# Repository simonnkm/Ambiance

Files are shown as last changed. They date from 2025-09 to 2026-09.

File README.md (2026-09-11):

# Ambiance

Ambiance is a solar-powered scheduled audio playback system built around an STM32 Nucleo development board. The system is designed for remote outdoor use and supports scheduled playback of audio tracks through a speaker system.

The project includes embedded firmware, a desktop GUI, hardware documentation, PCB manufacturing files, and assembly materials.

## Repository Structure

```text
Ambiance/
├── Ambiance-main/        Embedded STM32 firmware and device-side code
├── Ambiance_GUI/         Desktop GUI for UART/Bluetooth control
├── Assembly Materials/   PCB manufacturing and assembly files
└── dist/                 Packaged application output
```

## Main Components

### Embedded Firmware

The embedded firmware runs on the STM32 Nucleo board. It controls scheduled audio playback, button input, OLED menu navigation, Bluetooth/UART communication, real-time clock behavior, device logging, device status reporting, schedule storage, and DFPlayer Mini track playback.

### Desktop GUI

The desktop GUI is located in:

```text
Ambiance_GUI/
```

The GUI connects to the device through UART or Bluetooth and provides controls for:

- Device connection
- Volume
- Duty cycle
- Manual track selection
- Schedule creation
- Schedule import/export
- Sending schedules to the device
- Clearing the local schedule queue
- Clearing the schedule stored on the device
- Downloading device logs
- Clearing device logs
- Checking device status
- Checking device time
- RTC time synchronization and diagnostic testing

The device status request reports whether the device is currently:

- Playing audio
- Off
- In a programmed silence period

The GUI also includes RTC-related controls for testing and diagnostics:

- Automatic time synchronization when connecting
- Force Time Sync
- Skip automatic time sync on the next connection
- Check Device Time

See:

```text
Ambiance_GUI/README.md
```

for GUI installation, usage, and packaging instructions.

### Hardware and Assembly

The hardware and assembly instructions are provided separately as a Word document. That document includes the physical build steps, wiring, DFPlayer Mini file setup, FAT drive sorting behavior, bill of materials, Gerber files, and assembly notes.

Additional manufacturing and assembly files are located in:

```text
Assembly Materials/
```

## OLED Screen Options

The Ambiance device can also be controlled directly from the onboard buttons and OLED screen.

The OLED menu includes:

### Play Track

Used to immediately play a specific audio track from a selected folder.

The user selects:

- Folder number
- File number

The device then sends the selected track command to the DFPlayer Mini.

### Schedule

Used to create scheduled playback entries directly on the device.

A schedule includes:

- Month
- Start day
- End day
- Start time
- Stop time
- Folder number
- File number

A month value of `0` means the schedule repeats every month.

### Set Date and Time

Used to set the device's real-time clock.

The real-time clock keeps the current time so the device can trigger scheduled playback correctly.

### More Options

Used for device-level controls and maintenance options.

This menu includes:

- Duty cycle adjustment
- Next track
- Previous track
- Clear schedule

### Volume Control

The left and right buttons adjust the speaker volume.

## Device Requests and Diagnostics

The GUI can send diagnostic and maintenance requests directly to the connected device.

### Device Status

The GUI can request the device's current operating state.

The returned status indicates whether the device is:

- Playing audio
- Off
- In a programmed silence period

### Device Logs

The GUI supports:

- Downloading logs stored on the device
- Saving downloaded logs
- Clearing logs stored on the device

### Device Schedule

The GUI can clear the schedule currently stored on the device without requiring direct interaction with the OLED menu.

### RTC and Time Synchronization

The GUI provides controls for synchronizing and evaluating the device's real-time clock:

- Automatic time synchronization when connecting
- Force Time Sync
- Skip automatic time sync on the next connection for diagnostic testing
- Check Device Time

These controls can be used to test RTC synchronization and verify the time currently maintained by the device.

## DFPlayer Mini File Numbering

The DFPlayer Mini uses numbered folders and numbered audio files.

Recommended folder format:

```text
01
02
03
```

Recommended file format:

```text
0001.mp3
0002.mp3
0003.mp3
```

Example SD card layout:

```text
/01/0001.mp3
/01/0002.mp3
/02/0001.mp3
```

Folder numbers are used by the firmware and GUI when selecting tracks. File numbers are used to choose the specific audio file inside that folder.

Avoid folder 4, track 7, as this combination does not play correctly. A placeholder file can be used instead.

## DFPlayer Mini FAT Drive Sorting

The DFPlayer Mini reads files based on how they are stored on the FAT-formatted SD card. File order can depend on the order files are copied onto the card, not just the visible alphabetical order shown on a computer.

To keep playback reliable:

1. Format the SD card as FAT32.
2. Use numbered folders.
3. Use numbered MP3 files.
4. Copy files onto the SD card in the intended order.
5. Avoid renaming, deleting, and re-adding files after copying.

Incorrect file ordering can cause the DFPlayer Mini to play the wrong track number.

## Hardware Files

The hardware package includes:

- Gerber files
- Bill of materials
- PCB assembly notes
- Hardware and assembly instructions
- DFPlayer Mini SD card setup instructions
- 3D-printable bracket files

## Firmware Setup

See the README inside:

```text
Ambiance-main/
```

for STM32 firmware setup and flashing instructions.

## GUI Setup

See the README inside:

```text
Ambiance_GUI/
```

for GUI installation, running, and packaging instructions.

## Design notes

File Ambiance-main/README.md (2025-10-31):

# Ambiance Playback Speaker Source

## description
A robust second generation solar speaker meant to play sound tracks on a schedule. This is being produced to help in the study of the interactions wild animals have with human voices. most project specific code is found in the core folder. however sme specific code is used the the STM32_BLE middleware.

## Installation

The project is compatable and tested with a Nucleo WB05KZ v1.1 devboard. There are two methods to download the project onto a board, through the STM32cubeIDE and the STM32cubeProgrammer. To use the IDE 
- first download the repository
- [download STM32cubeIDE](https://www.st.com/en/development-tools/stm32cubeide.html#get-software) from ST. 
- Next select import project. 
- Navigate to the folder with the repository and select the WPSsource folder within
- Next is to set up the micro controller. The devboard should come with 3 jumpers. Set them up so that one jumper is on connector CN 3 from pin 7 to pin 5, the sencond jumper is on JP2 near the devboard buttons, and finally the last jumper on JP1, 5VSTLK. Refer to image below
- plug a USB C cable into the board and into the computer eith the repository
- from there the code can be modified within the IDE and the device can be flashed by hitting the run button in the IDE

NOTE: do not program the device while it is plugged into the accompanying Abiance PCB.

The other method uses the programmer
- first download the repository
- [download STM32cubeIDE](https://www.st.com/en/development-tools/stm32cubeprog.html#get-software) from ST. 
- Next is to set up the micro controller. The devboard should come with 3 jumpers. Set them up so that one jumper is on connector CN 3 from pin 7 to pin 5, the sencond jumper is on JP2 near the devboard buttons, and finally the last jumper on JP1, 5VSTLK. Refer to image below.
- plug a USB C cable into the board and into the computer eith the repository
- open the programmer
- select Port: SWD, fequency 400kHz, normal mode, software reset, and reliable speed
- navigate the the erasing and programming tab on the right
- select Amiance/WPSSourse/WildlifeSource/Release/Wildlifesouce.elf
- select full chip erase and hit start programming

NOTE: do not program the device while it is plugged into the accompanying Ambiance PCB.
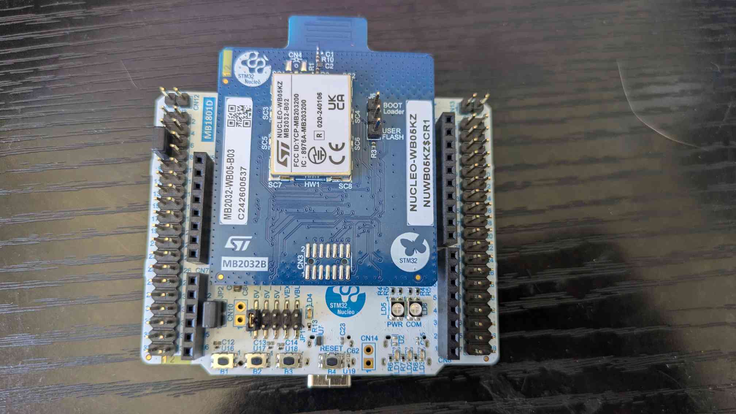
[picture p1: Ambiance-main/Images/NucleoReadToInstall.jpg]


## Using the program

to use the device with the accompanying Ambiance PCB, prgram the device before plugging in. after installation, remove the JP1, 5V_STLK jumper to prevent the computer from failing to power the PCB and swap the jumper from CN3 pin 5-pin 7 to pin 7-pin 8 (refer to image below). power the board with a 4.5-12V. From there the device can be operated with the buttons and OLED or using the accompanying Ambiance GUI through a Bluetooth connection. To use the buttons, each button's purpose is labeled on the PCB where from left to right button 1 is back, button 2 is select, B3 is down, B4 is up, B5 is left, and B6 is right. On the main menu these buttons are used to jump to different menus. Play track is used to immediately play a track from a folder, schedule allow the user to set a time to start playing a track in a folder (note month = 0 means the track repeats every month). Set date and time allows the user to set the time on the power loss resistant real time clock. More options allows the user to adjust duty cycle, move to next and previous songs, and clear the schedule. frinall the left and right arrow keys adjust the volume of the speaker.

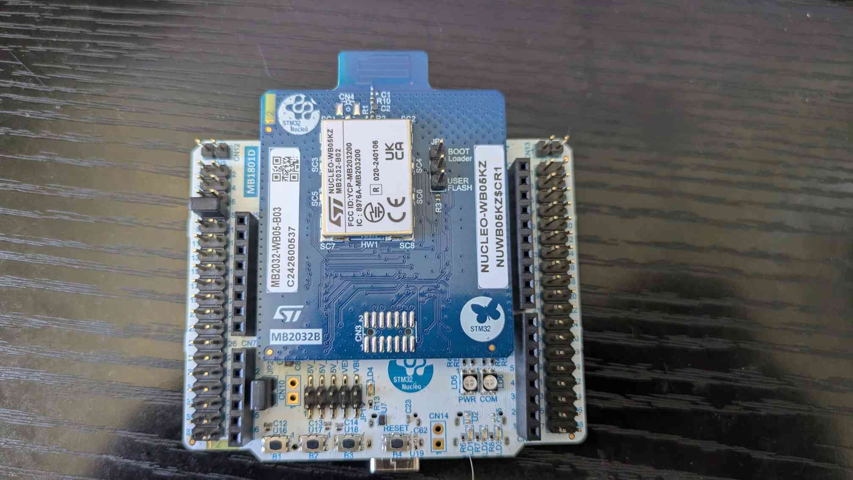
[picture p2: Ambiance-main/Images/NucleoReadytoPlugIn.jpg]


## Support
For support, contact stipix@bonesio.net

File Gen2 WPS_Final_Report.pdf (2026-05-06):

# Wildlife Playback Speaker

University of California – Santa Cruz
ECE 129 Capstone Series
Senior Capstone Report
Bachelor of Science in Robotics Engineering

Prepared by: Caitlin Bonesio, Ramsey Mogannam, Jaspreet Singh

Sponsored by: Mike Kowalski
May 2025

### Abstract

This report summarizes the design, development, and testing of a wildlife playback speaker system aimed at enabling long-duration outdoor deployment for animal behavior research. The system integrates audio playback, scheduling, and energy-efficient operation.

### Table of Contents

1. Introduction
2. Project Purpose and Goals
3. System Overview
4. Key Improvements Over Previous Design
5. Testing and Validation
6. Lessons Learned
7. Conclusion
8. References
Appendices

### 1. Introduction

### 1.1 Project Background

The Wildlife Playback Speaker project is part of the UCSC ECE 129 Capstone Series. The goal is to support ecological field studies by creating a robust, autonomous playback device.

### 1.2 Objectives

Our primary objectives were to achieve reliable audio playback, low power consumption, and a user-friendly interface for scheduling and control.

### 2. Project Purpose and Goals

### 2.1 User Needs/Technical Requirements

Researchers require a device capable of playing pre-recorded sounds at scheduled intervals in remote environments with minimal maintenance. The system must support Bluetooth and UART connectivity, have weatherproof housing, run on battery power for over 24 hours, and support WAV file playback.

### 3. System Overview

### 3.1 Hardware Architecture

The hardware includes a microcontroller, SD card module, audio amplifier, speaker, buck converter, and rechargeable battery system.

### 4. Key Improvements Over Previous Design

### 4.1 Embedded Subsystem

Lead: Caitlin Bonesio

In the previous design, the system utilized an ESP32 microcontroller due to its small size and ability to communicate with the MP3 player. However, this configuration posed limitations in power efficiency, no access to internal flash memory, and stability for Bluetooth Low energy (BLE) communication in the field. To address this, we replaced the ESP32 with the STM32WB05KZ, a microcontroller optimized for BLE applications.

The previous team's software design was never made available, necessitating the current software be built from the ground up. The STM32WB05KZ manages several communication methods, including UART, USART, I2C, Bluetooth, and GPIO communication. The microcontroller (MCU) also handles system logic such as duty cycle control, scheduling, logging, and managing peripherals. All of these features were designed from a software block diagram.

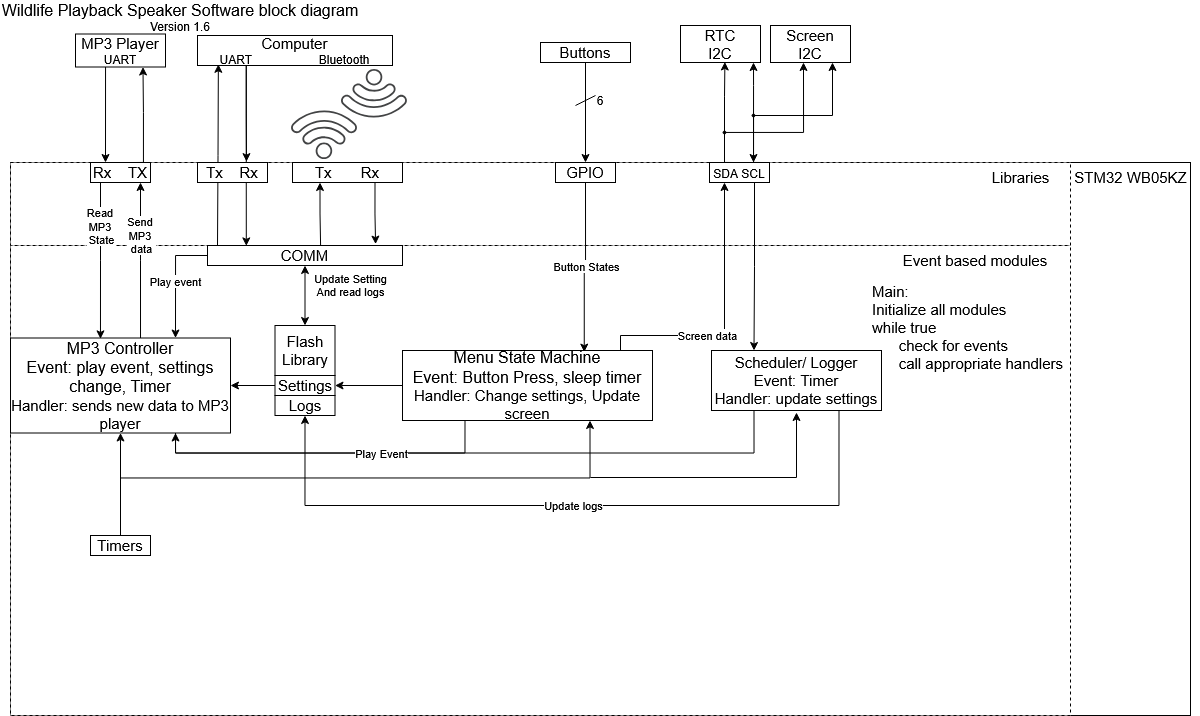
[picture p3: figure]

Figure 4.1.1: Software block diagram

This modular nature is supported by an events and services routine. This allows each module to allow others to run while waiting for an input. This allows for an abstraction that each module operates independently and asynchronously. Each module communicates with each other and themselves through events. Each module has a FIFO queue of events that the updater or other modules can post to. These events are then processed by the module handler.

### 4.1.1 UART

The UART library is used for controlling the internal low power UART and USART module on the STM32. The library has 5 public functions. The first is an initialization to configure the internal peripherals. The read and write functions each interact with their own RX and TX circular buffers, one of each type for the UART and the USART. Private interrupt functions write to the appropriate RX buffer when new data is detected and reads from the appropriate TX buffer when the associated transmit line is available.

The LPUART module is used to send and receive packets to and from the MP3 player to control what it plays. The MP3 player is initialized by sending the restart command (0x0C) then the STM queries the number of tracks in each folder of the MP3 player with the 0x4E command. The MP3 player will either respond with the same query command to indicate the packet data has the number of folders or it returns an error (0x40). Once the STM receives an error it knows that all folders have been scanned. The internal folder map is then constructed and stored on the heap for later. When the STM wishes to play a folder and track, it sends the play track packet (0x03) with the track number being represented by the number of all tracks in all folders previous to the desired track and folder in the folder map. This is done to side step the unreliable play track/folder command (0x0F). Similarly, the repeat folder command is unreliable; to sidestep this the MCU receives track complete from the MP3 to count until it reaches the end of the folder in its internal folder map and sends a play track command for the first track in the folder. This implements the track/folder play and folder repeating requested by the client.

### 4.1.2 USART/Bluetooth

The USART and Bluetooth both handle communication with an external laptop or desktop graphical user interface (GUI) application. The COMM module polls the USART RX buffer for incoming data. The Bluetooth is managed by an STM32 middleware. The Bluetooth is configured to transfer sequences of single bytes to and from the GUI in order to use the same parsing state machine as the USART. It does this with three characteristics: VIRTUAL_USART_TX, VIRTUAL_USART_RX, and VIRTUAL USART_TX_REQ. The TX, and RX are named from the microcontroller's perspective, the data that flows from the MCU to the PC is in the TX characteristic, and vice versa for the RX. TX_REQ is used to make the act of the MCU transfering to the PC atomic. This means the PC must confirm the received data in TX_REQ for the MCU to post more. For the RX characteristic the middleware is directed to post to the COMM module state machine the moment the RX is changed.

The COMM module parses the incoming data packets from the USART and Bluetooth. The packet format the team agreed on was sending a command byte followed by a predetermined number of bytes required to fulfill that command. Some commands require a variable number of bytes to complete, these use a done command to indicate the end of transmission. The predetermined commands are: volume control, folder control, logs request, logs done, duty cycle control, schedule control, schedule end, debug print, debug end, and set time. These implement the ability for the PC to set the volume, duty cycle, schedule and time and implements the MCU’s ability to send the logs and debug text.

### 4.1.3 I2C

The I2C library is used to control the internal I2C peripheral. The library is built to interact with the event based architecture of the system. This means every receive request has an associated post function to post the received data to. This allows the receive functionality to be non-blocking and non-polling. The core of the I2C module is a buffer storing both receive and transmit requests. The buffer can be loaded with receive and transmit requests that will be pulled from by the I2C interrupt. The module uses the HAL i2c memory interrupt functions and callbacks to implement this. The buffer enqueue function has to be able to differentiate between the receive and transmit requests to call the appropriate equations.

The I2C peripheral is used to control the real time clock (RTC) and OLED screen. The RTC is initialized by reaffirming the start bit is enabled and the use back battery bit is enabled. then receive requests are used to read from the registers. The data in the registers are in binary coded decimal (BCD) format. The MCU must convert these BCD numbers into pure binary format. The OLED screen requires far more initialization steps. The display is turned off, then the multiplex ratio, display offset, start line, segment remap, com output scan direction, and com hardware config is set. Then the display is turned on. To control the screen, a UCSC OLED controller library was used. The OLED library required new initialization code, a wrapper function in the I2C library, and the output had to be remapped to flip the display upside down for better ease of use.

### 4.1.4 GPIO

The GPIO library provides initialization to read from the PCBs buttons. The library provides functions to initialize the pins and to poll from the pins. Both functions are wrapper functions for the HAL GPIO functions

The GPIO pins are used for the buttons menu state machine (BMSM). The BMSM uses a state machine to implement a menu for the user to navigate using the buttons. It provides the ability to play certain tracks and folders, schedule upcoming folder changes, set the devices time, seek forward and back, change the volume, duty cycle and clear the schedule. With exception to the main menu, button one is always mapped to back, button two is always mapped to select, button three to move the cursor down, button four to up, button 5 to left, and button 6 to right. By keeping the buttons consistent, it is easier for a user to learn the system.

### 4.1.5 Duty Cycle control

The MP3 module is in control of maintaining the speakers playing duty cycle. This is done by using the free running timer (FRT) from the TIMERS library. The module has the full cycle length predefined. In the initial play state the full cycle length is multiplied by the duty cycle as a percentage and compared against the FRT. When the timer has reached the end of the duty cycle it swaps into the paused state where the FRT is compared to the full cycle length multiplied by one minus the duty cycle. At the end of the pause state it returns to the play state. The module is built to be able to continue from where it left off from pausing.

### 4.1.6 Scheduling

The scheduling functionality is implemented by having the module produce an event every minute to check the RTC. This time is compared to the schedule that is stored on the flash memory. If the current time is within the scheduled time and the MP3 isn’t already playing the same track and folder, the Scheduler module posts a play event to the MP3 controller to change the track and folder. The scheduler is set up like this to be able to recover from a shut down as the start time is missed but the MP3 player should be playing.

### 4.1.7 Logging

The logger module is designed so that the MP3 player forwards all received play events to the logger. When the logger receives a play event, it requests the time from the RTC and appends the log with the track, folder, and time.

### 4.1.8 I2C-USART manager

The system had a design flaw where both the I2C peripheral’s serial data line (SDA) and USART peripheral’s TX line are both mapped to the pin PA1. This conflict required a separate manager library to provide arbitration between the two peripherals. The default state is letting the I2C SDA line control PA1. When the USART library is to transmit, the manager swaps the pin from I2C SDA to USART TX and when the TX buffer empties, the control is returned to SDA. The manager also disables the unused peripheral while it does not have control to prevent data being lost to an unconnected pin. This flaw needs to be fixed in any future interaction

### 4.2 PCB Subsystem

Lead: Ramsey Mogannam

To start the PCB section of this project, I first started with creating the schematics. I first started by creating the schematics for the project. I first started by downloading Capture OrCAD, as that is the program I first used to create the schematics. This is my first time doing a schematics or creating any circuit board. Hence, it has been a huge learning curve and the first trial of the schematics is shown below:-

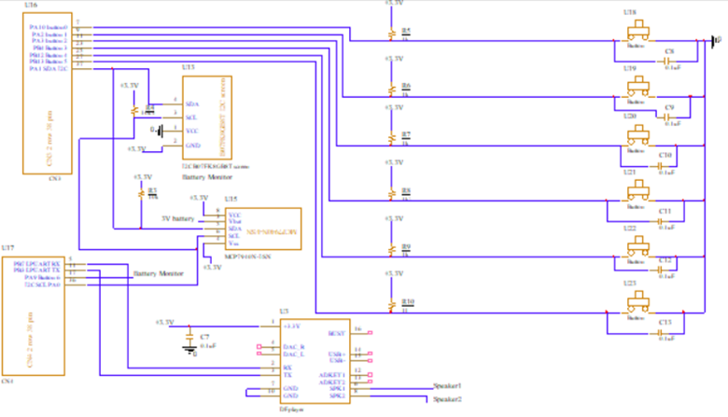
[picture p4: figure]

The buck converter is identical to the one from the first gen design. It is shown in the figure below:-

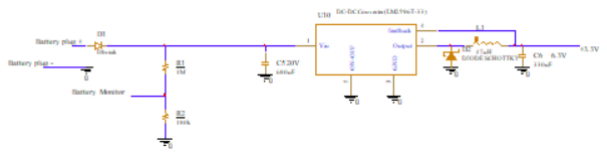
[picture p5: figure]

Since the DC-DC converter was working perfectly, there was no reason to alter or modify it.

After the first trial of the schematics was completed, I tried adding the PCB footprints which is what will be used to create the layout. Here I ran into a lot of technical issues as windows 11 is not compatible with Allegro. Hence, I had to switch to using Kicadd, as a result I had to recreate the schematics using KiCadd. This was beneficial as Kicadd has a library downloaded with all of the components we will be using. To add a footprint, left click on the component and select the assign footprint function. The schematics using Kicadd is shown below:-

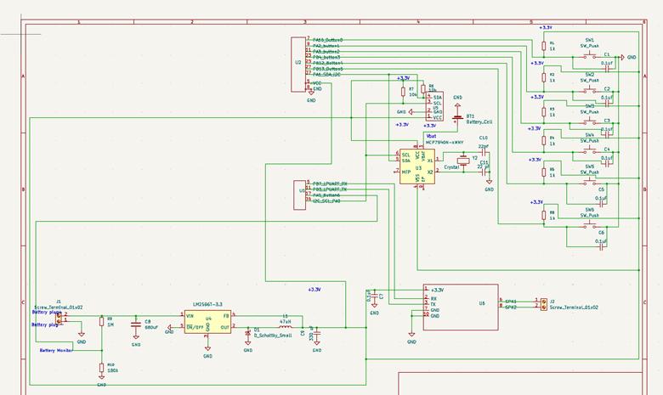
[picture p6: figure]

Some of the pins have been changed, also the power and ground pins for the microcontroller were added. We also proceeded to create the PCB layout for this board. To start the PCB layout, it is very important to setup the constraints on KiCadd. The constraints are shown below:-

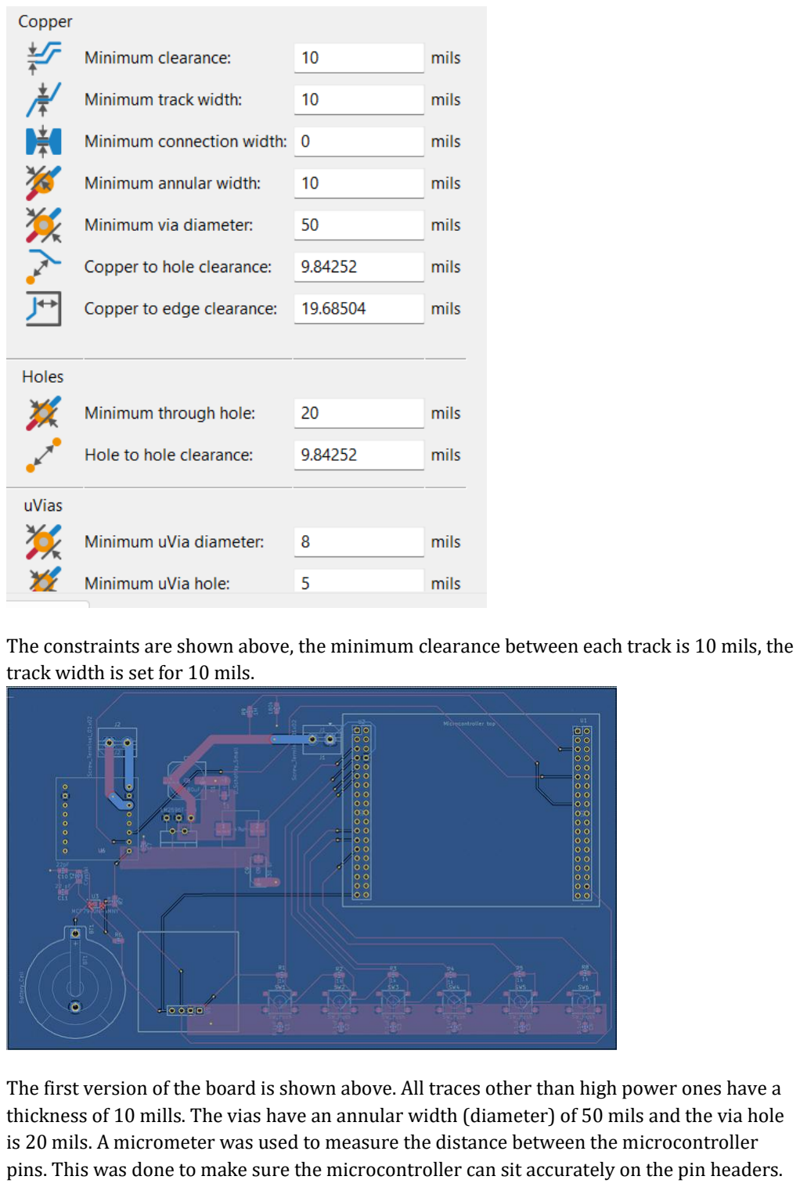
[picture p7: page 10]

The constraints are shown above, the minimum clearance between each track is 10 mils, the track width is set for 10 mils.

The first version of the board is shown above. All traces other than high power ones have a thickness of 10 mills. The vias have an annular width (diameter) of 50 mils and the via hole is 20 mils. A micrometer was used to measure the distance between the microcontroller pins. This was done to make sure the microcontroller can sit accurately on the pin headers.

A copper area was added to the back of the board to create a ground plane. For the high power area, (the area between the voltage input and the LM2596), copper area and a thick trace of a 100 mils was used. This was done as these areas carry a lot of current and that would prevent the traces from getting damaged. We proceeded to mill the board. After the milling is completed the board is shown in the picture below:-

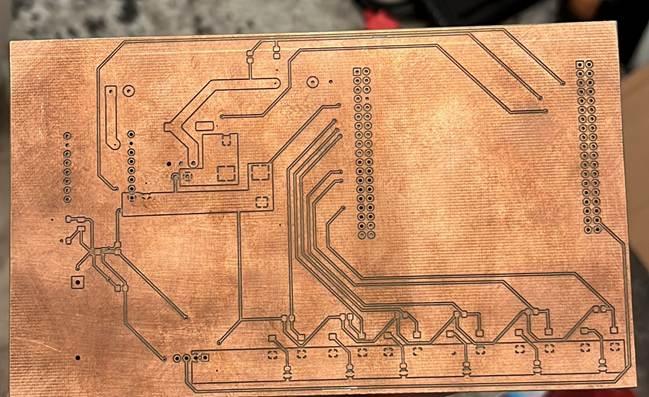
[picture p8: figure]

I proceeded with assembling the board, and it is shown in the picture below:-

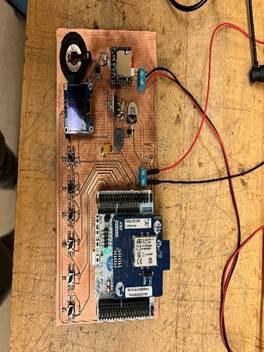
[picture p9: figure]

Testing and Debugging of the first iteration of the PCB:-

It is very important to test the board while assembling it. This was a mistake I did, as I assembled the whole board then proceeded with testing it as one unit. To test the board while assembling check for continuity between pins to make sure the components are not shorting. I ran into an issue where the DC-DC converter was not producing 3.3V, after a few days of testing. It ended up being the diode was installed backwards. To make sure the DC-DC converter is working, measure the voltage on the copper area and 3.3V should be seen. The current draw when the board if working perfectly according to the LM2596T-3.3 data sheet is from 10-40 mA. When the board is connected and powered it draws 15mA, hence, the board is functioning properly. Also, connected an oscilloscope to the output and the result is shown in the pictures below:-

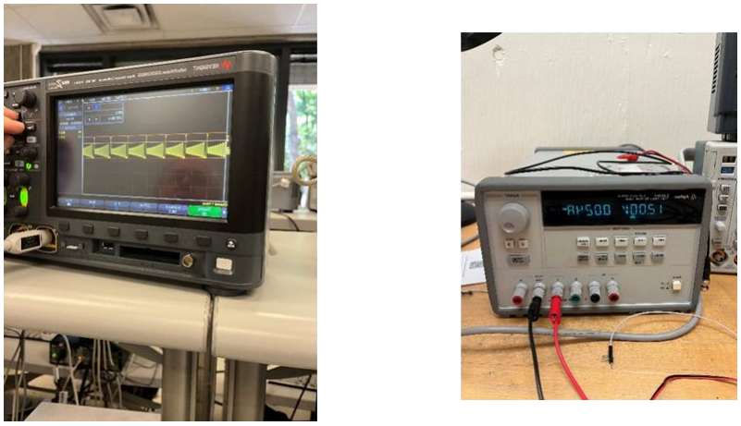
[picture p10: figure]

To test the buttons and make sure they are working, connect the oscilloscope probe the output pins on the pin headers, when the button is unpressed, the output of the oscilloscope should be seen as below:-

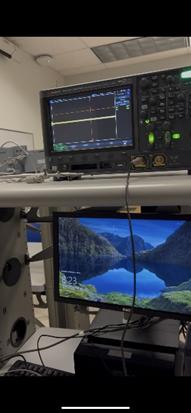
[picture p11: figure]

The output of the oscilloscope when the button is pressed is shown in the picture below:-

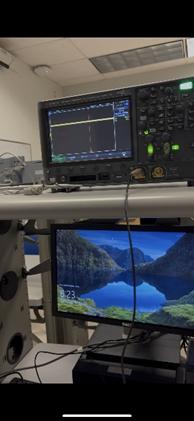
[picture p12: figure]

as seen in the picture above, there is a change in the output of the oscilloscope which shows that the button is working properly.

Technical difficulties:-

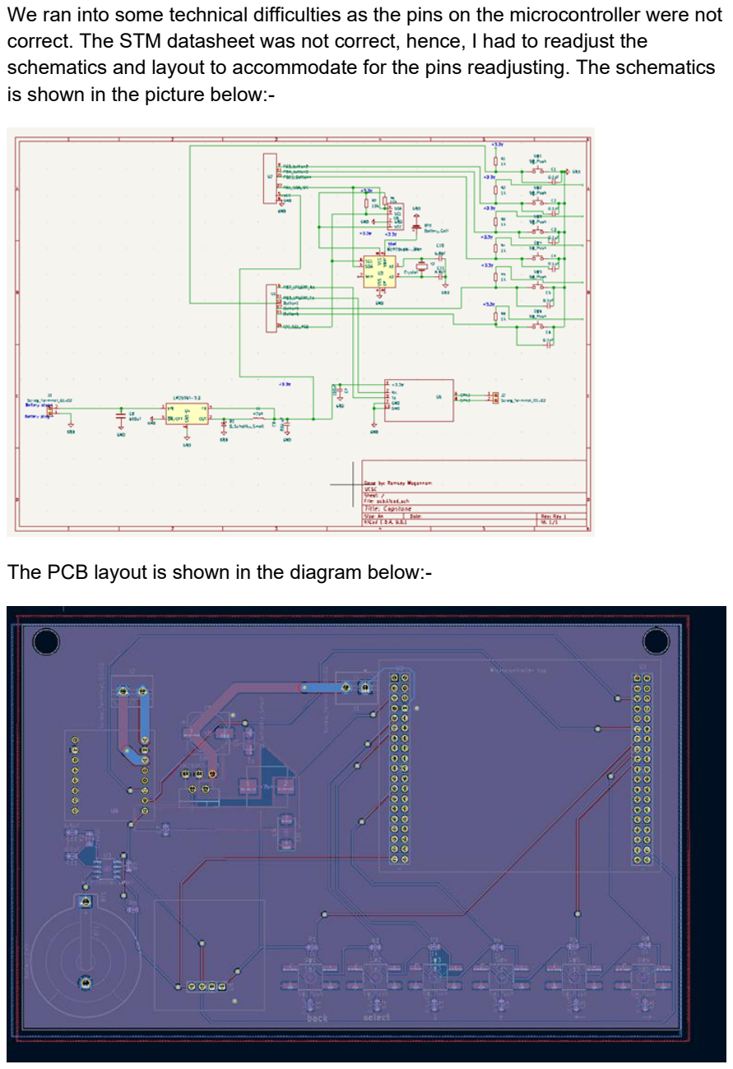
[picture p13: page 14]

We ran into some technical difficulties as the pins on the microcontroller were not correct. The STM datasheet was not correct, hence, I had to readjust the schematics and layout to accommodate for the pins readjusting. The schematics is shown in the picture below:-

The PCB layout is shown in the diagram below:-

I also proceeded with adding a copper area for the ground plane on the front. Capacitor values for the Real Time Clock(RTC) were changed to 6.8pF(C10,11). This was done as the RTC was skipping time and losing about 3 minutes every hour.

PCBWay:-

As per clients request, we proceeded to get the board manufactured by PCBWay, it costed around $7 per board. To manufacture and assemble a board it costs $40 with components. I created a Bill Of Materials (BOM) and choose all the components desired to assemble the board using Digikey parts. A picture of the BOM is shown below:-

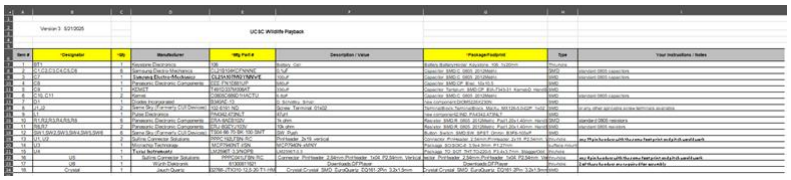
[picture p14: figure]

Since manufacturing and assembling the board requires a lead time of 30 days, I proceeded to order the board without assembly. After a few days, I received the board unassembled and proceeded with assembly. A picture of the board after assembly is shown below:

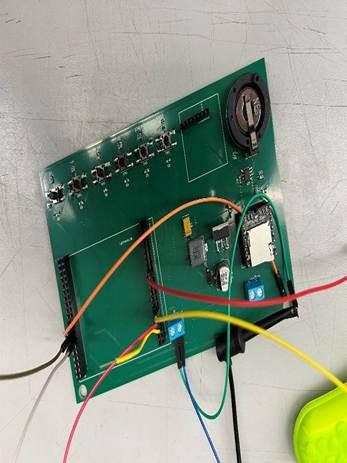
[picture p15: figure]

Testing:-

I tested the board the exact same way I tested the first iteration of this PCB, and this board works perfectly.

PCBWay DFM:-

I proceeded with uploading the final PCB after testing it with the BOM to
PCBWay so that the client can proceed with ordering all 40 boards that he needs to complete his project.

Lessons learned and challenges faced:

Creating the PCB has been a huge learning experience since I have never done a PCB design before in my life. I faced a lot of challenges with understanding the design standards for PCBs. I learned how to design a PCB. In addition, I faced a lot of challenges with debugging the PCB. As a result, this taught me a lot on how to debug circuits and how to utilize oscilloscopes. I faced a lot of challenges with relaying on the datasheets since it was proven that some of the datasheets were inaccurate. This taught me to not trust a datasheet and to test and verify that a datasheet is accurate before designing the PCB.

Future work:-

I will be editing the PCB layout to make it smaller, so that it can fit better on the battery mount.

### 4.3 Mechanical Subsystem

Lead: Ramsey Mogannam

The client reported that there were numerous issues with the first generation design of the box. The box was not waterproof, there was water leaking from the wire glands and the speaker present on the box. Client has also mentioned that the battery was not secure and it caused damage to the PCB as it was moving around. Client also mentioned there is a lot of resonance present in the box in tracks with high frequency noises. After noting all of these issues, I proceeded with testing the waterproofing on one of the old box to confirm that the wire glands and speaker were leaking.

Testing of old box:-

After getting an old box from the client, I proceeded with using a hose to simulate rain and it was confirmed that the wire glands and speaker were the source of the leak. I then proceeded to take

the old box apart to understand why the waterproofing failed. I found a few reasons why the

glands were leaking. First of all, the glands were missing o-rings, and the wrong size glands were

used. PG11 glands were used which are too big for a 5mm wire. Also, the holes drilled in the box

were not drilled correctly, it seemed like the drill was not held straight when the holes were

drilled which caused the box to form a bad seal.

Fixing the waterproofing on the box:-

To fix the waterproofing on the box, I proceeded with ordering a new box and building a new case the right way.

Step 1:-

Order the box, the box used during this project is the 230 Meduim Tactical Case, which can be found on amazon using the link below:-

https://www.amazon.com/Seahorse-Medium-Tactical-Case-Black/dp/B06ZXXX29F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 VxUIxrtVZzi-vkNTomRZYBtTFdEObxXpFrNT3vrWZB7iLgJNdYIrK1EX-ujiBhPSNZ1-qaQEpjHKlV-hYU5cegBaS0Y4BHiUZXjGUIxt57EKIVjS1r0PVyEepXQOL2jXZ70yC6nsEdgmCcRvtmb-jhgEM.J3bkg6NE6dIjuSlAMyYC_80nRKuuFwXQ5gWYShiQIjU&dib_tag=se&keywords=Seah orse+230&qid=1740781420&sprefix=seahorse+230%2Caps%2C182&sr=8-3 (https://www.amazon.com/Seahorse-Medium-Tactical-Case-Black/dp/B06ZXXX29F)

Step 2:

To start with manufacturing the box, locate the wiring glands. Since the wires we are using have a thickness of 7 mm. Since the thickness of the wire is on the lower threshold of PG7 which has a tolerance of 3mm-7mm. To drill the holes for the glands, measure 2” from the corner of the box. Then, use a drill with a bit size of 5/16. I made sure to use a drill bit that is a bit smaller than the size of the wire gland. It is very important to keep the drill straight to make sure that the glands won’t leak. A picture of the drilled holes is shown below:-

Step 3:

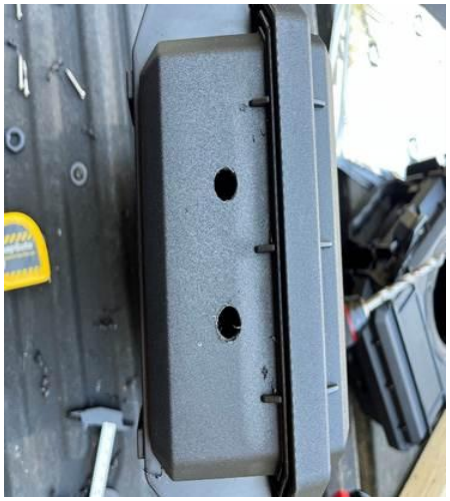
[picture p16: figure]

For the third step, we will be using a tap set to tap the case. This is done to make sure to eliminate any water leaking into the box. The tap size I used is 7/16, before installing the wire glands, make sure to thread sealer on the threads of the wire gland. Adding a small dot on the threads of the wire glands is more than enough. Refer to the diagram below for a detailed picture on how it should look. After the sealer has been applied, thread the wire gland in, and make sure to add both O-rings on both sides of the wire glands and install the nut. Install the wires, with making sure to add the rubber gromets and stoppers to make sure the wire doesn’t back out on its own. Use two adjustable wrenches to tighten the gland, be careful of over tightening the nuts and the wire glands as it can break the case or the gland. Wait a few hours to let the thread sealer dry before moving to step 4. Pictures of this step are shown below:-

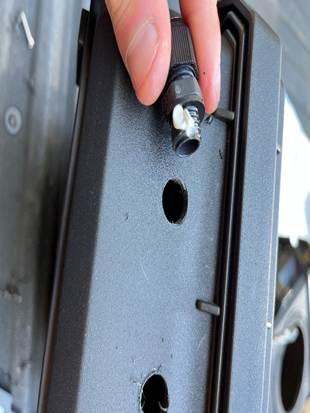
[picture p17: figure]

Step 4:

Make sure to use black RTV(automotive gasket maker that is heat resistant) and will withstand the weather conditions of the testing grounds. Use wire cutters to cut the end of the RTV tube at a 45 degree angle. Make sure to cut it very close to the edge of the closed RTV tube so that the bead won’t be too thick. I spread a layer of the RTV around all the wire gland, and then made sure to spread it with my finger to confirm a tight seal around the glands. A picture of the final product of the glands is shown below. Leave the box for a few hours under direct sunlight to let the RTV cure.

Step 5:

In this step, we will be using the automotive sound insulation. This is important because the first generation of the box had a lot of resonance in some soundtracks. To fix this issue, automotive insulation will be applied to all of the insides of the box. I first started with the bottom section of the case. It is very important to clean the box using isopropyl alcohol and a lint free rag to make sure the surfaces are oil free. Wearing gloves is necessary when cleaning and handling the insulation to avoid any oils from our skin transferring onto the box. To install the insulation, peal the adhesive off the back of the insulation and use a roller to install it. Make sure to press very firmly on the roller to make sure the insulation is secure. Since the insulation is very flexible, it can be installed on the sections of the box and an exacto blade was used to cut all the access material. I repeated this for all of the sides of the box the dimensions are shown in the pictures below:

Step 6:

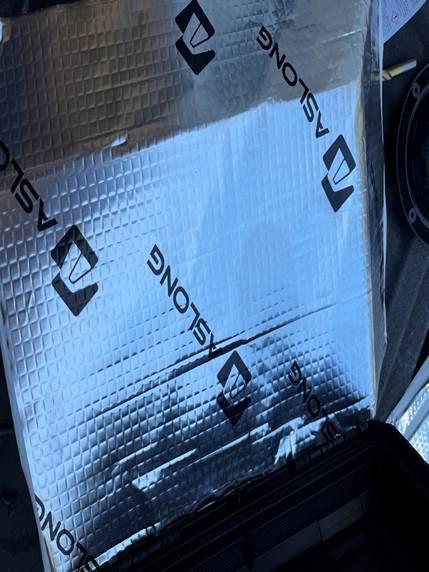
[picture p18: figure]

In this step we will be cutting the hole for the speaker and mounting it. To cut the hole for the speaker, use a hole saw bit with a size of 4”. It is going to be a bit difficult to cut through the insulation, if it gets stuck make sure to reverse the drill direction and then reverse back. Having a high RPM drill here is a life savor! To mount the speaker, the provided gasket can be used. I used RTV as I felt like it was more secure. Either way works, but make sure to add a bead of RTV on the bottom of the speaker as shown in the picture below to make a good seal. Add screws in the speaker to mount it. Make sure to hold the speaker down to avoid any movements in the speaker itself. I waited a few hours to let the RTV dry then I added another layer of RTV all around the speaker. Pictures are shown below:

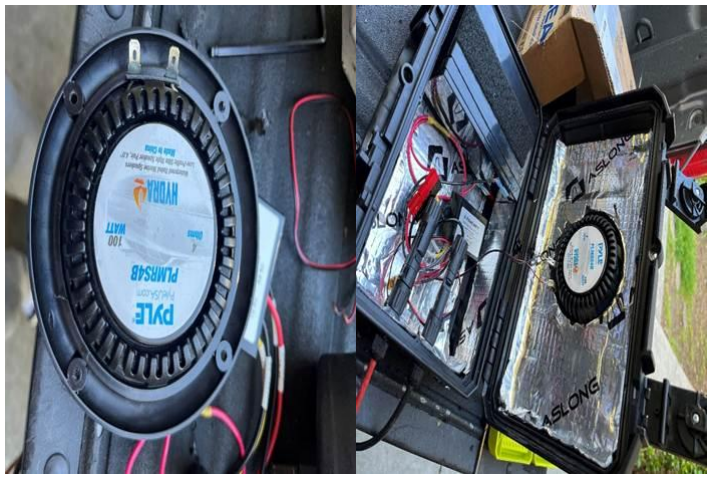
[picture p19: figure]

Step 7:

In this step, we will be working on testing the waterproofing of the box. Since the boxes aren’t the best quality. Some of the boxes are not fully waterproof. To prevent any damage to components from happening, we will be testing the waterproofing using a hose. It is very important to make sure the silicon and thread sealer is completely dry before any testing.

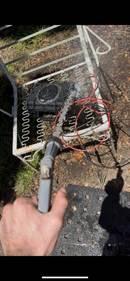
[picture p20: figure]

Step 8:

I started by adding Velcro on the bottom pieced of the box to mount the battery and the AC-DC converter from the solar panel. Make sure to mount it in the center far from the edges as the battery mount will be taking up that space. Then, I proceeded to use zipties to hold all the wires in place.

Battery Mount:-

I finally proceeded with starting to create the mount for the battery using Onshape. The mount is a very simple design, and it is shown in the picture below:

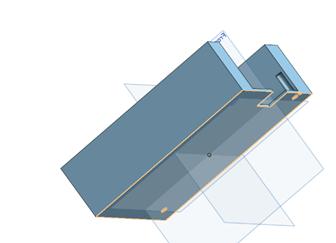
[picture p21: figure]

The mount has two holes integrated into it, which the user can decide to install an M3 thread insert or use a self-taper screw to install the PCB on the mount.

Challenges faced and lessons learned:-

I faced a challenge of finding the best way to make the box waterproof, this taught me a lot about wire glands and waterproofing. I also learned how to use On shape, as I have never used it before, I always used SolidWorks.

### 5. Testing and Validation

### 5.1 Unit Testing

All subsystems—audio, scheduling, power, and GUI—were tested individually for expected behavior and performance.

### 5.2 System Testing

Integrated system testing was performed to verify correct execution of scheduled playback and long-term power reliability.

### 6. Lessons Learned

### 6.1 Challenges Faced

Initial power regulation caused unexpected resets. Debugging UART communication with Bluetooth modules also required extensive testing.

### 6.1.1 Embedded systems

The most consistent issue the embedded systems team encountered was poor documentation for parts. Three of the required datasheets had false or misleading information. The first was the datasheet for the Nucleo dev-board housing the STM32. Repeatedly the team has had the datasheet claim one of the external morpho connecter pins were connected to a certain internal port or peripheral, only for that to turn out to be false. This led to a distrust in the datasheet leading to the team's greatest mistake: assigning both the USART TX and I2C SDA to the same pin. Eventually the team found the answer to the poor nucleo documentation: the schematic. The schematic allowed the team to cross reference the exact wiring inside the dev board allowing quicker progress. The second misleading datasheet was for the MP3 player. The MP3 player had many of its functionalities perform completely different from what the datasheet claimed. The most telling is for the commands that can be sent. For example, the command that was claimed to repeat a folder would only intermittently repeat a single file. On top of this, many functions were obfuscated and only available through third party arduino libraries. The only way around this was trial and error and sidestepping non-functional commands. The final case of poor documentation was the I2C OLED screen. This screen only has the datasheet stores with incorrect header and unavailable in all sites that allow its purchase. The team had to find it through an internet search, and are still unsure if it is the correct datasheet. This datasheet provided a non-working initialization sequence and failed to provide the correct driver chip for the OLED screen. The only way to solve this problem was trial and error.

This project constituted the first time we had built an I2C library; this came with many difficulties. Our first idea was to implement the library like a UART library with an RX and TX circular buffer. This caused many issues with providing arbitration on which buffer was allowed to use the peripheral. Any failed arbitration attempt would permanently lock up the I2C module. While there may have been a way to prevent all arbitration failures, it proved easier to restructure the library to have one I2C buffer that holds both receive requests and transmissions. This meant the request packets had to hold either a receive request or a transmit request indiscriminately. This created issues where the requirement to hold an unused pointer to the post function on every transmit request used the entire system memory. The large transmit buffer size was required by the OLED screen. The solution to this problem was to implement one pre-defined list of function pointers that can be configured at compile time, then have each packet only hold the index the function is at. the greatly reduced the number of bytes each packet needed from 12 bytes to 4 bytes. This allows the buffer to be able to hold all RTC receive requests and nearly one and a half screens of OLED data.

The final lesson learned was to test early and test often. The embedded system had difficulties testing the components until the PCB was done. This could have been remedied by testing the code early with a bread board and dummy parts. This would have allowed more confidence in libraries and knowledge of issues and bugs earlier in the process. For example, the I2C module had arbitration issues with the RX and TX buffers that were unknown until the PCB was completed. Having the issue be found so late forced hacky solutions. This takes the shape of the defined pointer list, a far more elegant solution would be to have a hash table to store pointers given by code. however this would require early knowledge to develop and test the hash table library. Many other systems followed this same path of developing a library without testing it and finding issues far too late into development to implement the cleaner solution.

### 6.2 Future Improvements

Future iterations can improve housing ruggedness, add solar charging, fix the double use of pin PA1, and allow real-time logging via a mobile app.

One issue that must be addressed in future iterations is the double mapping of the STM’s pin PA1. This issue was found too late into development to solely get a new version of the PCB to fix it. This bug necessitates that the GUI be robust to garbage data and the MCU to slow down to swap between the functionalities. Because the issue was found late, the solutions are rushed and prone to bugs that break both the USART and Buttons Menu. We are lucky that we implemented so many backups to operating the system as in case of USART and Buttons menu failure, the Bluetooth can still be used

### 7. Conclusion

### 7.1 Summary of Accomplishments

We successfully developed and tested a deployable wildlife playback speaker system that meets all core project requirements.

### 8. References

[1] Texas Instruments. LM2596 SIMPLE SWITCHER® Power Converter Datasheet. https://www.ti.com/product/LM2596
[2] STMicroelectronics. STM32WB0 Datasheet and Reference Manual. https://www.st.com/en/microcontrollers-microprocessors/stm32wb-series.html

[3] University of California, Santa Cruz. ECE 129 Capstone Guidelines. UCSC Engineering Department, 2024.

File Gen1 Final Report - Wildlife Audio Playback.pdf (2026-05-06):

UNIVERSITY OF CALIFORNIA
SANTA CRUZ

ECE 129 Capstone Series

WILDLIFE AUDIO PLAYBACK

Senior Capstone Report Submitted in Partial Satisfaction of the Requirements for the Degree of

Bachelor of Science

in

ELECTRICAL ENGINEERING

by

Aiden Krauss, Liam Magee, Kamran Pakravan, and Cole Quinlan

Sponsored by: Mike Kowalski

June 14, 2024

## Table of Contents

Abstract
This senior capstone project aims to create a device that will be used to study the effects of human disturbances on large fields in Central Africa using grid-style audio playback experiments. This project was proposed to the team by UCSC Environmental Studies graduate student Mike Kowalski, who was searching for students to redesign audio playback devices he created and attempted to use in the summer of 2023. The redesigned audio playback device addresses issues Mike faced last summer by incorporating features including extended battery life, field-adjustable settings, solar charging, and robust environmental protection. The new device created by this team will allow Mike and other environmental scientists to obtain new data on wildlife’s reaction to human disturbances and potentially influence policies for managing multi-use landscapes and conservation areas.

# 1 Introduction [Aiden / Liam]

### 1.1 Motivation

As a single species, humans have the greatest impact on the planet - we have altered over 3/4 of the Earth's surface, changed the global climate, and modified our local environments to suit our needs. Most would consider human disturbance to be a primarily negative force on wildlife across the globe. In reality, there are various forms of human disturbances. Repulsive and lethal disturbances include (but are not limited to) deforestation, pollution, urbanization, and overexploitation of wildlife. Activities such as hunting regulation, non-invasive research, and noise management can prove to have a neutral impact on wildlife. However, disturbances such as habitat restoration, supplemental feeding, sustainable agriculture practices, and conservation and protected areas can be attractive and beneficial to the wildlife involved.
In particular, protected and wildlife conservation areas have been often viewed as having numerous positive impacts on wildlife. These types of areas preserve natural habitats, support endangered species, conserve the natural ecosystem, and promote education and awareness of positive disturbance practices. These types of areas are commonplace in Central Africa countries, where 25% of their northern savannahs are protected areas, but are being increasingly encroached upon by settlements and livestock grazing [1]. The growing population of Africa and the invasion of these landscapes causes them to convert to multi-use landscapes. Multi-use landscapes do not follow the same policy as conservation areas, and allow for the degradation of habitat, cause stress and harm to the wildlife within them, and increase in extinction risk of particular species.
As more and more of these areas change, there becomes an increasing demand to study the effects of human behavior on the wildlife being invaded. Our project, in particular, is to observe the impacts of human disturbance on large felids in Eastern Africa, as well as the broader ecosystems involved. Observing the reaction wildlife has to our human disturbance can reshape the policies of multi-use landscapes and how they are managed moving forward. To do this, grid-style audio playback experiments are the most practical way to simulate human presence without causing harm to the wildlife being studied.

### 1.2 Background

The concept of grid-style audio playback experiments to observe wildlife behavior was presented to the team in a Fall quarter presentation in ECE 129A by UCSC environmental studies graduate student Mike Kowalski. He drew inspiration from the Santa Cruz Puma Project, which conducted similar experiments on mountain lions in the Santa Cruz Mountains. These types of wildlife observation experiments involve using this speaker grid system in conjunction with telemetry collars and game cameras to observe large felids' behaviors, as shown in Figure 1.2.a.

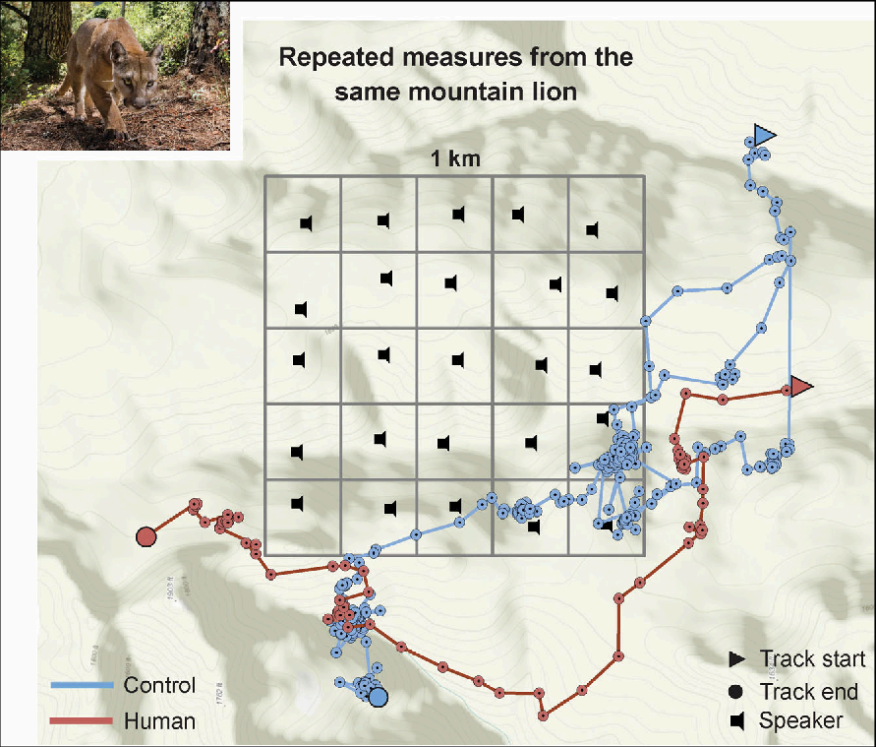
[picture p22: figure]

Figure 1.2.a: Previous experiment playback grid by the Santa Cruz Puma Project observing mountain lion reactions to human and frog noises. Suraci et al., 2019.

Mike had previously conducted a similar experiment to the one shown in Figure 1.2.a Uganda during the summer of 2023 to observe the behaviors of lions and leopards. He set up a 16 square kilometer grid in the savannah consisting of 25 speakers and 12 game cameras, attempting to gather data on the felids’ reaction to human disturbance. The speakers used in his experiment played three different sound treatments: human, cattle, and a control (frogs), each at 80 dB SPL at one meter. The three treatments contained ten tracks, with five randomized orders of those tracks spread amongst the 25 speaker systems. The treatments played at a forty percent duty cycle, meaning a five-minute track would play followed by seven and a half minutes of silence. The devices Mike used to perform this experiment consisted of a six volts and five amp-hours sealed-lead-acid battery, an MP3 player, a DC-DC step-down converter, a waterproof speaker, and a waterproof Pelican Case as shown in Figure 1.2.b below:

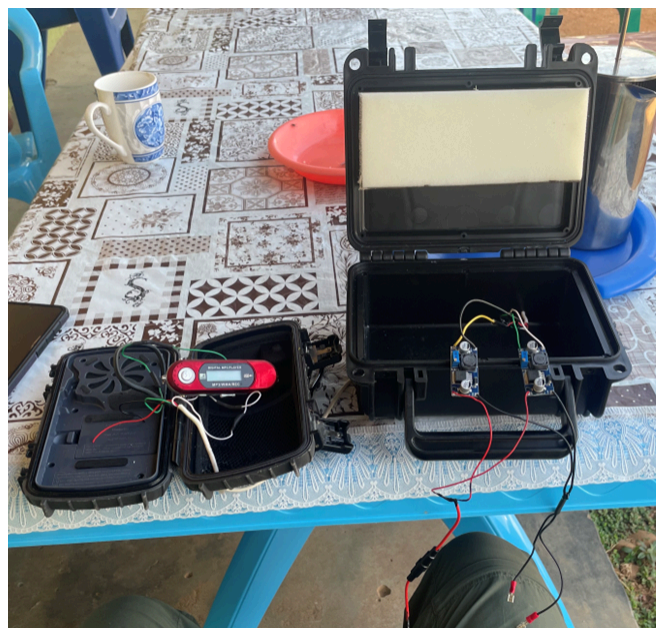
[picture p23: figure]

Figure 1.2.b: Mike’s playback speaker design used in his 2023 experiment in Uganda.

When Mike attempted this experiment, he ran into several problems getting his device to function properly. The most prevalent issue encountered was a short battery life of around ten hours, making it nearly impossible for him to replace all the batteries frequently enough to keep the grid functioning. This also required Mike to disturb the wildlife when changing the batteries, obscuring the data gathered. Batteries also overheated during the experiment due to the strong African sun, and animals damaged the devices by chewing exposed wires, rendering him unable to conduct his experiment and gather the necessary data for his research. Another less impactful, but still important issue Mike ran into was that silence was hard coded into the audio treatments, meaning there was only a single track as a treatment, so he could not adjust the duty cycle of the speaker output. He also could only store one audio file on each cheap MP3 player, which made it inconvenient to change the treatment because he would have to go out into the field and change the MP3 itself. An unsuccessful experiment caused by these numerous issues called for a complete redesign of the audio playback device.

# 2 Wildlife Audio Playback Device [Aiden / Liam / Kamran/Cole]

### 2.1 Project Deliverables

The solution to Mike's failed experiment was to redesign and build upon the previous design to account for all issues encountered during his first trial, as well as anticipate more that may arise. To achieve this, Mike presented us with several deliverables. These included:

1. A minimum of seven days of battery life to prevent the need to interrupt the experiment and change the battery in the field.
2. The ability to conveniently change the audio volume and treatment parameter in the field without significant disassembly or tools required.
3. 80 dB Sound Pressure Level (SPL) audio output at one meter from the device.
4. The capability to withstand the harsh environment of Kenya, including dust, rain, wildlife, and unwanted tampering of the device.
5. A lightweight and compact design for portability and the ability to be conveniently mounted in trees.
6. The ability to upload a minimum of three treatments containing ten audio tracks, with a total of thirty tracks.

To achieve these, the team came up with several solutions in collaboration with Mike. Our first was a higher quality battery with a higher energy density and resilience to heat encountered while inside the box for extended periods. Solar panel charging capabilities were also chosen to allow the battery to recharge during the day, extending the life of the battery indefinitely. To address volume and treatment adjustment, we implemented a microcontroller with three buttons connected to allow the user to raise and lower the volume and scroll through treatments available. The microcontroller would also have sleep modes programmed in to sleep in between tracks being placed, vastly reducing the amount of power used during its duty cycle. An MP3 Player with a maximum of 32 GB of storage was connected to this microcontroller to provide ample space for treatments and tracks in the device. Finally, a lightweight, robust casing, following NEMA Enclosure Type 4 Standard was chosen and painted in a light, natural color to withstand the environment of Kenya and blend into the surrounding foliage [2].

### 2.2 Proposed Design

Our proposed design followed the block diagram shown in Figure 2.2.a below:

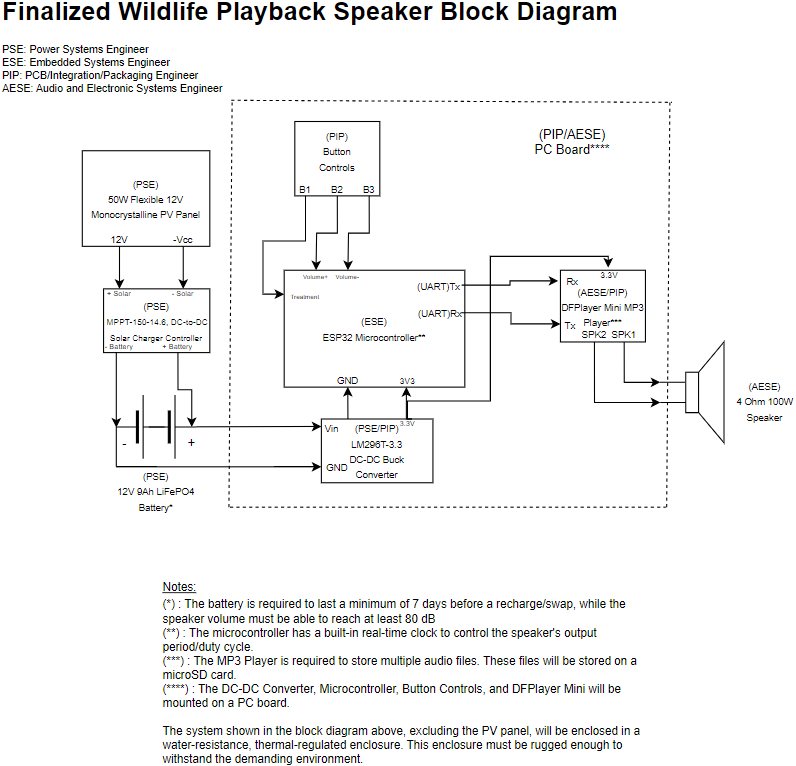
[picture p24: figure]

Figure 2.2.a: System Level Finalized Block Diagram of Audio Playback Device.

The design shown above consists of four main subsystems: Power System, Embedded System, PCB and Packaging System, and Audio and Electronics System. The Power System is primarily focused on delivering a device battery longevity of more than seven days. To do this, a 50W 12V monocrystalline photovoltaic panel is used to charge a 12V 9Ah LiFePO4 battery, which is controlled by a Maximum Power Point Tracing 150W 14.6V DC-DC solar charge controller. The battery is connected to an LM2596T-3.3 DC-DC buck converter switching regulator to step down the nominal voltage of 12V from the battery to 3.3V to power the rest of the circuit. The embedded systems are focused on delivering user adjustability of the device and controlling the audio output periods. To accomplish these requirements, the device is controlled by an ESP32-S3-WROOM-1 microcontroller which uses its ADC pins in conjunction with its serial communication pins to control the treatment being played and the volume of the device. Physical buttons are used with these microcontroller functions to allow user adjustment of the device. The audio and electronics system is responsible for delivering an audio output of 80 dB SPL with client-approved audio quality and sufficient audio storage for 3 treatments containing 10 tracks each. To fulfill these requirements, the audio files are stored on a 32GB micro SD card on the DFPlayer Mini MP3, which supports up to 100 folders, each supporting up to 255 audio tracks. The microcontroller uses its UART communication pins to control when the MP3 player is playing, adjust the volume, and change audio treatments/folders. The MP3 Player contains a 3W audio amplifier that drives a 4Ω 50W RMS waterproof high-sensitivity speaker. The PCB and Packaging system is responsible for providing electronic component integration on a printed circuit board and ensuring that the device can withstand the local climate where it will be used. The button controls, microcontroller, buck converter, and MP3 player are mounted on a 2.5” x 4” printed circuit board. The PCB, battery, and charge control are contained in a 10.6” x 6.1” x 3.9” NEMA Type 4 Enclosure protective case with the speaker mounted on the top side of the case.

### 2.3 Validation of Requirements

To implement our design requirements, we provided several options of solutions for each, which was then narrowed down based on testing and review by our client Mike. The final design decisions that met our design requirements are as follows:

For deliverable 1, multiple tests were conducted to ensure that our device would last the intended amount of time. The first validating test conducted was a full system test. For this test, we connected the battery to our finalized device. We then played the human noises track at a duty cycle of 60%. The reason the human noise track was played was because it consumes the most power. This track was run at a duty cycle of 60%. From this test, our device was able to last 6 days, which is one day under our 7-day goal. However, this test was run at a 60% duty cycle instead of Mike’s desired 40%, and did not include the solar panel. Solar panel testing was also conducted and showed that with a solar panel, the battery could be fully charged in 2 hours when there was a UV rating of 7. Under full load, the solar panel was able to charge a battery on days with a UV rating of 4 or higher. In Kenya, the average UV rating during July, August, and September (deployment dates) is 5. This means that as long as the device has one day with a UV greater than 4, it will recharge. With a solar panel, the device can last significantly longer than 7 days, meeting our deliverable. For more information on this deliverable, refer to sections 3.1.4 and 3.1.5.

For deliverable two, requiring the ability to change volume and track selection without significant product or code disassembly was satisfied by the integration of external buttons into the device in the embedded system. The microcontroller converts digital inputs from the external buttons and translates them into commands from the board to the MP3. Users can then use button 1 to change tracks, use button 2 to increase the volume, and use button 3 to decrease the volume.

As for deliverable three, requiring an 80 dB SPL audio output level, we used an SPL Meter to record each of our treatments maximum and average dB levels. We verified that each treatment reached a maximum of 80 dB and above. The average dB level was recorded for interest purposes, despite the deliverable only asking for the ability to reach 80 dB. Shown in Table 2.3.a below are the measured average and maximum audio levels of the three treatments:

Measurement | Control (birds) | Human Voice (Swahili) | Cattle
Average (dB) | 69.1 | 76.6 | 64.9
Maximum (dB) | 87.7 | 83.5 | 81.2
Table 2.3.a: Measured Average and Maximum Audio Levels of Control, Human Voice, and Cattle Treatments

For deliverables four and five, requiring a robust, lightweight case that is portable and can withstand the harsh environment of Kenya, we found a case that follows the NEMA Type 4 Enclosure Standard. The Standard for NEMA Type 4 Enclosures states that “Enclosures constructed for either indoor or outdoor use to provide a degree of protection to personnel against access to hazardous parts; to provide a degree of protection of the equipment inside the enclosure against ingress of solid foreign objects (falling dirt and windblown dust); to provide a degree of protection concerning harmful effects on the equipment due to the ingress of water (rain, sleet, snow, splashing water, and hose directed water); and that will be undamaged by the external formation of ice on the enclosure. [2]” After extensive research, we found a case that was verified to comply with this standard. The most important aspect of the standard was the degree of protection from the ingress of water, so we opted to test this by spraying our device with a shower hose. We found after twenty seconds of direct spraying on all sides that no water was allowed into the device, meeting our requirement. We chose a size based on the dimensions of each of our components, to ensure each fit with ample room to not come in harmful contact with one another, while still keeping the size as low as possible. The only issue we ran into was color, as we could not find a case that came in a natural color such as green or tan that was the right dimensions to mount all of our components to. Our proposed solution suggested by the client regarding this issue was to repaint it a tan color. Holes were drilled into the sides to allow for the mounting of a python lock, which would be used to mount the case to trees as well as prevent unwanted tampering.

For deliverable six, requiring the project to have the ability to have at least three treatments containing ten audio tracks, the DFPlayer Mini MP3 Player was selected to store and play the audio tracks. The DFPlayer Mini can store up to 100 folders/treatments, each folder with each folder able to hold up to 255 audio files. Treatments can be uploaded onto a micro SD card and then inserted into the slot on the DFPlayer Mini, making it a simple and modular design with ease of changing audio treatments and tracks if needed in the field.

# 3 Subsystems Design and Verification

### 3.1 Power Systems [Kamran Pakravan]

### 3.1.1 Power Systems Introduction

The power systems engineer is a crucial role that must be adequately fulfilled to ensure the success of this project. The role of the power systems engineer for this device was given to Kamran Pakravan. The power systems engineer is in charge of designing a power system that will effectively meet the power needs of the project. In the case of this project, the client-specified requirement of the power engineer is to ensure that the final device can run a minimum of 7 days at a duty cycle of 40%. The power system must also be resilient enough to withstand the conditions of the deployment environment in Kenya.
Tackling this problem took place through analyzing the underlying issues of the previous prototype produced by the client, Mike, and addressing them. Once the issues had been found, research on the most optimal power components was conducted, and engineering standards were analyzed to ensure that the components selected met performance and quality standards.. Once the research was completed, the power engineer moved on to the component selection process. A power budget was then created to effectively map out the power consumption of each component inside the device. The power budget was then used to calculate an estimate for the maximum runtime for our device based on the power consumption of each component. Once this estimate was found, testing ensued. Testing consisted of individual parts testing, subsystem prototype testing, and full system testing. From testing, we were able to conclude that our system would realistically last as long as the client desired.

### 3.1.2 Component Research, Selection, and Testing:

:

Figure 3.1.2a: Simplified block diagram showing power components selected

The components shown in Fig 3.1.2a above were selected to fit the client's requirements for the device. An explanation of how the power system functionally operates can be found in section 2.2. The power subsystem consisted of four main components: the solar panel, charge controller, battery, and buck converter. Each component is essential to ensure our system meets the desired runtime of 7 days. In the client’s preliminary design, his power system consisted of two components, a battery and a buck converter. The addition of a solar panel and charge controller makes it possible for the system to run well over the desired runtime, as test results will show.

Component Selection: Solar Panels

Components were each selected based on a list of criteria specified to fit our client’s needs. The solar panel was selected based on its weight, durability, price, efficiency, availability, and size. The three types of solar panels considered were Monocrystalline, Polycrystalline, and Passivated Emitter and Rear cell (PERC) panels.

Monocrystalline Panels:

Monocrystalline panels are made from a single pure silicon crystal that is cut into multiple wafers. There are multiple advantages to this panel type. For one, they are highly efficient. Monocrystalline panels are known for their high-efficiency rates, typically ranging from 15% to 22%. They require less space compared to polycrystalline panels for the same power output, making them suitable for installations with limited space. Monocrystalline panels also tend to have a longer lifespan (often 25 years or more) due to the high-quality silicon used in manufacturing. One issue with these panels is that they are generally more expensive than polycrystalline panels due to the higher purity of silicon and the more complex manufacturing process.

Polycrystalline Panels:
Polycrystalline panels are composed of multiple silicon crystals rather than one. One benefit of these panels is that they are typically more cost-effective than monocrystalline panels. However, polycrystalline panels have lower efficiency rates (typically between 13% to 16%) compared to monocrystalline panels. On top of this, they require more space than monocrystalline panels for the same power output.

PERC Panels:
PERC panels improve on the traditional monocrystalline panel, providing more efficiency by reflecting light back into the cell. One benefit of this is that they have a higher efficiency than traditional monocrystalline and polycrystalline panels, typically in the range of 18% to 23%. The rear-side passivation technology reduces electron recombination losses, improving overall efficiency. They also perform better than standard panels in low light conditions, enhancing energy production in cloudy or partially shaded environments. The durability and lifespan of these panels are also improved. While these are great panels, one major issue is that PERC panels are significantly more expensive than traditional monocrystalline and polycrystalline panels due to the additional manufacturing complexity.

For this project, we opted to go with a flexible monocrystalline solar panel. This panel was ideal for the project, as they are highly efficient, extremely durable, portable, and available to ship to Kenya. The specific solar panel that was selected for this project was the Renogy Monocrystalline Flexible Solar Panel 50W 12V. The panel was chosen for being fairly cheap ($80), having a maximum power output of 50W, and being extremely durable. The Panel also follows proper engineering standards, having an Ingress Protection rating (IP rating) of 168. According to the standard, an IP rating of 168 means that the solar panel is water resistant in fresh water to a maximum depth of 1.5 meters for up to 30 meters [3]. This is more than adequate for rainy conditions in Kenya. It is important to note that this panel also follows IEEE Standard Definitions of Terms For Solar Cells, a standard that provides acceptable terms for use in the application of solar cells to power systems [15].

Component Testing: Solar Panel (Renogy Monocrystalline Flexible Solar Panel 50W 12V)

Below are the specifications for our solar panel:
- Current short circuit: 2.92
- Current optimal: 2.71
- Voltage open circuit: 22.6
- Voltage optimal: 18.5

To ensure that our solar panel operated as expected, we had to test it. To test to see if a solar panel is operating correctly, the short circuit (ISC) current and open circuit voltage (VOC) must be measured. To test VOC, we connect the positive lead of the multimeter to the positive wire of the solar panel, and the negative lead of the multimeter to the negative wire of the solar panel (in direct sunlight). To test ISC, we do the same thing, with our multimeter lead connected to the current port. The measured VOC was 22.6, while the measured ISC was 2.92. This is as expected, meaning our panel operates as expected.
With this information, we can calculate the maximum power point of this panel. The maximum power point is the point on a voltage versus current graph that provides the maximum power output of a solar panel. For this solar panel, the maximum powerpoint would be the optimal current times the optimal voltage. MPP for the panel: 2.71 A * 18.5 V = 50.135 W.


Figure 3.1.2b: Graph showing calculated max power point of solar panel used in the project.

Component Selection: Battery

The battery was selected based on efficiency, durability, weight, price, and availability. Because it is difficult to take batteries overseas, it was essential that an equivalent to the battery we used for this project could be purchased in Kenya for our client. Because of this, we were limited to two types of batteries, Lead Acid and Lithium Ion.

Lead Acid Battery:
A lead acid battery is a battery that has lead plates submerged in sulfuric acid electrolyte. Lead acid batteries are known for being cost-effective. While they are a cost-effective battery, they have a low life cycle when compared to Lithium-Ion batteries, especially when deep cycling of the batteries is involved.

Lithium-Ion Battery:
Lithium-ion batteries are batteries where lithium ions move from the negative electrode to the positive electrode during discharge and back during charging. Lithium-ion batteries have a higher energy density than lead-acid batteries, providing more energy storage capacity for their size and weight. They also have a longer cycle life and can withstand a higher number of charge-discharge cycles compared to lead-acid batteries, especially when not deeply discharged. Lithium-ion batteries are lightweight and compact, making them ideal for applications where weight and space are critical factors. On top of this, they require minimal maintenance compared to lead acid batteries, typically only requiring periodic charging and monitoring. Some issues to consider with lithium batteries are the cost and the safety concerns. Lithium-ion batteries are more expensive than Lead-acid and can be more sensitive to overcharging, deep discharging, and temperature extremes. This is why most lithium-ion batteries have built-in protection circuits to manage charging and discharging safely.
For our project, we decided to go with a Lithium-ion battery. The long cycle life, higher energy density, and portability (lightweight) outweigh the extra price. The battery we decided to go with was the LiFePO4 12V 9Ah deep cycle lithium battery by HWE. This battery was selected for having an equivalent in Kenya and meeting the standards described in IEEE Std 1679.1. This standard is a guide for evaluating a lithium-ion battery in stationary applications. One important section that was looked at from this standard was section 5.5: Operating conditions [14]. It was essential that our battery was rated for the temperatures in Kenya during July, August, and September. This battery had an optimal operating temperature range of 14 degrees Fahrenheit to 112 degrees Fahrenheit. The maximum temperature reached in Kenya during these months is around 80 degrees Fahrenheit, meaning the batteries should operate without issue.

Component Testing: Battery (LiFePO4 12V 9Ah deep cycle lithium battery)

Below are the discharge curves for both the battery we used and the batteries available in Kenya. Discharge curves are graphical representations that show how a battery's voltage changes over time as it discharges. These curves are crucial for understanding and predicting the performance of batteries in various applications.

Figure 3.1.2c: Discharge curve of our in the US

Figure 3.1.2d: Discharge curve of Mustek battery (batteries to be used in Kenya)

As can be seen in figures 3.1.2c and 3.1.2d, the battery discharge curve is fairly similar when comparing our battery to the ones used in Kenya. This means that the battery can realistically be used as an accurate representation of how the Kenya batteries operate.

Depth of Discharge to Cycles (DoD)
DOD | CYCLES
30% | 8000
50% | 5000
80% | 3000
100% | 2000
Figure 3.1.2e: Number of cycles in lifetime in relation to the depth of discharge drained from the battery

Figure 3.1.2e shows us how depth of discharge (DoD) affects the total number of cycles for our battery. DoD refers to the extent to which a battery's stored energy is used before it is recharged. As can be seen in the chart, if our LiFePO4 battery is drained to 100% DoD consistently, we will be able to obtain a maximum of 2000 cycles from the battery. However, if the battery is not drained to 100% DoD, it can be cycled significantly more. It is important to note that the DoD is not the same as maximum capacity. Our battery has a microchip inside that prevents it from discharging to 100%. 100% DoD is equivalent to 80% of the battery's full capacity. From Figure 3.1.2c and Figure 3.1.2d, we can see that the max voltage (full capacity) of the battery is 13.3V, while 0% capacity is 10V. To test this, I fully charged the battery and checked the voltage. I then completely drained the battery to see what the minimum voltage I could achieve was. The minimum voltage allowed by the battery was 11V (100% DOD, 80% of capacity), while the maximum was 13.3V. This confirmed that our battery was functional and operated as expected.

Component Selection: Charge Controller

For charge controllers, the main criteria considered were efficiency and price. The two types of charge controllers considered for this project were Pulse Width Modulation charge controllers (PWM), and Maximum Power Point Tracking (MPPT) charge controllers. Understanding how these two charge controllers work was crucial in the selection of the component.

PWM Charge Controller:
A PWM charge controller regulates the charging of the battery by gradually reducing the amount of power delivered to the battery as it reaches full charge. It maintains a constant voltage for the battery (typically 12V or 24V) and adjusts the charging current based on the battery's state of charge. They are moderately efficient but do not compare to an MPPT charge controller. They can efficiently charge batteries that are not deeply discharged but may struggle with low battery conditions or mismatched panel and battery voltages. These charge controllers are suitable for small solar systems or where cost is a significant factor. They are straightforward and reliable but lack the efficiency optimization of MPPT controllers.

MPPT Charge Controller:
An MPPT charge controller dynamically adjusts the voltage and current to extract maximum power from the solar panels under varying sunlight conditions. It constantly tracks the maximum power point of the solar panel array and adjusts the output to match the battery voltage, maximizing the efficiency of the solar system. An MPPT charge controller is highly efficient. It can significantly increase the charging efficiency (typically 95% or higher) by matching the solar panel's output to the battery's optimal voltage.

For this project’s purposes, a highly efficient charge controller was necessary to ensure our device would last a total of 7 days. Because of this, we opted to go with an MPPT charge controller. The specific charge controller we went for on this project was the Powerwerx MPPT-150-14.6, DC-to-DC Solar Charger Controller. This charge controller was ideal for our project, as it is designed for lithium ion battery charging and was cheap for an MPPT charge controller ($30). The charge controller also follows proper engineering standards, and has an IP rating of IP67. This means that the charge controller is waterproof in up to one meter of water for up to 30 minutes [3].

Component Testing: Charge Controller(Powerwerx MPPT-150-14.6, DC-to-DC Solar Charger)

It was necessary for the charge controller to be tested to ensure that it was a true MPPT charge controller. To test this, we connected the solar panel, charge controller, and battery. We then put the solar panel in the sunlight, and measured the current of the panel to the charge controller. We then measured the current and voltage coming out of the charge controller going into the battery.

Results:
- 2.34 A from panel to charge controller
- 3.33 A from charge controller to battery
- 14.6V out of charge controller

From this test, we can see that our charge controller was able to increase the current coming out of the solar panel and going to the battery. This confirms that the charge controller is a true MPPT controller. Our charge controller was rated for 95% efficiency. When multiplying our output voltage by our current, we can see how much power our charge controller creates, and compare that to our solar panel’s maximum power point. 14.6V * 3.33A = 48.618 W. The MPP of our panel is 50.135W. This means that our charge controller is 97% efficient, which is better than expected.

### 3.1.3 Power Budget:

One of the critical documents developed for this project is the power budget. The power budget comprehensively outlines the power consumption requirements for each component of our device. It includes anticipated power draw for each load, defines operational states (including on, idle, and off), and specifies the duration spent in each state. The power budget is essential as it enables us to accurately estimate the device’s operation time. Below is our power budget:

Fig 3.1.3a: Final Power Budget

From the power budget, we were able to calculate the maximum amount of time our device could operate for in the field. The total amount of running time calculated for our device at a 40% duty cycle was 92.86 hours, which equates to just under 4 days. This is a worst case scenario, assuming our device runs at maximum power constantly. This also does not account for the solar panel.

### 3.1.4 Subsystem Testing:

Testing took place with a 5 ohm power resistor attached to our DC-DC converter connected to our battery. The aim of this was to mimic our maximum power consumption for the device (2.263 W). Voltage was measured at the battery every couple hours to obtain accurate discharge time.


Figure 3.1.4a: Battery test circuit schematic.

One problem with this test was the fact that the DC-DC buck converter’s power consumption was also taken into account when choosing our power resistor. As seen in Figure 3.1.4a, the DC-DC converter is part of the system, meaning that the power consumption should not have been accounted for. To solve this, we factored out the power consumption of the DC-DC converter, giving us a more accurate power consumption of 1.8 W. For a power consumption of 1.8 W, we would want to use a 6 ohm resistor. 5ohm/6ohm = .833, meaning that our actual system should be 17% more efficient than our test. To calculate the estimated runtime for our test, we took the usable power of our battery and divided it by the power consumption. 92Wh/2.2W = 40.7 hrs. We then accounted for the efficiency of our buck converter (73%), giving us a targeted runtime of 29.7 hours for this test. When accounting for the 17% extra efficiency we should realistically be getting, our estimated battery runtime comes to 37.31 at full load. Two subsystem tests were performed. Below are the results:

Subsystem Test 1

Figure 3.1.4b: Battery draining test with power resistor (5ohm)

Subsystem Test 2


Figure 3.1.4c: Battery draining test with power resistor (5ohm)

The results from Subsystem test 1 were invalidated, as the battery abruptly died. After recharging the battery, it was still unable to discharge or show a voltage reading when using a multimeter. A few days later, the batter began to work again. We assumed that the circuit inside the battery was a little messed up, and subsequently used a new battery for Subsystem test 2. Subsystem test 2 ran as anticipated. The battery lasted a total of 24.57 hours, with our estimated goal being 29.71. This means that we were off by 18% from our estimated goal for this experiment. Calculating how long our battery would last in a realistic environment (6-ohm resistor instead of 5 ohm), our battery would have lasted 30.59 hours. While these numbers seem low, these estimates assume a 100% duty cycle with the absolute maximum power consumption for our system.

The first solar test conducted took place with the panel, battery, and charge controller. No load was applied. The aim of this test was to observe how long it would take for the battery to fully charge. The test took place on a sunny day, with a UV rating of 7. Below are the results.

Charging a dead battery with no load

Figure 3.1.4d: Battery charged with UV 7, no load

From this test, we can see that the solar panel was able to successfully charge the battery in 2 hours. Based on this, we can see that as long as it is a sunny day, the panel is able to charge the battery from fully drained to full charge with no load extremely quickly.

The next solar test consisted of the battery, charge controller, solar panel, the DC-DC converter, and the 5 ohm power resistor load. The aim of this test was to observe whether the solar panel would charge the battery even while under full load. Two tests were performed, one on a fairly sunny day with a UV rating of 6, and another on a less sunny day with a UV rating of 4.

Charging Battery with load Test 1

Figure 3.1.4e: Battery charged with UV 6

Charging battery with load Test 2

Figure 3.1.4f: Battery charged with UV 4

From these two tests, we can conclude that the battery is able to be charged under load on days where the UV is 4 or higher. The average UV rating in Kenya in July, August, and September is 5. This means that on an average day in Kenya, the battery would be able to be successfully recharged.

### 3.1.5 Full System Testing:

Once our system was fully built, we were able to run a full system test to see how long the battery could run the final device for. For this test, we connected the battery to our device and played our human noises track. The reason we ran the human noises track was because they consume the most power when compared to the other tracks. The test was run at a 60% duty cycle, without the solar panel attached. Below are the results:

Battery Test at 60% Duty Cycle With Human Noises


Figure 3.1.5a: Final system testing shows system lasts multiple days

From this test, we were able to determine that without a solar panel, the device was able to last for 6 days. From the tests conducted, we can conclude that the power systems engineer was successful in providing the client with the desired deliverables. While the full system test lasted 6 days instead of 7, this was without a solar panel attached to the device, and a higher duty cycle than desired by the client (60% instead of 40%). With the correct duty cycle and a solar panel attached, the device would easily last 7 days. As stated previously, the average UV rating in Kenya is around 5 during July, August, and September. As long as the device gets one day with a UV rating equal to or greater than 4 in the 6 days it is running, the battery will be able to fully recharge.

### 3.2 Embedded Systems

For a project requiring sophisticated components found in an embedded system, the composition of certain parts contributed significantly to the backbone that allowed our group to satisfy the client deliverables given to us in the pre-design phase of this device. To achieve this, the team chose to design and integrate a specialized computing system to perform dedicated functions within the entire electrical system of the playback device. Tailored to the group's client, the embedded system was designed to perform specific tasks and functions that would ultimately contribute to the reliability and functionality of the project. This would help progress our client's main goals of wildlife conservation and provide peace of mind that their unmonitored device is performing as intended. Defined as a subsystem, the embedded system features a central brain that acts as the center of functionality in the device. Using this design, the embedded systems engineer can leverage this centralized brain to execute carefully written programmed instructions that drive anything from I/O interfaces to internal functionality. With this seamless hardware and software integration, the embedded system operates efficiently and effectively to fulfill its specific role within the larger device. To accomplish this, the subsystem itself must be divided into smaller, equally important components that give us an overview of how our brain works from the inside out.

### 3.2.1 Subsystem Overview

The embedded system of the wildlife playback device would not be able to fulfill its goal of satisfying client preferences without the use of the centralized microcontroller used in the project. Ultimately, the microcontroller coordinates and manages the various components and functions to ensure seamless operation within the device. Derived from the client preferences, the microcontroller has an important job in helping our client get the best out of the device. External buttons programmed through it allow the user to interact with and control the device. UART communication within the board facilitates interfacing with the MP3 module that stores music, sending commands so that audio playback and control are at the user's fingertips. Internal sleep functions enable the controller to conserve power when the user is not changing parameters, ensuring only essential peripherals remain active. Lastly, the analog-to-digital converter capability allows battery monitoring and system feedback to be read out in the field and analyzed for future use. Translating these functions into what the client wants takes time and consideration in a pre-design phase that ensures the components selected are capable of executing these abilities and are compatible with the surrounding subsystems in the device.

To perform this pre-design phase correctly and save time and effort in the future, it's essential to have a proper understanding of what the client wants, what the client needs, and how those two things translate into the technical world of engineering and the embedded system. For the group's client, a few key needs stated require extensive requirements for both microcontrollers and the surrounding components that comprise the embedded system. In summary, the client's needs relating to the embedded system are as follows:

- External controls: The device must be accessible and functional outside of changing code. To achieve this, adding external control through the use of buttons allows for changing volume and treatments on the go and out in the field.
- Maximum power saving abilities: The device must be as power efficient as possible. Therefore, the ability to turn off power-hungry peripherals and enter power-saving modes when not essential can be the difference between the device lasting hours versus days.
- Monitoring capabilities: The device should be able to reflect the condition of the main battery powering the system. This means utilizing a microcontroller's ability to convert analog readings into digital data that can be read and processed.

After defining these client requirements, the group was able to add their design requirements that would contribute to the technical integration of the embedded system into the rest of the device and its subsystems. The design requirements for the microcontroller decided by the group are as follows:

- 3.3V power requirements: To ensure compatibility with other subsystems and maintain some level of universality within the entire device, the microcontroller should follow a common operating voltage. This allows the embedded system engineer to integrate it more easily with other subsystems using similar devices with similar operating voltages.
- UART communication capabilities: Similar to the power requirement, the microcontroller should be capable of communicating effectively with other chips or boards on the device. A common method of this is the communication protocol called Universal Asynchronous Transmitter/Receiver (UART), which provides a low-energy way to send and receive commands between devices.
- Size requirements: The device as a whole needs to be compact and designed to be carried in mass quantities by the client. One way to help with this requirement is to use small microcontrollers that fit compactly without sacrificing the computing power of a regular-sized microcontroller.

After laying these design requirements out, the microcontroller selected for the embedded system brain is the ESP32-S3-DevKitC-1-V1.1 by ESPRESSIF. Below is an image of the microcontroller along with its pinout diagram and some of its peripheral capabilities:

Figure 3.2.1.a - ESP32-S3 Pinout and Peripheral Diagram [10]

The ESP32-S3 microcontroller is a versatile and powerful component well-suited for our embedded system. It can read inputs from the external buttons through its numerous GPIO pins, enabling the ability to integrate user interaction and control. This capability proves to be powerful when user interaction is then routed from the buttons to the board's ability to support UART communication through its Rx and Tx pins. This is the key to facilitating reliable data exchange with the MP3. In addition, the multiple ADC pins allow a large selection of where to place the external voltage reading which will then allow a programmed instruction to turn this analog signal into digital data for precise measurement and processing. With such a powerful brain ready to be integrated into the embedded system, subsystem circuit prototyping
commenced with the goal of putting the technical decisions from the pre-design phase to the test. With the help of Aiden and his ability to create schematics in Cadence, the embedded system was assembled with the essential components to help accomplish a functional embedded subsystem. Below is a schematic diagram of the prototype schematic with the highlighted embedded system circuit in red.


Figure 3.2.1.b - Prototype Schematic with Highlighted Embedded System Circuit
The wiring diagram illustrates the connections for the embedded system utilizing the ESP32-S3 talked about previously. In addition, the audio subsystem, located to the right of the red outline, is depicted to help visualize how the two are connected when talking about communication between subsystems. Serving as the central unit of the circuit, the ESP32 Single Board Computer is powered by the 3.3V supply connected at the top. In addition, to the right of the board shows where the device's three external buttons reside. Using a common ground connection, the three external buttons utilize the microcontroller's capabilities to interface with GPIO pins 9, 10, and 11. Just above these pins is where the input for the ADC pin reads the battery monitoring circuit in GPIO pin 2. As mentioned, the MP3 module shown above shows how the DFPlayer Mini and the ESP32-S3 achieve simple UART communication with the connection of 4 pins. The Rx pin of the DFPlayer (pin 2) connected to the Tx pin of the ESP32 (pin 17) allows for the sending of communication from the controller to the MP3. Similarly, the Tx pin of the DFPlayer (pin 3) is connected to the Rx pin of the ESP32 (pin18), allowing for the return of information back to the board from the MP3. This configuration of pins and connections allows for the ESP32 to effectively manage external inputs, monitor battery voltage, and facilitate audio playback through UART communication with the DFPlayer mini. After a preliminary design of the embedded system is done, the same must be done for the software architecture that helps create functionality out of what was just designed.

### 3.2.2 Technical Details

Designing software architecture can be just as difficult as designing the circuit for the embedded system and should follow similar steps of design to ensure it is done correctly. Beginning the software architecture before beginning to even write the code for the project is crucial for several reasons. First, it provides a clear blueprint for, defining how different components interact and ensures that all requirements are met efficiently. This upfront planning helps to identify potential issues and complexities early, reducing the risk of significant rework later in the development process. Meaning, that a well-thought-out architecture enhances maintainability and scalability, making it easier to adapt the system to future changes or expansion like the animals our client hopes to save from this project. For the group's project specifically, preparing a software architecture meant using a structured approach to figuring out how communication protocols, data handling, and I/O integration could all be integrated into one perfect design.
For communication protocols, defining the UART configuration meant the difference between hours of troubleshooting and the device working right away. Baud rate, data bits, parity, and stop bits ensure that the devices connect properly, communicate clearly, and maintain connection throughout functionality of the device. For our MP3, the module has a UART port with standard serial and an adjustable baud rate (Default baud rate is 9600) [9]. Using the microcontrollers' similar adjustable baud rate capability, the MP3 and ESP32 can be linked up to a similar baud rate while leaving communication with the computer for troubleshooting. Using simple code manipulation and the serial pins of the board, the two are synced up and sharing data at the same rate, ready to begin sending information, commands, and data back and forth between one another. Once the communication is squared away, determining how to send commands with external buttons can be considered next.
For I/O integration in this software architecture, handling of the external buttons must be considered in detail and mapping each button to specific GPIO pins helps expedite the process. Developing interrupt service routines and polling mechanisms to detect button presses while at the same time, considering the need to debounce buttons to ensure reliable input. This consideration translates into how well the communication protocol can pass it on to the MP3. A large part of this, button debouncing, will be talked about in the challenges and solutions portions of this report along with the design considerations associated with it. With information like this being crucial to how the device performs, it becomes clear that handling data like this becomes of utmost importance when collecting inputs from external factors such as buttons and batteries.
The data handling framework, specifically for incorporating ADC pins to read external voltages, requires a specification for how the conversion from analog to digital is to be managed. Sampling rates, resolution, and voltage reference can all contribute to difficulties if not properly planned out. Done right the battery monitoring for the device becomes accurate and useful to both the team and the client. For the embedded system design, the sampling rate does not have to be something that is consistently taking voltages. Instead, we can rely on the slow depleting nature of the battery to lengthen the time between sampling rates. Something along the lines of 4 samples a day would work well for our device. An important factor for the ESP32 is the ADC resolution it can provide. The data sheet for the ESP32 reveals a 12-bit ability at each of the
ADC pins on the microcontroller [11]. Last and certainly the most important for the device is the reference voltage which comes in at 3.3V. This will be another topic discussed in the challenges and solutions section of this report to explain the design that went into considering this factor. Many of the topics listed above demonstrate a basic understanding of what goes into the software architecture. However, when implementing these topics into the real design of the embedded system circuit, technical challenges arise that demonstrate the importance of good engineering standards in designing software architecture. More specifically, how consideration for button debouncing and reference voltage at the ADC pin heavily influence design considerations in both the architecture and subsystem design.

### 3.2.3 Challenges and Solutions

The design and preparation for technical details can be a long and thorough process full of problems, redesigns, and solutions. Challenges like button debouncing and voltage reference considerations require design testing and extensive amounts of research about how to accomplish the end goal as efficiently as possible. The roles of each of these may differ related to their overall functionality within the system, however, the road to the end design of each of these smaller subsystems follows a step-by-step process derived from good engineering standards. The first challenge, related to the external buttons, focuses on the ability to debounce buttons. Button debouncing is a critical technique used with external buttons on microcontrollers to ensure accurate and reliable input detection. When a button is pressed or released, the physical contact can cause multiple rapid changes in the signal known as “bounces”. This behavior can lead to erratic and unintended behavior in the system. This behavior can be seen below:

Figure 3.2.3.a - Bouncing Signal from Button [12]

The rapid up and down movement in the signal is what is referred to as the “bounce” and each transition could be mistaken as an input signal. Solutions for this can be implemented either through physical hardware debouncing or through software programming. Hardware debouncing, typically consisting of capacitors, resistors, and a logic chip, relies on creating hysteresis to smooth out the signal. On the other hand, software debouncing relies on creating short time frames to filter out the noise by filtering rapid fluctuations within that time frame.

Managing this noise can enhance the reliability and performance of the embedded system when it is added to the rest of the device. To make sure the correct design for the device was picked, it was important to test them both and make the decision afterward. Starting with the hardware solution.
Button debouncing and its effects can be effectively managed using a combination of a resistor, a capacitor, and a logic chip like the 74HC14 Schmitt trigger inverter. Below shows the first prototype of the embedded system with a display of how this circuit was to fit into our system.


Figure 3.2.3.b - Hardware Debounce Circuit The resistor and capacitor form an RC debouncing circuit for each GPIO pin. The resistor limits the current flow when the button is pressed, preventing damage to the components, and helps pull the input to a known voltage level when the button is not pressed. The capacitor smooths out the rapid voltage changes caused by the button's mechanical bounces by charging and discharging through the resistor, effectively filtering out high-frequency noise. The 74HC14 Schmitt trigger inverter further processes this smoothed signal before it reaches the input of the board. The Schmitt, triggered by hysteresis, switches at different voltage thresholds for rising and falling edges, thus ignoring small fluctuations and noise that might occur during bouncing [13]. This component converts the cleaned analog signal from the RC circuit into a stable digital output, ensuring the microcontroller receives an accurate representation of the button's state. Together, these components ensure reliable and predictable behavior in the embedded system by providing a clean, stable input signal free from the erratic effects of button bounce. This design, although reliable, proved to be an expensive and spacy solution to the bouncing from the buttons. As a result, a secondary solution found in the software of the microcontroller compacted the embedded system back to only its necessities.

The software solution to this problem proved to be something efficient and just as reliable. For debouncing with software, it is a common practice to implement a timer-based approach to filter out these false inputs from bouncing. Instead of the hardware smoothing it out, introducing a short delay to allow the mechanical bounce to settle before confirming the button state creates the same effect as the logic chip seen in the hardware solution. The process involves reading an initial button state and then using a timer or delay function to wait for a specific debounce period. For this device, 50 milliseconds was used. After this delay, the button state is read again and if the button state remains the same as the initial read, the button press is considered valid. Not only does this process provide the same functionality and reliability as the hardware solution, but the appealing cost and space reduction means that the software solution for debouncing the device's external buttons was a final design pick.
In addition to the button debouncing, the reference voltage detail related to the ADC pin created additional design choices that weighed heavily on power consumption and complexity. As discussed, the microcontroller utilizes an operating voltage of 3.3V at the power pins. As a result, the other pins used for I/O capabilities must not exceed this voltage in order to protect the microcontroller. The reason for this is that the ADC pin can only accurately measure up to what the microcontroller’s supply voltage is. Defining these points along the supply voltage (0V to 3.3V) is what allows the ADC to accurately assign numbers for the microcontroller. As a result of wanting to directly measure the 12-volt battery, it is essential to divide the maximum voltage of the battery by at least the maximum voltage of the operating voltage of the microcontroller. To do so, the implementation of a voltage divider circuit was required to perform this task.
The Voltage Divider is tasked with reducing the 12-volt battery voltage to a level suitable for precise measurement by the ADC pin (<3.3V), taking into account considerations such as current consumption, voltage ratio, ADC pin input impedance, and resistor values. Incorporating this circuitry into the ADC pin setup facilitates the management of inherent current fluctuations, irrespective of the microcontroller's operational state, including factors such as internal circuitry and input impedance. The choice of how to implement this voltage divider, however, is anything but simple. To make the correct design choice, comparing the potential ways of dividing this voltage point in the correct direction for testing this circuit. Below is the comparison of the circuits considered.

Figure 3.2.3.c - Voltage Divider Comparison Based on Project Requirements

The two-resistor method for voltage dividers presents a compelling choice compared to the op-amp and microcontroller-controlled (MC-controlled) methods due to its simplicity, cost-effectiveness, and low power consumption. First and foremost, the two-resistor configuration is highly cost-effective, utilizing only two passive components, which are inexpensive and widely available. This simplicity translates to straightforward circuit operation and easy implementation, making it an ideal choice for basic voltage division tasks without the need for complex design considerations. Another significant advantage of the two-resistor method is its passive nature, resulting in low quiescent current. Unlike the op-amp method, which requires an active component that consumes power even in idle states, the two-resistor setup does not introduce additional power requirements, thus conserving energy. This low power consumption is particularly beneficial in the device's battery-operated design. While the op-amp method offers high input impedance and precise voltage division, it comes with added complexity, higher quiescent current, and additional power requirements, which can be overkill for simple voltage division needs. Similarly, the MC-controlled method, although providing dynamic control and reduced loading effects, introduces complexity, higher on-state power consumption, and potential noise sensitivity issues, making it less ideal for this straightforward application. In summary, the two-resistor voltage divider method stands out as the best option due to its cost-effectiveness, simplicity, ease of implementation, and low power consumption, making it a practical and efficient choice for the basic voltage division requirement in our device. The final design for this can be seen below, integrated into the final prototype of the power circuit.


Figure 3.2.3.d - Two Resistor Voltage Divider in Final Prototype Power Circuit

This final design choice for the battery monitoring system was not the end of the design considerations for this topic. In addition to the ADC pin requiring this consideration for the reference voltage, it is also a significant design consideration when discussing the non-linear behavior of the ADC pin. The relationship of the ADC pin to the digital read can be seen below.

Figure 3.2.3.e - ESP32 ADC Pin Voltage Versus ADC Reading

Noticeably, the two ends of the graph show where the non-linear relationship determination comes from. To ensure the ADC pin is in fact reading what the group needs on a linear scale, it is possible to shrink the voltage that can be read to the center part of the graph. This means creating a calibration technique that instead of using a 0-3.3 scale, uses a 1.1-2.8 scale that proportionally symbolizes the voltage but on a more linear scale. This is the final design choice for this topic in the ADC pin reading.

With these design choices for external buttons and ADC pin readings, the final design for the embedded system can begin a testing and validation phase that begins to test the system in a more realistic environment. Doing this part of the process ensures the refinement of a troubleshooting routine and the confirmation of a reliable device.

### 3.2.4 Testing and Validation

Testing and validation are critical steps in the final development process of the device, ensuring the design meets the required specifications and functions brought to the group in the beginning by the client. Before finalizing the design, the device requires testing to help identify and rectify potential issues. This ultimately will help prevent costly mistakes and ensure the reliability of the device when out in the wild where equipment may not be readily available. This validation confirms a minimum standard that the device must be held up to in order to be ready to be sent into the wild for real-world actions. The process for testing and validation for this embedded subsystem is used to not only enhance the device’s quality and safety but also build confidence in the client before their journey. For a strongly software-driven subsystem like the embedded system, testing and validation came in the form of various test benches that confirm working portions of a central, main code. These test benches are derived from the client preferences talked about in the beginning and show critical subcomponents working based on what test bench is selected for testing. Although each component had its own test bench, there were two benches that helped assist the group in troubleshooting problems during the first prototype and ultimately led to a centralized area of where the problem was occurring. As a result, changes could be made in the next design to remediate these problems.
The first of these two benches, the UART Connectivity Test, was designed to test the initial UART connection between the microcontroller and MP3 upon first powering on the device. The testbench singled out the Rx and Tx pins talked about in the technical details section of the embedded subsystem. It first tested an initial connection and if it failed, proceeded to check each individual pin to identify which connection was breaking the transmit and receive. For the first prototype, the initial connection showed connectivity issues between the microcontroller and the MP3 upon first powering it on. The group was able to then confirm the correct power supply to the MP3 and after, localize the issue to the UART communication pins. Here, the microcontroller could test the connectivity by measuring the power getting to the Rx and Tx pins of the MP3. This led us to a faulty connection in the Rx pin of the MP3, causing the connectivity to be compromised. The group identified this and remediated the problem with a new solder.
The second of these test benches, the Button Input Test, was designed to test the incoming signal from the buttons and the debounce abilities of the software. The test bench used polling methods to raise flags if problems with the buttons arise. Similar to the first test, problems arose with the buttons on the first prototype. Using the testbench, the program was showing the consistent flag being raised, indicating the button was connecting the pin to the ground constantly. This led to a redesign of the button footprint and configuration.
Although the rest of the test benches were not needed because of the successful design, the validation provided by the successful passing of these test benches ensured that the proper steps were taken for each design. In addition, client validation from these tests could be achieved.

### 3.3 Audio and Electronics System [Liam Magee]
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

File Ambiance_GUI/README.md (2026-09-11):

# Ambiance GUI

This GUI application allows users to connect to STM32-based audio devices via UART or Bluetooth to control playback, volume, schedules, and download logs. It supports macOS and Windows, and can be packaged into standalone applications.

## Features
- Bluetooth and UART selection and connection
- Volume and duty cycle control
- Schedule configuration with overlap validation
- Log downloading and saving
- Real-time UART debug display

---

## If want to mini standalone Python environment that just runs
### MacOS `.app` Bundle

#### Step 1: Install Xcode if you do not have it installed already

```bash
xcode-select --install
```

#### Step 2: Install Required Dependencies

```bash
python3 -m venv .venv
source .venv/bin/activate
pip install -r requirements.txt
```

```bash
pip install pyinstaller pyobjc-core pyobjc-framework-CoreBluetooth
```

#### Step 3: Generate `.spec` file

```bash
pyi-makespec Ambiance_GUI.py
```

#### Step 3: Modify the generated `Ambiance_GUI.spec`
Open it using TextEdit via:

```bash
open -a TextEdit Ambiance_GUI.spec
```

Replace all of the text in the file with:

```python
 -*- mode: python ; coding: utf-8 -*-

from PyInstaller.utils.hooks import collect_submodules, collect_data_files
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

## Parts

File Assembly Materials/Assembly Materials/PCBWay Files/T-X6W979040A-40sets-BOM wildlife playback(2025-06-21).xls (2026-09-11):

PCBWay Bom Quotation, Product No.:T-X6W979040A
Item # | *Designator | *Qty | Manufacturer | *Mfg Part # | Description / Value | *Package/Footprint | Mounting Type | Your Instructions / Notes | *Delivery Time | *Actual Purchase Mfg Part # | Customer Reply | PCBWay Update
1 | BT1 | 1 | Keystone Electronics | 106 | Battery_Cell | Battery:BatteryHolder_Keystone_106_1x20mm | Thru-hole |  | 7-10 Workdays
2 | C1,C2,C3,C4,C5,C6 | 6 | Samsung Electro-Mechanics | CL21B104KCFNNNE | 0.1uF | Capacitor_SMD:C_0805_2012Metric | SMD | standard 0805 capacitors
3 | C7 | 1 | Samsung Electro-Mechanics | CL21A107MQYNNWE | 100uF | Capacitor_SMD:C_0805_2012Metric | SMD | standard 0805 capacitors
4 | C8 | 1 | Panasonic Electronic Components | EEE-FN1E681UP | 680uF | Capacitor_SMD:CP_Elec_10x10.5 | SMD |  | 7-10 Workdays
5 | C9 | 1 | KEMET | T491D337M006AT | 330uF | Capacitor_Tantalum_SMD:CP_EIA-7343-31_Kemet-D_HandSolder | SMD | Polarity stripe/bezel is positive (+), not negative (-). Polarity stripe (+) points towards L1, D1, J1, etc.
6 | C10, C11 | 2 | Kemet | C0805C689D1HACTU | 6.8pF | Capacitor_SMD:C_0805_2012Metric | SMD | standard 0805 capacitors
7 | D1 | 1 | Diodes Incorporated | B340AE-13 | D_Schottky_Small | new component:DIOM5226X230N | SMD
8 | J1,J2 | 2 | Same Sky (Formerly CUI Devices) | 102-6191-ND | Screw_Terminal_01x02 | TerminalBlock:TerminalBlock_MaiXu_MX126-5.0-02P_1x02_P5.00mm | SMD | or any other aplicable screw terminals available | 7-10 Workdays | TB006-508-02BE
9 | L1 | 1 | Pulse Electronics | PA4342.473NLT | 47uH | new component2:IND_PA4342.473NLT | SMD |  | 7-10 Workdays
10 | R1,R2,R3,R4,R5,R8 | 6 | Panasonic Electronic Components | ERA-6AEB102V | 1k ohm | Resistor_SMD:R_0805_2012Metric_Pad1.20x1.40mm_HandSolder | SMD | standard 0805 resistors
11 | R6,R7 | 2 | Panasonic Electronic Components | ERJ-6GEYJ103V | 10k ohm | Resistor_SMD:R_0805_2012Metric_Pad1.20x1.40mm_HandSolder | SMD | standard 0805 resistors
12 | SW1,SW2,SW3,SW4,SW5,SW6 | 6 | Same Sky (Formerly CUI Devices) | TS04-66-70-BK-100-SMT | SW_Push | Button_Switch_SMD:SW_SPST_Omron_B3FS-105xP | SMD |  | 7-10 Workdays
13 | U1, U2 | 2 | Sullins Connector Solutions | PPPC192LFBN-RC | PinHeader_2x19_vertical | Connector_PinHeader_2.54mm:PinHeader_2x19_P2.54mm_Vertical | thru-hole | any 19 pin headers with the same foot print and pitch would work
14 | U3 | 1 | Microchip Technology | MCP7940NT-I/SN | MCP7940N-xMNY | Package_SO:SOIC-8_3.9x4.9mm_P1.27mm | surface mount
15 | U4 | 1 | Texas Instruments | LM2596T-3.3/NOPB | LM2596T-3.3 | Package_TO_SOT_THT:TO-220-5_P3.4x3.7mm_StaggerOdd_Lead3.8mm_Vertical | thruhole
16 | U5 | 1 | Sullins Connector Solutions | PPPC041LFBN-RC | Connector_PinHeader_2.54mm:PinHeader_1x04_P2.54mm_Vertical | Connector_PinHeader_2.54mm:PinHeader_1x04_P2.54mm_Vertical | thru-hole | any 4 pin headers with the same foot print and pitch would work
17 | U6 | 2 | Würth Elektronik | 61300811821 | Downloads:DFPlayer | Downloads:DFPlayer | thru-hole | 2 of these headers are required for assembly |  |  | 2pcs per board
18 | Crystal | 1 | Jauch Quartz | Q 0,032768-JTX310-12,5-20-T1-HMR-LF | Crystal:Crystal_SMD_EuroQuartz_EQ161-2Pin_3.2x1.5mm | Crystal:Crystal_SMD_EuroQuartz_EQ161-2Pin_3.2x1.5mm | SMD |  | 7-10 Workdays

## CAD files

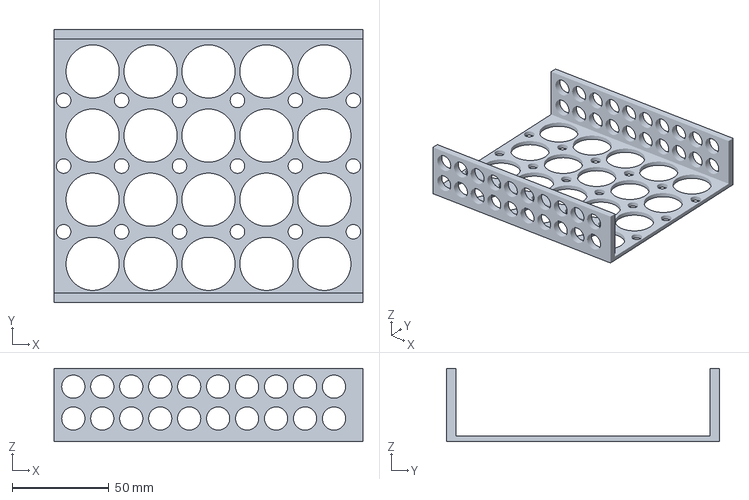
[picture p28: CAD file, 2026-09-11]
Assembly Materials/Assembly Materials/Ambiance Bracket.3mf
160.0 x 141.3 x 38.0 mm

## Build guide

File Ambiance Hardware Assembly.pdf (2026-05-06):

Ambiance Hardware Assembly
Ambiance GitHub Repository: https://github.com/simonnkm/Ambiance
Ambiance WILDLABS Inventory: https://wildlabs.net/en/inventory/products/ambiance

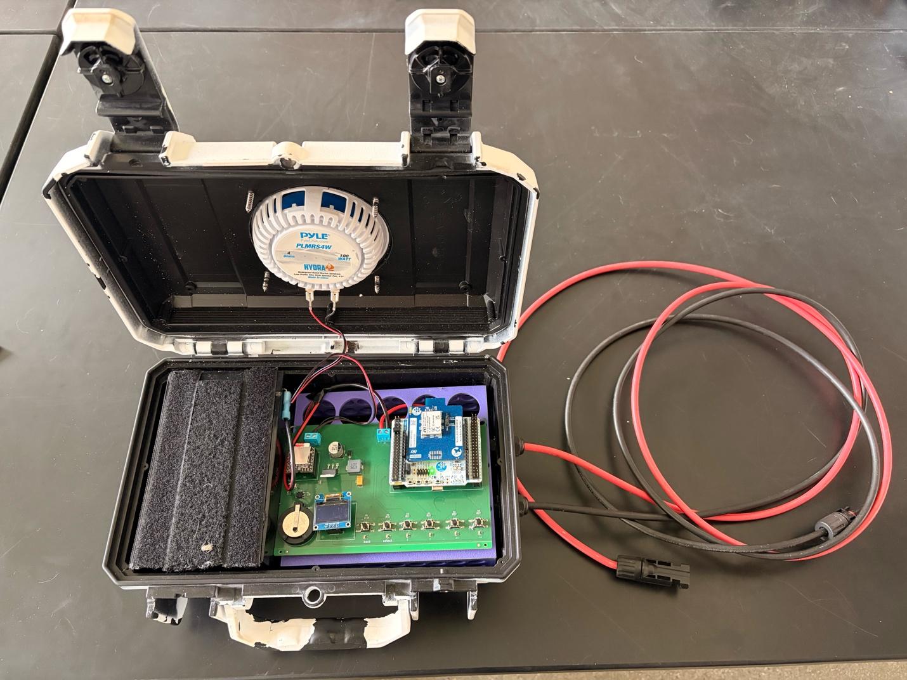
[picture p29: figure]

Figure 1: Overview of assembled Ambiance unit, solar panel not displayed.

Tools Needed:
- Electric Drill
- 3/4 inch and 5/16 inch drill bits
- 7/16 inch tap
- Flathead and Phillips screwdrivers
- 4-inch hole saw
- Wire strippers and powerpole crimpers
- Soldering iron and heat gun kit
- Optional: 3D Printer for internal bracket, reflow oven for efficient PCB assembly

Parts needed:
Printed Circuit Boards:
Boards can be ordered from PCBWay with or without components using this link: https://www.pcbway.com/project/shareproject/Ambiance_Playback_Speaker_8d6dbe2b.html.
*When soldering on components or inspecting soldered boards received from PCBWay inspect the orientation of each component with polarity before connecting to power to ensure the board will not be fried inadvertently. See photo below for component orientation. The boards are designed to be assembled in reflow ovens, however hand soldering will produce the same result but take longer (see here for a tutorial on surface mount soldering: .

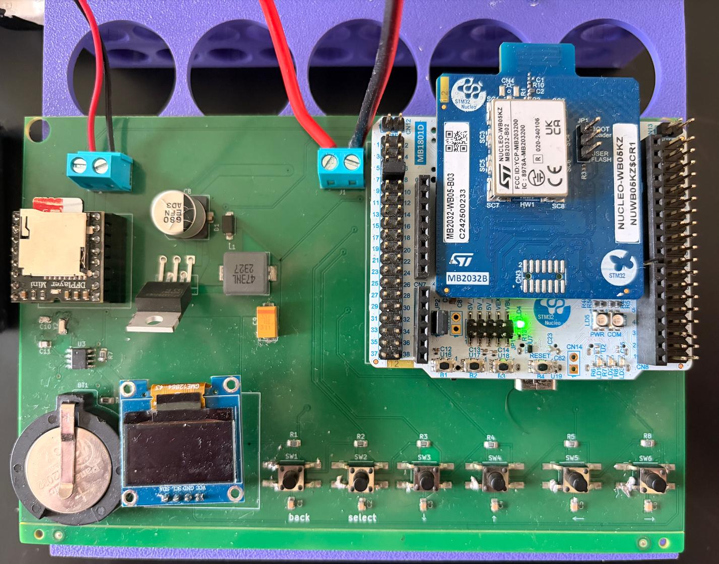
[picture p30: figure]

Figure 2: Detail of PCB components and their orientation.

Several components are placed on headers so that they can easily be removed and replaced in the field without losing the entire board:
- OLED 0.96 inch i2c Display Module (https://shorturl.at/1rHQw)
- DFPlayer Mini DFR0299 (https://shorturl.at/bgHfG) + MircoSD card of choice
- STM32 (NUCLEO-WB05KZ) microcontroller (https://shorturl.at/Fxyu1)
**To install these components on headers position the components in the correct orientation – see images below and apply equal pressure across all pins to slowly press the component towards the PCB until all pins sit nice and flush to the top of the header.

Packaging and Circuitry:
- Seahorse SE230 case (or third party equivalent, e.g., Fuerte Cases): https://tinyurl.com/93t86caj
- Exterior: 11.9 x 8.5 x 4.8" (30 x 22 x 12 cm)
- Interior: 10.6 x 6.1 x 3.9” (27 x 15 x 10 cm)
- Weight: 2.15 lbs (.98 kg.)
- If packed efficiently, 12 of these can be packed into a duffel bag and checked on an airplane in terms of volume.
- Pyle Marine Speaker (2 per pack, 1 per unit): https://tinyurl.com/3chzfc73
- 4-inch, 100-Watt, come with their own o-rings, mounting screws, and wiring
- 40-Watt, Semi-flex, monocrystalline solar panel
- Best sourced locally. This size solar panel can charge the LFP battery listed below in a couple of hours and is sufficient to charge said battery to full on overcast and rainy days on the equator. Depending on local weather and solar exposure, larger or smaller panels may be better suited to local conditions. We found semi-flex solar panels lighter and easier to anchor to the tree canopies we were deploying the Ambiance units on. Panels with gromets are great for looping zip ties through.

- Lithium Iron Phosphate battery (12V, 7-9ah, 6 x 3 x 3.5 inches)
- Best source locally. Batteries this size were capable of maintaining playbacks broadcast at SPL of 80dB at 1m for 10 hours out of a 24-hour cycle (40:60 duty cycle) for 2 days without losing power. Larger or smaller batteries may be better suited for more or less demanding playback schedules.
- PowerWerx MPPT Solar Controller: https://tinyurl.com/y4y3smp4
- This is an incredibly compact, efficient, and reliable solar controller for a great price point. Any MPPT solar controller would suffice but larger controllers will likely require larger enclosures.
- 30 Amp Anderson Powerpole Connectors (1 pair per unit): https://tinyurl.com/5ar4kemr
- 14-16 AWG Insulated Female Spade Connectors (2 per unit): https://tinyurl.com/4xrdy39s
- PG7 Cable Glands (2 per unit): https://tinyurl.com/mw3t4rwh
- 16 AWG Insulated Wire: https://tinyurl.com/tm8k5wtc
- 6mm, 3:1 shrink factor heat shrink (or electrical tape): https://tinyurl.com/4zrc499c
- Thread sealer, silicon, or epoxy that binds plastic to seal cable glands
- Optional: 10AWG insulated wires (e.g., https://tinyurl.com/yc46swsu) and MC4 Connectors (https://tinyurl.com/399v7bjb) for extension cables between Ambiance unit and solar panel.
***Units are modular with the exception of the PCB so locally available parts can be used to replace items listed above.

Assembly Instructions:
1. It is important Ambiance packaging to be light in color, this greatly reduces the amount of heat absorbed into the interior of the unit. Due to the weatherproofing, there is no ventilation into or out of the packaging and earlier Ambiance generations that utilized dark colors resulted in melted lithium iron phosphate batteries when deployed at tropical sites on the equator. Enclosures can be ordered from third-party manufacturers in white or other colors with high albedo, or if this is not an option locally, enclosures can be spray painted white.

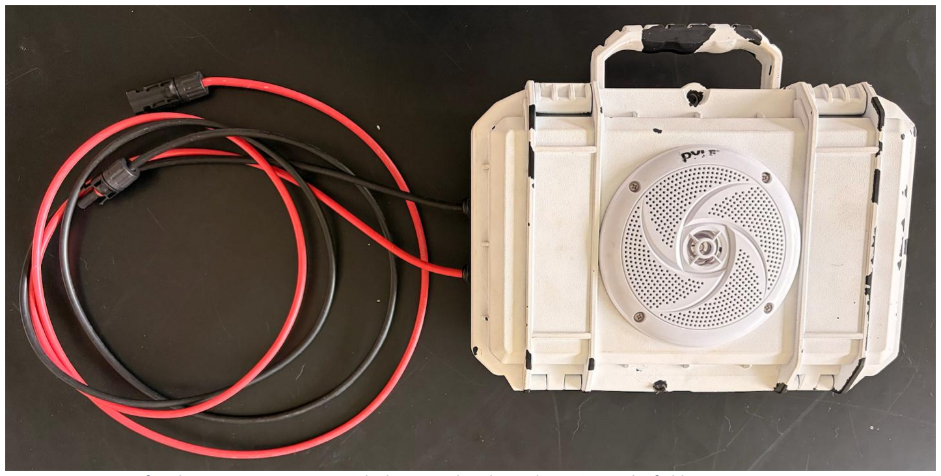
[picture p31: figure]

Figure 3: Exterior of Ambiance SE230 case painted white to reduce heat absorption in the field.

2. Start assembly by drilling the necessary holes in the Seahorse SE230 case. Mark the center point on the upper lid of the SE230 – this will need to be precise as there is only 1-2mm between either side of the 4” Pyle speaker and the raised bevels of the SE230 and use the 4” hole saw to drill a hole at the center point. Next, drill two pilot holes for the positive and negative cables coming from the solar panels using a 5/16” bit on the lower base of the SE230. This should be on one of the short sides of the SE230 and low enough that the incoming solar panel cables will sit below the bracket that the PCB sits on. This will also be on the opposite side the battery sits on. After drilling pilot holes, use the 7/16” tap to drill a larger threaded hole through the pilot holes. Python locks (i.e., cable locks used to lock camera traps to trees) are useful for securing Ambiance units to trees, poles, etc. If you will be using a python lock to secure the Ambiance unit you will need to use a 3/4” bit to widen the preexisting hole on the SE230 and drill an additional hole on the plastic bezel near the hinge. After drilling these two holes, python locks can be threaded through to secure the unit.

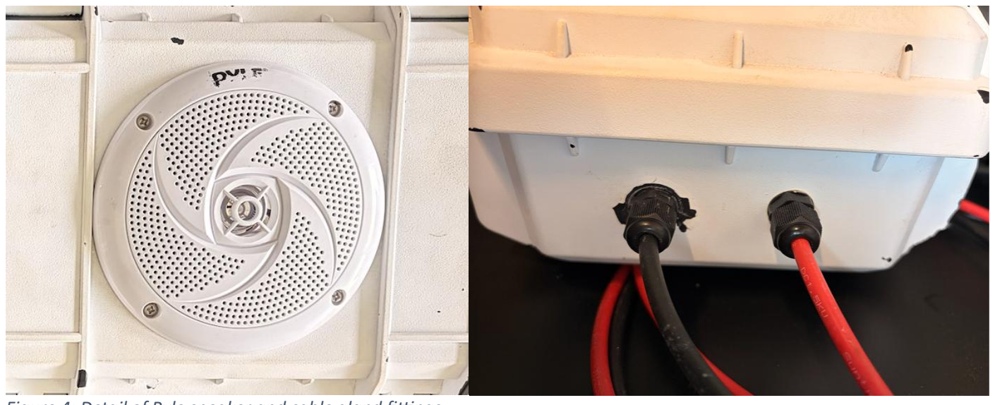
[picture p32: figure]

3. Attach the o-ring that comes with the Pyle speaker around the 4” hole in the lid of the SE230 (sticky side down) and place the Pyle speaker so that the speaker terminals are positioned pointing towards the hinge of the SE230, then drill the four 1” screws through the Pyle speaker, o-ring, and SE230 case. To attach the cable glands, simply screw them on with the gland facing outwards. Apply thread sealer to the thread of the cable gland before screwing the two sides together. Allow time for the thread sealer/epoxy to cure an appropriate amount of time based on the material used before continuing with assembly.
4. Constructing the wiring harness involves cutting two lengths of 16AWG wire – one ~8” and another ~6” - for both the positive and negative connections. Strip both ends of both lengths of wire and and strip about half an inch of insulation midway along the 6” wire. Braid one end of the 8” wire around the stripped center of 6”, solder them together to form a Y-shape (see here for a tutorial: https://www.youtube.com/watch?v=4xUBRMgcVhc), and use heat shrink (applied with a heat gun or lighter) or electrical tape to insulate the joint. On the other end of the 8” wire, crimp a female spade connector. On the end of the 6” wire that forms the other top of the Y, crimp an Anderson Powerpole connector (see here for a tutorial: https://www.youtube.com/watch?v=bZHh3nWXtkw). Repeat this process once more for the other half of the wiring harness. Be sure to insulate any exposed wire to prevent short circuits during operation.

Figure 4: Detail of Pyle speaker and cable gland fittings.

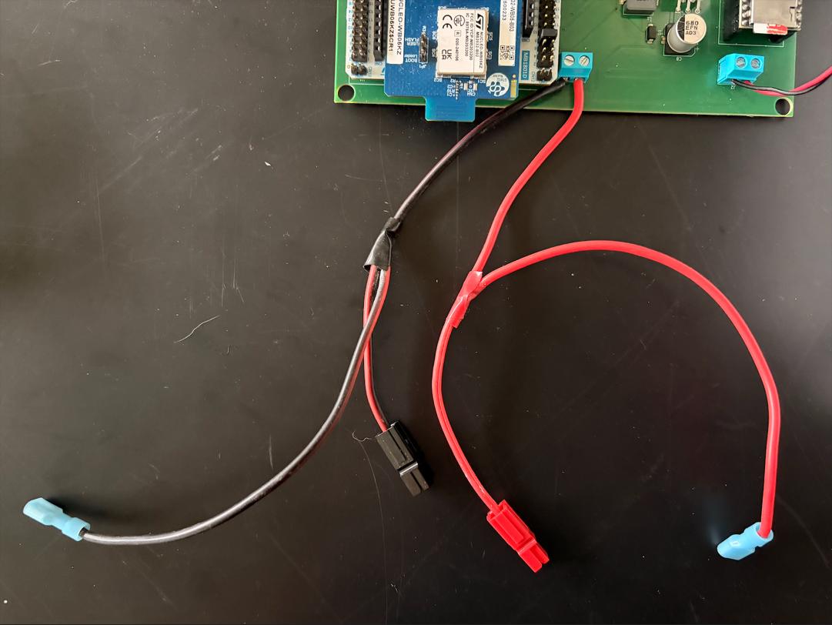
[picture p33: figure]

Figure 5: Detail of wiring harness and attachment to screw terminals.

5. Whether utilizing extension cables (we found 3m extension cables allowed for flexibility when installing Ambiance devices in tree canopies as well as posts on farms and livestock corals) or attaching directly to positive and negative terminals solar panel (normally come with .5m cables), cables will need to be threaded through the cable glands and into the SE230 case before installing MC4 connectors, given the diameter of the MC4 connectors (see here for a tutorial: https://www.youtube.com/watch?v=VrKYlQPHfno).

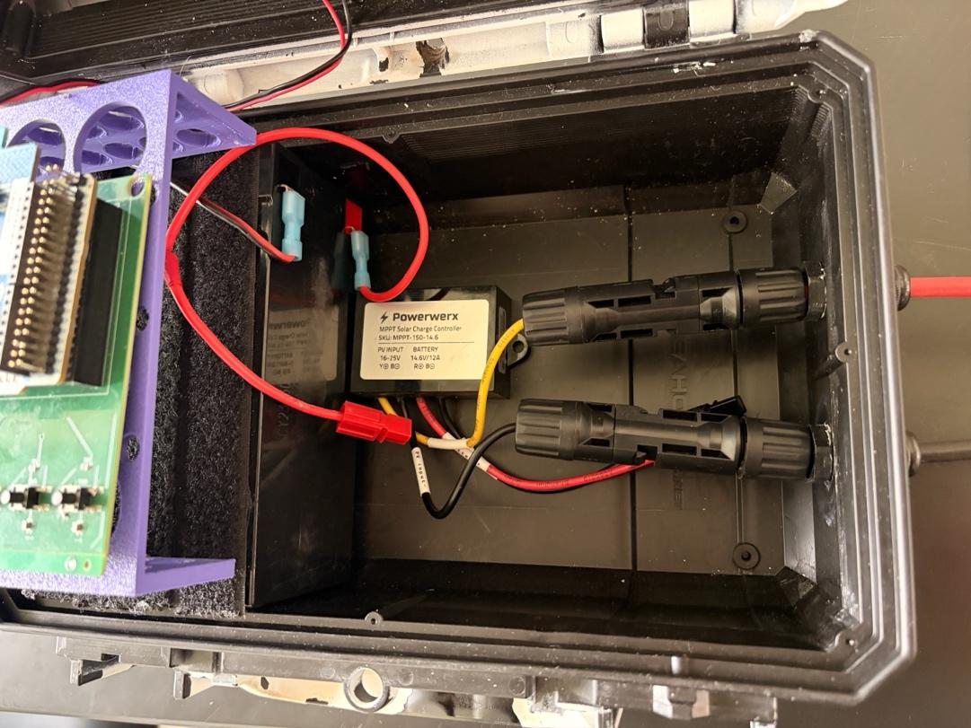
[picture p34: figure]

Figure 6: Detail of MC4 connectors correctly installed inside the SE230 case and attached to the solar controller. They should fit underneath the internal bracket the PCB is mounted to.

6. Use a 3D printer to print the internal bracket (Ambiance Bracket.3mf under Assembly_Materials on the GitHub repository, or find it on Bambu Labs’ Maker World: https://makerworld.com/models/1722885) or utilize a suitable alternative that will lift the PCB a couple of inches off the floor of the Ambiance unit so that there is space for the solar panel cables and MPPT solar controller underneath the bracket.

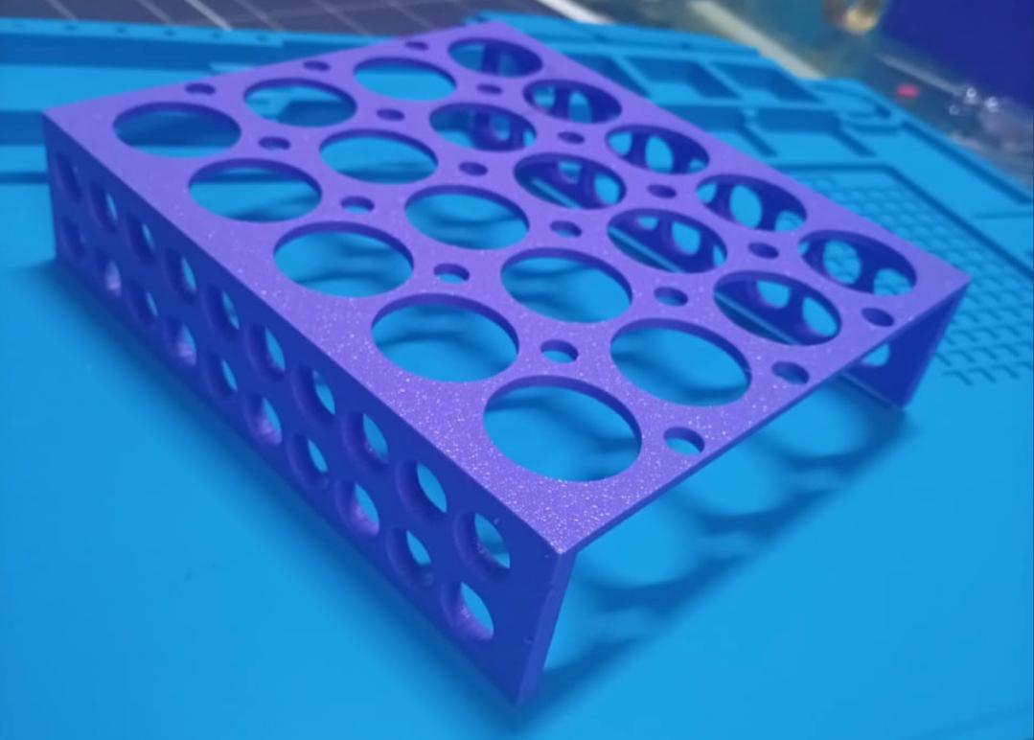
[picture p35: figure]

Figure 7: Detail of internal mounting bracket.

7. We found Velcro to be an effective and economical means to secure various components inside the SE230 case. Secure the LFP battery and MPPT solar controller to the floor of the SE230 case using Velcro. When laid on its side, with the terminals oriented laterally towards the interior of the SE230 case, the battery fits snugly with the interior dimensions of the case, reduces the length of the wiring harness, and provides space for the solar controller. The battery should be installed opposite the solar cables. Now attach the solar cables to the solar controller. It is worth taking the time to double check that negative matches negative and positive matches positive so that nothing shorts out when connected to power. Now attach the wiring harness to the screw terminals on the PCB closest to the STM32 microcontroller using a screwdriver. Make sure you hold the screw terminals to relieve the torque force applied to the screw terminals from the screw driver, otherwise the solder joints on the screw terminal will break. Also take time to confirm positive (red in the image below) and negative (black in the image below) are in the correct positions. You can also utilize the wire provided in the Pyle speaker kit to attach the positive and negative speaker terminals to the second screw terminal in the corner of the PCB, taking time to ensure positive and negative terminals are oriented correctly. Cutting these wires to ~12” in length is sufficient to ensure the SE230 case opens and closes without pulling on the speaker or the screw terminal. Thread the wiring harness through the large holes in the bracket and fasten the positive and negative Anderson Powerpole connectors to their corresponding terminals on the solar controller. Secure the PCB to the internal bracket with Velcro. Lastly, connect the female spade connectors to the LFP battery terminals. At this point if everything has been assembled correctly and the battery is charged. There should be an LED lighting up on the STM32 microcontroller and a menu displayed on the OLED screen (assuming you have flashed the STM32 microcontroller with the proper code, see below). Test the PCB to ensure all of the buttons work for navigating around the menu, if not you may need to resolder some of the joints on these buttons. Multimeters are useful tools for diagnosing faulty circuits. Also ensure you set the correct date and time for the Real Time Clock to keep track of.

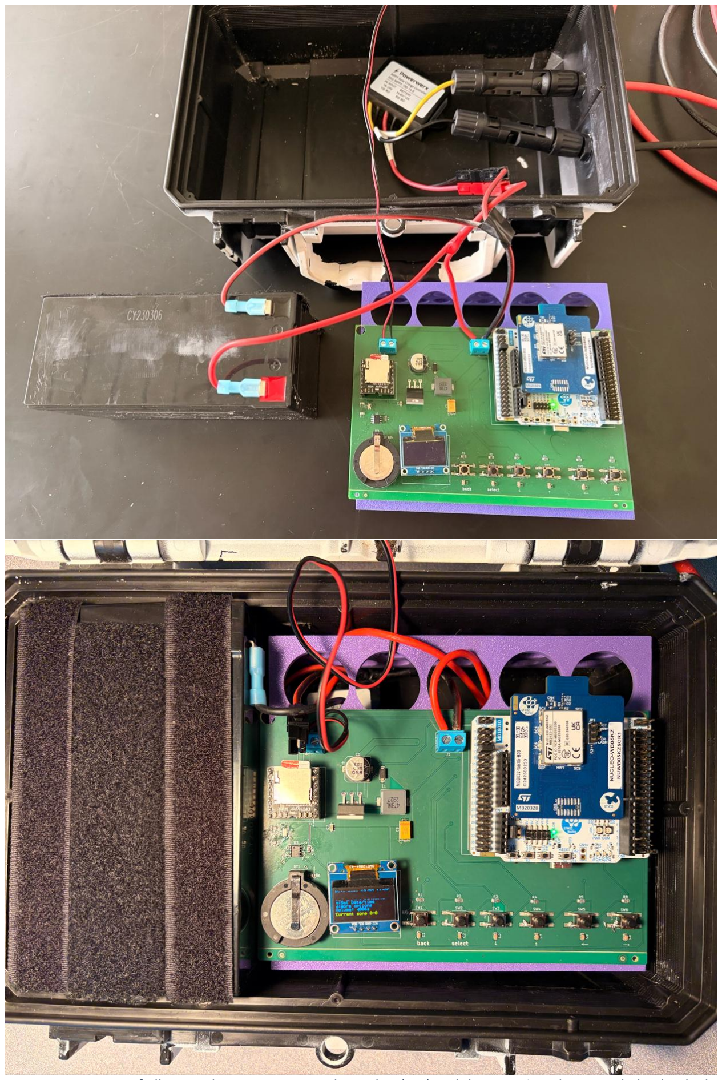
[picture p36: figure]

Figure 8: Overview of all internal components wired together (top) and then positioned as intended to be deployed (bottom).

8. For information on initially flashing STM32 microcontroller, see Ambiance-main on the GitHub repository.

9. For information on assembling and using the Ambiance GUI that allows for efficient Bluetooth programming of playback schedules and other unit parameters, see Ambiance_GUI in the GitHub repository.
10. The DFPlayer mini is extremely fickle so read carefully. It is programmed to accept .mp3 or .wav files on a microSD card formatted in FAT32. Tracks need to be labelled 001, 002, 003, etc. within a playback treatment folder. Playback treatment folders need to be labelled 01, 02, 03, etc. There is only one level of folder organization possible on the DRPlayer mini so do not nest playback treatment folders inside other folders. Tracks are not copied onto the microSD card in alphanumeric order, so the microSD card needs to be sorted through open source software each time the microSD card is inserted into a computer – otherwise tracks will play out of order and out of treatment folders and loops may break. This process also removes hidden files that operating systems automatically load onto microSD cards. These programs are useful for Mac (FatDriveSorter: https://fat-drive-sorter.netlify.app) and Windows (FATSort: https://sourceforge.net/projects/fatsort/). Side note: Audacity is a useful open source software for modifying audio file tracks so that recorded material can broadcast at a SPL of 80dB at 1m (this volume is about the maximum you can force out of a 4” 100 Watt speaker and in an open environment like a grassland you can expect sound to travel audibly for approximately 175m).
11. Schedules can be set either through the buttons on the PCB or through the Ambiance GUI. Schedules are programmed for specific times of day over specified days of each month. To set a schedule across multiple months, you would need to input the same treatment schedules for each month. Treatments can start and stop in 15-minute increments (00, 15, 30, 45 minute of every hour). Multiple treatments can be scheduled for any given 24-hour period to accommodate treatments germane to different parts of the diel cycle, as long as they are not programmed to overlap each other. Once a playback treatment folder is scheduled, tracks from inside that folder will loop through randomly during the prespecified time. Duty cycle ranges from 1-100, where 100 represents constant playback and 1 represents a schedule where 99% of a scheduled treatment period will remain silent and playbacks will only occur during 1% of that period. Duty cycle is calculated and realized based on the previous track length. E.g. on a duty cycle of 40 (40% on, 60% off), a 4-minute track would play and be followed by 6 minutes of silence, then it might be followed by a 2-minute track and subsequent 3 minutes of silence, and so on and so forth. See GUI readme file for more details.

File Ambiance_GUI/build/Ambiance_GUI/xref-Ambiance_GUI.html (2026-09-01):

# modulegraph cross reference for Ambiance_GUI.py, pyi_rth__tkinter.py, pyi_rth_inspect.py, pyi_rth_multiprocessing.py, pyi_rth_pkgutil.py

Ambiance_GUI.py Script

imports: _bootlocale • _collections_abc • _weakrefset • abc • asyncio • bleak • codecs • collections • collections.abc • copyreg • datetime • encodings • encodings.aliases • encodings.ascii • encodings.base64_codec • encodings.big5 • encodings.big5hkscs • encodings.bz2_codec • encodings.charmap • encodings.cp037 • encodings.cp1006 • encodings.cp1026 • encodings.cp1125 • encodings.cp1140 • encodings.cp1250 • encodings.cp1251 • encodings.cp1252 • encodings.cp1253 • encodings.cp1254 • encodings.cp1255 • encodings.cp1256 • encodings.cp1257 • encodings.cp1258 • encodings.cp273 • encodings.cp424 • encodings.cp437 • encodings.cp500 • encodings.cp720 • encodings.cp737 • encodings.cp775 • encodings.cp850 • encodings.cp852 • encodings.cp855 • encodings.cp856 • encodings.cp857 • encodings.cp858 • encodings.cp860 • encodings.cp861 • encodings.cp862 • encodings.cp863 • encodings.cp864 • encodings.cp865 • encodings.cp866 • encodings.cp869 • encodings.cp874 • encodings.cp875 • encodings.cp932 • encodings.cp949 • encodings.cp950 • encodings.euc_jis_2004 • encodings.euc_jisx0213 • encodings.euc_jp • encodings.euc_kr • encodings.gb18030 • encodings.gb2312 • encodings.gbk • encodings.hex_codec • encodings.hp_roman8 • encodings.hz • encodings.idna • encodings.iso2022_jp • encodings.iso2022_jp_1 • encodings.iso2022_jp_2 • encodings.iso2022_jp_2004 • encodings.iso2022_jp_3 • encodings.iso2022_jp_ext • encodings.iso2022_kr • encodings.iso8859_1 • encodings.iso8859_10 • encodings.iso8859_11 • encodings.iso8859_13 • encodings.iso8859_14 • encodings.iso8859_15 • encodings.iso8859_16 • encodings.iso8859_2 • encodings.iso8859_3 • encodings.iso8859_4 • encodings.iso8859_5 • encodings.iso8859_6 • encodings.iso8859_7 • encodings.iso8859_8 • encodings.iso8859_9 • encodings.johab • encodings.koi8_r • encodings.koi8_t • encodings.koi8_u • encodings.kz1048 • encodings.latin_1 • encodings.mac_arabic • encodings.mac_croatian • encodings.mac_cyrillic • encodings.mac_farsi • encodings.mac_greek • encodings.mac_iceland • encodings.mac_latin2 • encodings.mac_roman • encodings.mac_romanian • encodings.mac_turkish • encodings.mbcs • encodings.oem • encodings.palmos • encodings.ptcp154 • encodings.punycode • encodings.quopri_codec • encodings.raw_unicode_escape • encodings.rot_13 • encodings.shift_jis • encodings.shift_jis_2004 • encodings.shift_jisx0213 • encodings.tis_620 • encodings.undefined • encodings.unicode_escape • encodings.utf_16 • encodings.utf_16_be • encodings.utf_16_le • encodings.utf_32 • encodings.utf_32_be • encodings.utf_32_le • encodings.utf_7 • encodings.utf_8 • encodings.utf_8_sig • encodings.uu_codec • encodings.zlib_codec • enum • functools • genericpath • heapq • io • keyword • linecache • locale • ntpath • operator • os • posixpath • pyi_rth__tkinter.py • pyi_rth_inspect.py • pyi_rth_multiprocessing.py • pyi_rth_pkgutil.py • re • reprlib • serial • serial.tools.list_ports • sre_compile • sre_constants • sre_parse • stat • sys • threading • tkinter • tkinter.filedialog • tkinter.ttk • traceback • types • warnings • weakref

pyi_rth__tkinter.py Script

imports: os • sys

imported by: Ambiance_GUI.py

pyi_rth_inspect.py Script

imports: inspect • os • sys • zipfile

imported by: Ambiance_GUI.py

pyi_rth_multiprocessing.py Script

imports: multiprocessing • multiprocessing.spawn • subprocess • sys

imported by: Ambiance_GUI.py

pyi_rth_pkgutil.py Script

imports: pkgutil • pyimod02_importers

imported by: Ambiance_GUI.py

'System.IO' MissingModule

imported by: serial.serialcli

'android.broadcast' MissingModule

imported by: bleak.backends.p4android.scanner

'android.permissions' MissingModule

imported by: bleak.backends.p4android.scanner

'dbus_fast.aio' MissingModule

imported by: bleak.backends.bluezdbus.manager • bleak.backends.bluezdbus.signals

'dbus_fast.auth' MissingModule

imported by: bleak.backends.bluezdbus.utils

'dbus_fast.constants' MissingModule

imported by: bleak.backends.bluezdbus.client • bleak.backends.bluezdbus.utils

'dbus_fast.errors' MissingModule

imported by: bleak.backends.bluezdbus.signals

'dbus_fast.message' MissingModule

imported by: bleak.backends.bluezdbus.client • bleak.backends.bluezdbus.signals • bleak.backends.bluezdbus.utils

'dbus_fast.service' MissingModule

imported by: bleak.backends.bluezdbus.advertisement_monitor

'dbus_fast.signature' MissingModule

imported by: bleak.backends.bluezdbus.client

'dbus_fast.validators' MissingModule

imported by: bleak.backends.bluezdbus.signals

'java.lang' MissingModule

imported by: platform • xml.sax._exceptions

'org.python' MissingModule

imported by: copy • xml.sax

'winrt.windows.applicationmodel' MissingModule

imported by: winrt._winrt_windows_devices_enumeration

'winrt.windows.devices.bluetooth.rfcomm' MissingModule

imported by: winrt._winrt_windows_devices_bluetooth

'winrt.windows.devices.radios' MissingModule

imported by: winrt._winrt_windows_devices_bluetooth

'winrt.windows.networking' MissingModule

imported by: winrt._winrt_windows_devices_bluetooth

'winrt.windows.security' MissingModule

imported by: winrt._winrt_windows_devices_enumeration

'winrt.windows.system' MissingModule

imported by: winrt._winrt_windows_storage_streams

'winrt.windows.ui' MissingModule

imported by: winrt._winrt_windows_devices_enumeration

CoreBluetooth MissingModule

imported by: bleak.backends.corebluetooth.CentralManagerDelegate • bleak.backends.corebluetooth.PeripheralDelegate • bleak.backends.corebluetooth.client • bleak.backends.corebluetooth.scanner • bleak.backends.corebluetooth.utils

Foundation MissingModule

imported by: bleak.backends.corebluetooth.CentralManagerDelegate • bleak.backends.corebluetooth.PeripheralDelegate • bleak.backends.corebluetooth.client • bleak.backends.corebluetooth.scanner

System MissingModule

imported by: serial.serialcli

__future__ SourceModule

imported by: bleak • bleak.backends.bluezdbus.signals • bleak.backends.characteristic • bleak.backends.corebluetooth.PeripheralDelegate • bleak.backends.descriptor • serial • serial.serialcli • serial.serialjava • serial.serialposix • serial.serialutil • serial.serialwin32 • serial.tools.list_ports • serial.tools.list_ports_common • serial.tools.list_ports_linux • serial.tools.list_ports_osx • serial.tools.list_ports_posix • serial.tools.list_ports_windows • serial.win32

_abc (builtin module)

imported by: abc

_ast (builtin module)

imported by: ast

_asyncio C:\Program Files\WindowsApps\PythonSoftwareFoundation.Python.3.9_3.9.3568.0_x64__qbz5n2kfra8p0\DLLs\_asyncio.pyd

imported by: asyncio.events • asyncio.futures • asyncio.tasks

_bisect (builtin module)

imported by: bisect

_blake2 (builtin module)

imported by: hashlib

_bootlocale SourceModule

imports: _locale • locale • sys

imported by: Ambiance_GUI.py • locale

_bz2 C:\Program Files\WindowsApps\PythonSoftwareFoundation.Python.3.9_3.9.3568.0_x64__qbz5n2kfra8p0\DLLs\_bz2.pyd

imported by: bz2

_codecs (builtin module)

imported by: codecs

_codecs_cn (builtin module)

imported by: encodings.gb18030 • encodings.gb2312 • encodings.gbk • encodings.hz

_codecs_hk (builtin module)

imported by: encodings.big5hkscs

_codecs_iso2022 (builtin module)

imported by: encodings.iso2022_jp • encodings.iso2022_jp_1 • encodings.iso2022_jp_2 • encodings.iso2022_jp_2004 • encodings.iso2022_jp_3 • encodings.iso2022_jp_ext • encodings.iso2022_kr

_codecs_jp (builtin module)

imported by: encodings.cp932 • encodings.euc_jis_2004 • encodings.euc_jisx0213 • encodings.euc_jp • encodings.shift_jis • encodings.shift_jis_2004 • encodings.shift_jisx0213

_codecs_kr (builtin module)

imported by: encodings.cp949 • encodings.euc_kr • encodings.johab

_codecs_tw (builtin module)

imported by: encodings.big5 • encodings.cp950

_collections (builtin module)

imported by: collections • threading

_collections_abc SourceModule

imports: abc • sys • warnings

imported by: Ambiance_GUI.py • collections • collections.abc • contextlib • locale • os • pathlib • random • types • weakref

_compat_pickle SourceModule

imported by: _pickle • pickle

_compression SourceModule

imports: io

imported by: bz2 • gzip • lzma

_contextvars (builtin module)

imported by: contextvars

_csv (builtin module)

imported by: csv

_ctypes C:\Program Files\WindowsApps\PythonSoftwareFoundation.Python.3.9_3.9.3568.0_x64__qbz5n2kfra8p0\DLLs\_ctypes.pyd

imported by: ctypes

_datetime (builtin module)

imports: _strptime • time

imported by: datetime

_decimal C:\Program Files\WindowsApps\PythonSoftwareFoundation.Python.3.9_3.9.3568.0_x64__qbz5n2kfra8p0\DLLs\_decimal.pyd

imported by: decimal

_frozen_importlib ExcludedModule

imported by: importlib • importlib.abc • zipimport

_frozen_importlib_external MissingModule

imported by: importlib • importlib._bootstrap • importlib.abc • zipimport

_functools (builtin module)

imported by: functools

_hashlib C:\Program Files\WindowsApps\PythonSoftwareFoundation.Python.3.9_3.9.3568.0_x64__qbz5n2kfra8p0\DLLs\_hashlib.pyd

imported by: hashlib • hmac

_heapq (builtin module)

imported by: heapq

_imp (builtin module)

imported by: importlib • importlib._bootstrap_external • importlib.machinery • importlib.util • zipimport

_io (builtin module)

imported by: importlib._bootstrap_external • io • zipimport

_locale (builtin module)

imported by: _bootlocale • locale • re

_lzma C:\Program Files\WindowsApps\PythonSoftwareFoundation.Python.3.9_3.9.3568.0_x64__qbz5n2kfra8p0\DLLs\_lzma.pyd

imported by: lzma

_md5 (builtin module)

imported by: hashlib

_multibytecodec (builtin module)

imported by: encodings.big5 • encodings.big5hkscs • encodings.cp932 • encodings.cp949 • encodings.cp950 • encodings.euc_jis_2004 • encodings.euc_jisx0213 • encodings.euc_jp • encodings.euc_kr • encodings.gb18030 • encodings.gb2312 • encodings.gbk • encodings.hz • encodings.iso2022_jp • encodings.iso2022_jp_1 • encodings.iso2022_jp_2 • encodings.iso2022_jp_2004 • encodings.iso2022_jp_3 • encodings.iso2022_jp_ext • encodings.iso2022_kr • encodings.johab • encodings.shift_jis • encodings.shift_jis_2004 • encodings.shift_jisx0213

_multiprocessing C:\Program Files\WindowsApps\PythonSoftwareFoundation.Python.3.9_3.9.3568.0_x64__qbz5n2kfra8p0\DLLs\_multiprocessing.pyd

imported by: multiprocessing.connection • multiprocessing.queues • multiprocessing.resource_tracker • multiprocessing.synchronize

_opcode (builtin module)

imported by: opcode

_operator (builtin module)

imported by: hmac • operator

_overlapped C:\Program Files\WindowsApps\PythonSoftwareFoundation.Python.3.9_3.9.3568.0_x64__qbz5n2kfra8p0\DLLs\_overlapped.pyd

imported by: asyncio.windows_events

_pickle (builtin module)

imports: _compat_pickle • codecs • copyreg

imported by: pickle

_posixshmem MissingModule

imported by: multiprocessing.resource_tracker • multiprocessing.shared_memory

_posixsubprocess MissingModule

imports: gc

imported by: multiprocessing.util • subprocess

_py_abc SourceModule

imports: _weakrefset

imported by: abc

_pydecimal SourceModule

imports: collections • contextvars • itertools • locale • math • numbers • re • sys

imported by: decimal

_queue C:\Program Files\WindowsApps\PythonSoftwareFoundation.Python.3.9_3.9.3568.0_x64__qbz5n2kfra8p0\DLLs\_queue.pyd

imported by: queue

_random (builtin module)

imported by: random

_scproxy MissingModule

imported by: urllib.request

_sha1 (builtin module)

imported by: hashlib

_sha256 (builtin module)

imported by: hashlib

_sha3 (builtin module)

imported by: hashlib

_sha512 (builtin module)

imported by: hashlib • random

_signal (builtin module)

imported by: signal

_socket C:\Program Files\WindowsApps\PythonSoftwareFoundation.Python.3.9_3.9.3568.0_x64__qbz5n2kfra8p0\DLLs\_socket.pyd

imported by: socket • typing_extensions

_sre (builtin module)

imports: copy • re

imported by: sre_compile • sre_constants

_ssl C:\Program Files\WindowsApps\PythonSoftwareFoundation.Python.3.9_3.9.3568.0_x64__qbz5n2kfra8p0\DLLs\_ssl.pyd

imports: socket

imported by: ssl

_stat (builtin module)

imported by: stat

_statistics (builtin module)

imported by: statistics

_string (builtin module)

imported by: string

_strptime SourceModule

imports: _thread • calendar • datetime • locale • re • time

imported by: _datetime • datetime • time

_struct (builtin module)

imported by: struct

_thread (builtin module)

imported by: _strptime • asyncio.base_futures • functools • reprlib • tempfile • threading

_threading_local SourceModule

imports: contextlib • threading • weakref

imported by: threading

_tkinter C:\Program Files\WindowsApps\PythonSoftwareFoundation.Python.3.9_3.9.3568.0_x64__qbz5n2kfra8p0\DLLs\_tkinter.pyd

imported by: tkinter

_tracemalloc (builtin module)

imported by: tracemalloc

_uuid C:\Program Files\WindowsApps\PythonSoftwareFoundation.Python.3.9_3.9.3568.0_x64__qbz5n2kfra8p0\DLLs\_uuid.pyd

imported by: uuid

_warnings (builtin module)

imported by: importlib._bootstrap_external • warnings

_weakref (builtin module)

imported by: _weakrefset • collections • weakref • xml.sax.expatreader

_weakrefset SourceModule

imports: _weakref • types

imported by: Ambiance_GUI.py • _py_abc • multiprocessing.process • threading • weakref

_winapi (builtin module)

imported by: asyncio.windows_events • asyncio.windows_utils • encodings • multiprocessing.connection • multiprocessing.heap • multiprocessing.popen_spawn_win32 • multiprocessing.reduction • multiprocessing.shared_memory • multiprocessing.spawn • subprocess

_winreg MissingModule

imported by: platform

abc SourceModule

imports: _abc • _py_abc

imported by: Ambiance_GUI.py • _collections_abc • bleak.backends.client • bleak.backends.scanner • contextlib • email._policybase • functools • importlib.abc • importlib.metadata • inspect • io • multiprocessing.reduction • numbers • os • selectors • typing • typing_extensions • winrt._winrt • winrt._winrt_windows_devices_enumeration • winrt._winrt_windows_foundation • winrt._winrt_windows_foundation_collections • winrt._winrt_windows_storage_streams

android MissingModule

imported by: bleak.backends.p4android.client

annotationlib MissingModule

imported by: typing_extensions

argparse SourceModule

imports: copy • gettext • os • re • shutil • sys • textwrap • warnings

imported by: ast • bleak • calendar • dis • gzip • inspect • serial.tools.list_ports • tarfile • tokenize • zipfile

array (builtin module)

imported by: multiprocessing.dummy • multiprocessing.managers • multiprocessing.reduction • serial.serialposix • serial.serialutil • socket • winrt._winrt

ast SourceModule

imports: _ast • argparse • collections • contextlib • enum • inspect • sys • warnings

imported by: inspect

async_timeout Package

imports: asyncio • enum • sys • types • typing • typing_extensions • warnings

imported by: bleak • bleak.backends.bluezdbus.client • bleak.backends.corebluetooth.CentralManagerDelegate • bleak.backends.corebluetooth.PeripheralDelegate • bleak.backends.p4android.scanner • bleak.backends.winrt.client • bleak.backends.winrt.util

asyncio Package

imports: asyncio • asyncio.DefaultEventLoopPolicy • asyncio.base_events • asyncio.base_futures • asyncio.base_subprocess • asyncio.base_tasks • asyncio.constants • asyncio.coroutines • asyncio.events • asyncio.exceptions • asyncio.format_helpers • asyncio.futures • asyncio.locks • asyncio.proactor_events • asyncio.protocols • asyncio.queues • asyncio.runners • asyncio.selector_events • asyncio.sslproto • asyncio.staggered • asyncio.streams • asyncio.subprocess • asyncio.tasks • asyncio.threads • asyncio.timeout • asyncio.transports • asyncio.trsock • asyncio.unix_events • asyncio.windows_events • asyncio.windows_utils • sys

imported by: Ambiance_GUI.py • async_timeout • asyncio • asyncio.base_events • asyncio.base_futures • asyncio.base_subprocess • asyncio.base_tasks • asyncio.constants • asyncio.coroutines • asyncio.events • asyncio.exceptions • asyncio.format_helpers • asyncio.futures • asyncio.locks • asyncio.log • asyncio.proactor_events • asyncio.protocols • asyncio.queues • asyncio.runners • asyncio.selector_events • asyncio.sslproto • asyncio.staggered • asyncio.streams • asyncio.subprocess • asyncio.tasks • asyncio.threads • asyncio.transports • asyncio.trsock • asyncio.unix_events • asyncio.windows_events • asyncio.windows_utils • bleak • bleak.backends.bluezdbus.client • bleak.backends.bluezdbus.manager • bleak.backends.bluezdbus.version • bleak.backends.corebluetooth.CentralManagerDelegate • bleak.backends.corebluetooth.PeripheralDelegate • bleak.backends.corebluetooth.client • bleak.backends.p4android.client • bleak.backends.p4android.scanner • bleak.backends.p4android.utils • bleak.backends.scanner • bleak.backends.winrt.client • bleak.backends.winrt.scanner • bleak.backends.winrt.util • winrt.runtime._internals

asyncio.DefaultEventLoopPolicy MissingModule

imported by: asyncio • asyncio.events

asyncio.base_events SourceModule

imports: asyncio • asyncio.constants • asyncio.coroutines • asyncio.events • asyncio.exceptions • asyncio.futures • asyncio.log • asyncio.protocols • asyncio.sslproto • asyncio.staggered • asyncio.tasks • asyncio.transports • asyncio.trsock • collections • collections.abc • concurrent.futures • functools • heapq • itertools • os • socket • ssl • stat • subprocess • sys • threading • time • traceback • warnings • weakref

imported by: asyncio • asyncio.proactor_events • asyncio.selector_events • asyncio.unix_events

asyncio.base_futures SourceModule

imports: _thread • asyncio • asyncio.format_helpers • reprlib

imported by: asyncio • asyncio.base_tasks • asyncio.coroutines • asyncio.futures

asyncio.base_subprocess SourceModule

imports: asyncio • asyncio.log • asyncio.protocols • asyncio.transports • collections • subprocess • warnings

imported by: asyncio • asyncio.unix_events • asyncio.windows_events

asyncio.base_tasks SourceModule

imports: asyncio • asyncio.base_futures • asyncio.coroutines • linecache • traceback

imported by: asyncio • asyncio.tasks

asyncio.constants SourceModule

imports: asyncio • enum

imported by: asyncio • asyncio.base_events • asyncio.coroutines • asyncio.format_helpers • asyncio.proactor_events • asyncio.selector_events • asyncio.sslproto • asyncio.unix_events

asyncio.coroutines SourceModule

imports: asyncio • asyncio.base_futures • asyncio.constants • asyncio.format_helpers • asyncio.log • collections.abc • functools • inspect • os • sys • traceback • types • warnings

imported by: asyncio • asyncio.base_events • asyncio.base_tasks • asyncio.runners • asyncio.streams • asyncio.tasks • asyncio.unix_events • typing_extensions

asyncio.events SourceModule

imports: _asyncio • asyncio • asyncio.DefaultEventLoopPolicy • asyncio.format_helpers • contextvars • os • socket • subprocess • sys • threading

imported by: asyncio • asyncio.base_events • asyncio.futures • asyncio.locks • asyncio.queues • asyncio.runners • asyncio.selector_events • asyncio.staggered • asyncio.streams • asyncio.subprocess • asyncio.tasks • asyncio.threads • asyncio.unix_events • asyncio.windows_events

asyncio.exceptions SourceModule

imports: asyncio

imported by: asyncio • asyncio.base_events • asyncio.futures • asyncio.locks • asyncio.proactor_events • asyncio.staggered • asyncio.streams • asyncio.tasks • asyncio.unix_events • asyncio.windows_events

asyncio.format_helpers SourceModule

imports: asyncio • asyncio.constants • functools • inspect • reprlib • sys • traceback

imported by: asyncio • asyncio.base_futures • asyncio.coroutines • asyncio.events • asyncio.futures • asyncio.streams

asyncio.futures SourceModule

imports: _asyncio • asyncio • asyncio.base_futures • asyncio.events • asyncio.exceptions • asyncio.format_helpers • concurrent.futures • contextvars • logging • sys • types

imported by: asyncio • asyncio.base_events • asyncio.proactor_events • asyncio.selector_events • asyncio.tasks • asyncio.unix_events • asyncio.windows_events

asyncio.locks SourceModule

imports: asyncio • asyncio.events • asyncio.exceptions • collections • warnings

imported by: asyncio • asyncio.queues • asyncio.staggered

asyncio.log SourceModule

imports: asyncio • logging

imported by: asyncio.base_events • asyncio.base_subprocess • asyncio.coroutines • asyncio.proactor_events • asyncio.selector_events • asyncio.sslproto • asyncio.streams • asyncio.subprocess • asyncio.unix_events • asyncio.windows_events

asyncio.proactor_events SourceModule

imports: asyncio • asyncio.base_events • asyncio.constants • asyncio.exceptions • asyncio.futures • asyncio.log • asyncio.protocols • asyncio.sslproto • asyncio.transports • asyncio.trsock • collections • io • os • signal • socket • threading • warnings

imported by: asyncio • asyncio.windows_events

asyncio.protocols SourceModule

imports: asyncio

imported by: asyncio • asyncio.base_events • asyncio.base_subprocess • asyncio.proactor_events • asyncio.selector_events • asyncio.sslproto • asyncio.streams • asyncio.subprocess

asyncio.queues SourceModule

imports: asyncio • asyncio.events • asyncio.locks • collections • heapq • types • warnings

imported by: asyncio • asyncio.tasks

asyncio.runners SourceModule

imports: asyncio • asyncio.coroutines • asyncio.events • asyncio.tasks

imported by: asyncio

asyncio.selector_events SourceModule

imports: asyncio • asyncio.base_events • asyncio.constants • asyncio.events • asyncio.futures • asyncio.log • asyncio.protocols • asyncio.sslproto • asyncio.transports • asyncio.trsock • collections • errno • functools • selectors • socket • ssl • warnings • weakref

imported by: asyncio • asyncio.unix_events • asyncio.windows_events

asyncio.sslproto SourceModule

imports: asyncio • asyncio.constants • asyncio.log • asyncio.protocols • asyncio.transports • collections • ssl • warnings

imported by: asyncio • asyncio.base_events • asyncio.proactor_events • asyncio.selector_events

asyncio.staggered SourceModule

imports: asyncio • asyncio.events • asyncio.exceptions • asyncio.locks • asyncio.tasks • contextlib • typing

imported by: asyncio • asyncio.base_events

asyncio.streams SourceModule

imports: asyncio • asyncio.coroutines • asyncio.events • asyncio.exceptions • asyncio.format_helpers • asyncio.log • asyncio.protocols • asyncio.tasks • socket • sys • warnings • weakref

imported by: asyncio • asyncio.subprocess

asyncio.subprocess SourceModule

imports: asyncio • asyncio.events • asyncio.log • asyncio.protocols • asyncio.streams • asyncio.tasks • subprocess • warnings

imported by: asyncio

asyncio.tasks SourceModule

imports: _asyncio • asyncio • asyncio.base_tasks • asyncio.coroutines • asyncio.events • asyncio.exceptions • asyncio.futures • asyncio.queues • concurrent.futures • contextvars • functools • inspect • itertools • types • warnings • weakref

imported by: asyncio • asyncio.base_events • asyncio.runners • asyncio.staggered • asyncio.streams • asyncio.subprocess • asyncio.unix_events • asyncio.windows_events

asyncio.threads SourceModule

imports: asyncio • asyncio.events • contextvars • functools

imported by: asyncio

asyncio.timeout MissingModule

imported by: asyncio • bleak • bleak.backends.bluezdbus.client • bleak.backends.corebluetooth.CentralManagerDelegate • bleak.backends.corebluetooth.PeripheralDelegate • bleak.backends.p4android.scanner • bleak.backends.winrt.client • bleak.backends.winrt.util

asyncio.transports SourceModule

imports: asyncio

imported by: asyncio • asyncio.base_events • asyncio.base_subprocess • asyncio.proactor_events • asyncio.selector_events • asyncio.sslproto • asyncio.unix_events

asyncio.trsock SourceModule

imports: asyncio • socket • warnings

imported by: asyncio • asyncio.base_events • asyncio.proactor_events • asyncio.selector_events

asyncio.unix_events SourceModule

imports: asyncio • asyncio.base_events • asyncio.base_subprocess • asyncio.constants • asyncio.coroutines • asyncio.events • asyncio.exceptions • asyncio.futures • asyncio.log • asyncio.selector_events • asyncio.tasks • asyncio.transports • errno • io • itertools • os • selectors • signal • socket • stat • subprocess • sys • threading • warnings

imported by: asyncio

asyncio.windows_events SourceModule

imports: _overlapped • _winapi • asyncio • asyncio.base_subprocess • asyncio.events • asyncio.exceptions • asyncio.futures • asyncio.log • asyncio.proactor_events • asyncio.selector_events • asyncio.tasks • asyncio.windows_utils • errno • math • msvcrt • socket • struct • sys • time • weakref

imported by: asyncio

asyncio.windows_utils SourceModule

imports: _winapi • asyncio • itertools • msvcrt • os • subprocess • sys • tempfile • warnings

imported by: asyncio • asyncio.windows_events

atexit (builtin module)

imported by: logging • multiprocessing.util • weakref

base64 SourceModule

imports: binascii • getopt • re • struct • sys

imported by: email._encoded_words • email.base64mime • email.encoders • encodings.base64_codec • secrets • ssl • urllib.request • xmlrpc.client

binascii (builtin module)

imported by: base64 • email._encoded_words • email.base64mime • email.contentmanager • email.header • encodings.hex_codec • encodings.uu_codec • quopri • secrets • uu • zipfile

bisect SourceModule

imports: _bisect

imported by: multiprocessing.heap • random • statistics • urllib.request

bleak Package

imports: __future__ • argparse • async_timeout • asyncio • asyncio.timeout • bleak.args.bluez • bleak.args.corebluetooth • bleak.args.winrt • bleak.backends.characteristic • bleak.backends.client • bleak.backends.descriptor • bleak.backends.device • bleak.backends.scanner • bleak.backends.service • bleak.exc • bleak.uuids • collections.abc • functools • inspect • logging • os • sys • types • typing • typing_extensions • uuid

imported by: Ambiance_GUI.py • bleak.args • bleak.assigned_numbers • bleak.backends • bleak.backends.bluezdbus.client • bleak.backends.corebluetooth.client • bleak.backends.winrt.client • bleak.exc • bleak.uuids

bleak.args Package

imports: bleak

imported by: bleak.args.bluez • bleak.args.corebluetooth • bleak.args.winrt

bleak.args.bluez SourceModule

imports: bleak.args • bleak.assigned_numbers • typing

imported by: bleak • bleak.backends.bluezdbus.advertisement_monitor • bleak.backends.bluezdbus.manager • bleak.backends.bluezdbus.scanner

bleak.args.corebluetooth SourceModule

imports: bleak.args • collections.abc • typing

imported by: bleak • bleak.backends.corebluetooth.PeripheralDelegate • bleak.backends.corebluetooth.client • bleak.backends.corebluetooth.scanner

bleak.args.winrt SourceModule

imports: bleak.args • typing

imported by: bleak • bleak.backends.winrt.client

bleak.assigned_numbers SourceModule

imports: bleak • enum • typing

imported by: bleak.args.bluez • bleak.backends.bluezdbus.defs • bleak.backends.characteristic • bleak.backends.corebluetooth.client • bleak.backends.p4android.client • bleak.backends.winrt.client • bleak.backends.winrt.scanner

bleak.backends Package

imports: bleak

imported by: bleak.backends.bluezdbus • bleak.backends.characteristic • bleak.backends.client • bleak.backends.corebluetooth • bleak.backends.descriptor • bleak.backends.device • bleak.backends.p4android • bleak.backends.scanner • bleak.backends.service • bleak.backends.winrt

bleak.backends.bluezdbus Package

imports: bleak.backends • bleak.backends.bluezdbus.defs

imported by: bleak.backends.bluezdbus.advertisement_monitor • bleak.backends.bluezdbus.client • bleak.backends.bluezdbus.defs • bleak.backends.bluezdbus.manager • bleak.backends.bluezdbus.scanner • bleak.backends.bluezdbus.signals • bleak.backends.bluezdbus.utils • bleak.backends.bluezdbus.version

bleak.backends.bluezdbus.advertisement_monitor SourceModule

imports: 'dbus_fast.service' • bleak.args.bluez • bleak.backends.bluezdbus • bleak.backends.bluezdbus.defs • collections.abc • dbus_fast • logging • sys • typing • warnings

imported by: bleak.backends.bluezdbus.manager

bleak.backends.bluezdbus.client SourceModule

imports: 'dbus_fast.constants' • 'dbus_fast.message' • 'dbus_fast.signature' • async_timeout • asyncio • asyncio.timeout • bleak • bleak.backends.bluezdbus • bleak.backends.bluezdbus.defs • bleak.backends.bluezdbus.manager • bleak.backends.bluezdbus.scanner • bleak.backends.bluezdbus.utils • bleak.backends.bluezdbus.version • bleak.backends.characteristic • bleak.backends.client • bleak.backends.descriptor • bleak.backends.device • bleak.backends.service • bleak.exc • collections.abc • contextlib • dbus_fast • logging • os • sys • typing • typing_extensions • warnings

imported by: bleak.backends.client

bleak.backends.bluezdbus.defs SourceModule

imports: bleak.assigned_numbers • bleak.backends.bluezdbus • typing

imported by: bleak.backends.bluezdbus • bleak.backends.bluezdbus.advertisement_monitor • bleak.backends.bluezdbus.client • bleak.backends.bluezdbus.manager • bleak.backends.bluezdbus.scanner

bleak.backends.bluezdbus.manager SourceModule

imports: 'dbus_fast.aio' • asyncio • bleak.args.bluez • bleak.backends.bluezdbus • bleak.backends.bluezdbus.advertisement_monitor • bleak.backends.bluezdbus.defs • bleak.backends.bluezdbus.signals • bleak.backends.bluezdbus.utils • bleak.backends.characteristic • bleak.backends.descriptor • bleak.backends.service • bleak.exc • collections • collections.abc • contextlib • dbus_fast • functools • logging • os • sys • typing • weakref

imported by: bleak.backends.bluezdbus.client • bleak.backends.bluezdbus.scanner

bleak.backends.bluezdbus.scanner SourceModule

imports: bleak.args.bluez • bleak.backends.bluezdbus • bleak.backends.bluezdbus.defs • bleak.backends.bluezdbus.manager • bleak.backends.scanner • bleak.exc • collections.abc • dbus_fast • logging • sys • typing • typing_extensions • warnings

imported by: bleak.backends.bluezdbus.client • bleak.backends.scanner

bleak.backends.bluezdbus.signals SourceModule

imports: 'dbus_fast.aio' • 'dbus_fast.errors' • 'dbus_fast.message' • 'dbus_fast.validators' • __future__ • bleak.backends.bluezdbus • re • sys • typing

imported by: bleak.backends.bluezdbus.manager

bleak.backends.bluezdbus.utils SourceModule

imports: 'dbus_fast.auth' • 'dbus_fast.constants' • 'dbus_fast.message' • bleak.backends.bluezdbus • bleak.exc • os • sys • typing

imported by: bleak.backends.bluezdbus.client • bleak.backends.bluezdbus.manager

bleak.backends.bluezdbus.version SourceModule

imports: asyncio • bleak.backends.bluezdbus • contextlib • logging • re • sys • typing

imported by: bleak.backends.bluezdbus.client

bleak.backends.characteristic SourceModule

imports: __future__ • bleak.assigned_numbers • bleak.backends • bleak.backends.descriptor • bleak.backends.service • bleak.uuids • collections.abc • enum • typing • uuid

imported by: bleak • bleak.backends.bluezdbus.client • bleak.backends.bluezdbus.manager • bleak.backends.client • bleak.backends.corebluetooth.client • bleak.backends.descriptor • bleak.backends.p4android.client • bleak.backends.service • bleak.backends.winrt.client

bleak.backends.client SourceModule

imports: abc • bleak.backends • bleak.backends.bluezdbus.client • bleak.backends.characteristic • bleak.backends.corebluetooth.client • bleak.backends.descriptor • bleak.backends.device • bleak.backends.p4android.client • bleak.backends.service • bleak.backends.winrt.client • bleak.exc • bleak_pythonista • collections.abc • os • platform • sys • typing • typing_extensions

imported by: bleak • bleak.backends.bluezdbus.client • bleak.backends.corebluetooth.PeripheralDelegate • bleak.backends.corebluetooth.client • bleak.backends.p4android.client • bleak.backends.winrt.client

bleak.backends.corebluetooth Package

imports: bleak.backends • objc • sys • typing

imported by: bleak.backends.corebluetooth.CentralManagerDelegate • bleak.backends.corebluetooth.PeripheralDelegate • bleak.backends.corebluetooth.client • bleak.backends.corebluetooth.scanner • bleak.backends.corebluetooth.utils

bleak.backends.corebluetooth.CentralManagerDelegate SourceModule

imports: CoreBluetooth • Foundation • async_timeout • asyncio • asyncio.timeout • bleak.backends.corebluetooth • bleak.exc • collections.abc • libdispatch • logging • objc • sys • threading • typing • typing_extensions

imported by: bleak.backends.corebluetooth.client • bleak.backends.corebluetooth.scanner

bleak.backends.corebluetooth.PeripheralDelegate SourceModule

imports: CoreBluetooth • Foundation • __future__ • async_timeout • asyncio • asyncio.timeout • bleak.args.corebluetooth • bleak.backends.client • bleak.backends.corebluetooth • bleak.exc • collections.abc • itertools • logging • objc • sys • typing

imported by: bleak.backends.corebluetooth.client

bleak.backends.corebluetooth.client SourceModule

imports: CoreBluetooth • Foundation • asyncio • bleak • bleak.args.corebluetooth • bleak.assigned_numbers • bleak.backends.characteristic • bleak.backends.client • bleak.backends.corebluetooth • bleak.backends.corebluetooth.CentralManagerDelegate • bleak.backends.corebluetooth.PeripheralDelegate • bleak.backends.corebluetooth.scanner • bleak.backends.corebluetooth.utils • bleak.backends.descriptor • bleak.backends.device • bleak.backends.service • bleak.exc • collections.abc • logging • sys • typing • typing_extensions

imported by: bleak.backends.client

bleak.backends.corebluetooth.scanner SourceModule

imports: CoreBluetooth • Foundation • bleak.args.corebluetooth • bleak.backends.corebluetooth • bleak.backends.corebluetooth.CentralManagerDelegate • bleak.backends.corebluetooth.utils • bleak.backends.scanner • bleak.exc • logging • objc • sys • typing • typing_extensions • warnings

imported by: bleak.backends.corebluetooth.client • bleak.backends.scanner

bleak.backends.corebluetooth.utils SourceModule

imports: CoreBluetooth • bleak.backends.corebluetooth • bleak.uuids • sys • typing

imported by: bleak.backends.corebluetooth.client • bleak.backends.corebluetooth.scanner

bleak.backends.descriptor SourceModule

imports: __future__ • bleak.backends • bleak.backends.characteristic • bleak.uuids • typing

imported by: bleak • bleak.backends.bluezdbus.client • bleak.backends.bluezdbus.manager • bleak.backends.characteristic • bleak.backends.client • bleak.backends.corebluetooth.client • bleak.backends.p4android.client • bleak.backends.service • bleak.backends.winrt.client

bleak.backends.device SourceModule

imports: bleak.backends • typing • warnings

imported by: bleak • bleak.backends.bluezdbus.client • bleak.backends.client • bleak.backends.corebluetooth.client • bleak.backends.p4android.client • bleak.backends.scanner • bleak.backends.winrt.client

bleak.backends.p4android Package

imports: bleak.backends • bleak.backends.p4android.defs • bleak.backends.p4android.utils

imported by: bleak.backends.p4android.client • bleak.backends.p4android.defs • bleak.backends.p4android.scanner • bleak.backends.p4android.utils

bleak.backends.p4android.client SourceModule

imports: android • asyncio • bleak.assigned_numbers • bleak.backends.characteristic • bleak.backends.client • bleak.backends.descriptor • bleak.backends.device • bleak.backends.p4android • bleak.backends.p4android.defs • bleak.backends.p4android.utils • bleak.backends.service • bleak.exc • jnius • logging • sys • typing • typing_extensions • uuid • warnings

imported by: bleak.backends.client

bleak.backends.p4android.defs SourceModule

imports: bleak.backends.p4android • bleak.exc • bleak.uuids • enum • jnius • sys • typing

imported by: bleak.backends.p4android • bleak.backends.p4android.client • bleak.backends.p4android.scanner

bleak.backends.p4android.scanner SourceModule

imports: 'android.broadcast' • 'android.permissions' • async_timeout • asyncio • asyncio.timeout • bleak.backends.p4android • bleak.backends.p4android.defs • bleak.backends.p4android.utils • bleak.backends.scanner • bleak.exc • jnius • logging • sys • typing • typing_extensions • warnings

imported by: bleak.backends.scanner

bleak.backends.p4android.utils SourceModule

imports: asyncio • bleak.backends.p4android • bleak.exc • jnius • logging • sys • typing • warnings

imported by: bleak.backends.p4android • bleak.backends.p4android.client • bleak.backends.p4android.scanner

bleak.backends.scanner SourceModule

imports: abc • asyncio • bleak.backends • bleak.backends.bluezdbus.scanner • bleak.backends.corebluetooth.scanner • bleak.backends.device • bleak.backends.p4android.scanner • bleak.backends.winrt.scanner • bleak.exc • bleak_pythonista • collections.abc • inspect • os • platform • sys • typing

imported by: bleak • bleak.backends.bluezdbus.scanner • bleak.backends.corebluetooth.scanner • bleak.backends.p4android.scanner • bleak.backends.winrt.scanner

bleak.backends.service SourceModule

imports: bleak.backends • bleak.backends.characteristic • bleak.backends.descriptor • bleak.exc • bleak.uuids • collections.abc • logging • typing • uuid

imported by: bleak • bleak.backends.bluezdbus.client • bleak.backends.bluezdbus.manager • bleak.backends.characteristic • bleak.backends.client • bleak.backends.corebluetooth.client • bleak.backends.p4android.client • bleak.backends.winrt.client

bleak.backends.winrt Package

imports: bleak.backends

imported by: bleak.backends.winrt.client • bleak.backends.winrt.scanner • bleak.backends.winrt.util

bleak.backends.winrt.client SourceModule

imports: async_timeout • asyncio • asyncio.timeout • bleak • bleak.args.winrt • bleak.assigned_numbers • bleak.backends.characteristic • bleak.backends.client • bleak.backends.descriptor • bleak.backends.device • bleak.backends.service • bleak.backends.winrt • bleak.backends.winrt.scanner • bleak.exc • collections.abc • contextvars • ctypes • logging • sys • typing • typing_extensions • uuid • warnings • winrt.system • winrt.windows.devices.bluetooth • winrt.windows.devices.bluetooth.genericattributeprofile • winrt.windows.devices.enumeration • winrt.windows.foundation • winrt.windows.storage.streams

imported by: bleak.backends.client

bleak.backends.winrt.scanner SourceModule

imports: asyncio • bleak.assigned_numbers • bleak.backends.scanner • bleak.backends.winrt • bleak.backends.winrt.util • bleak.exc • bleak.uuids • logging • sys • typing • typing_extensions • uuid • winrt.windows.devices.bluetooth.advertisement • winrt.windows.foundation

imported by: bleak.backends.scanner • bleak.backends.winrt.client

bleak.backends.winrt.util SourceModule

imports: async_timeout • asyncio • asyncio.timeout • bleak.backends.winrt • bleak.exc • ctypes • ctypes.wintypes • enum • sys • typing

imported by: bleak.backends.winrt.scanner

bleak.exc SourceModule

imports: bleak • typing • uuid

imported by: bleak • bleak.backends.bluezdbus.client • bleak.backends.bluezdbus.manager • bleak.backends.bluezdbus.scanner • bleak.backends.bluezdbus.utils • bleak.backends.client • bleak.backends.corebluetooth.CentralManagerDelegate • bleak.backends.corebluetooth.PeripheralDelegate • bleak.backends.corebluetooth.client • bleak.backends.corebluetooth.scanner • bleak.backends.p4android.client • bleak.backends.p4android.defs • bleak.backends.p4android.scanner • bleak.backends.p4android.utils • bleak.backends.scanner • bleak.backends.service • bleak.backends.winrt.client • bleak.backends.winrt.scanner • bleak.backends.winrt.util

bleak.uuids SourceModule

imports: bleak • uuid

imported by: bleak • bleak.backends.characteristic • bleak.backends.corebluetooth.utils • bleak.backends.descriptor • bleak.backends.p4android.defs • bleak.backends.service • bleak.backends.winrt.scanner

bleak_pythonista MissingModule

imported by: bleak.backends.client • bleak.backends.scanner

builtins (builtin module)

imported by: bz2 • codecs • gettext • gzip • inspect • locale • lzma • operator • reprlib • subprocess • tarfile • tokenize • typing_extensions • warnings • winrt._winrt_windows_devices_bluetooth • winrt._winrt_windows_devices_bluetooth_advertisement • winrt._winrt_windows_devices_bluetooth_genericattributeprofile • winrt._winrt_windows_devices_enumeration • winrt._winrt_windows_foundation • winrt._winrt_windows_foundation_collections • winrt._winrt_windows_storage_streams

bz2 SourceModule

imports: _bz2 • _compression • builtins • io • os • threading

imported by: encodings.bz2_codec • shutil • tarfile • zipfile

calendar SourceModule

imports: argparse • datetime • itertools • locale • sys

imported by: _strptime • email._parseaddr • http.cookiejar • ssl

codecs SourceModule

imports: _codecs • builtins • encodings • sys

imported by: Ambiance_GUI.py • _pickle • encodings • encodings.ascii • encodings.base64_codec • encodings.big5 • encodings.big5hkscs • encodings.bz2_codec • encodings.charmap • encodings.cp037 • encodings.cp1006 • encodings.cp1026 • encodings.cp1125 • encodings.cp1140 • encodings.cp1250 • encodings.cp1251 • encodings.cp1252 • encodings.cp1253 • encodings.cp1254 • encodings.cp1255 • encodings.cp1256 • encodings.cp1257 • encodings.cp1258 • encodings.cp273 • encodings.cp424 • encodings.cp437 • encodings.cp500 • encodings.cp720 • encodings.cp737 • encodings.cp775 • encodings.cp850 • encodings.cp852 • encodings.cp855 • encodings.cp856 • encodings.cp857 • encodings.cp858 • encodings.cp860 • encodings.cp861 • encodings.cp862 • encodings.cp863 • encodings.cp864 • encodings.cp865 • encodings.cp866 • encodings.cp869 • encodings.cp874 • encodings.cp875 • encodings.cp932 • encodings.cp949 • encodings.cp950 • encodings.euc_jis_2004 • encodings.euc_jisx0213 • encodings.euc_jp • encodings.euc_kr • encodings.gb18030 • encodings.gb2312 • encodings.gbk • encodings.hex_codec • encodings.hp_roman8 • encodings.hz • encodings.idna • encodings.iso2022_jp • encodings.iso2022_jp_1 • encodings.iso2022_jp_2 • encodings.iso2022_jp_2004 • encodings.iso2022_jp_3 • encodings.iso2022_jp_ext • encodings.iso2022_kr • encodings.iso8859_1 • encodings.iso8859_10 • encodings.iso8859_11 • encodings.iso8859_13 • encodings.iso8859_14 • encodings.iso8859_15 • encodings.iso8859_16 • encodings.iso8859_2 • encodings.iso8859_3 • encodings.iso8859_4 • encodings.iso8859_5 • encodings.iso8859_6 • encodings.iso8859_7 • encodings.iso8859_8 • encodings.iso8859_9 • encodings.johab • encodings.koi8_r • encodings.koi8_t • encodings.koi8_u • encodings.kz1048 • encodings.latin_1 • encodings.mac_arabic • encodings.mac_croatian • encodings.mac_cyrillic • encodings.mac_farsi • encodings.mac_greek • encodings.mac_iceland • encodings.mac_latin2 • encodings.mac_roman • encodings.mac_romanian • encodings.mac_turkish • encodings.mbcs • encodings.oem • encodings.palmos • encodings.ptcp154 • encodings.punycode • encodings.quopri_codec • encodings.raw_unicode_escape • encodings.rot_13 • encodings.shift_jis • encodings.shift_jis_2004 • encodings.shift_jisx0213 • encodings.tis_620 • encodings.undefined • encodings.unicode_escape • encodings.utf_16 • encodings.utf_16_be • encodings.utf_16_le • encodings.utf_32 • encodings.utf_32_be • encodings.utf_32_le • encodings.utf_7 • encodings.utf_8 • encodings.utf_8_sig • encodings.uu_codec • encodings.zlib_codec • pickle • tokenize • xml.sax.saxutils

collections Package

imports: _collections • _collections_abc • _weakref • copy • heapq • itertools • keyword • operator • reprlib • sys • warnings

imported by: Ambiance_GUI.py • _pydecimal • ast • asyncio.base_events • asyncio.base_subprocess • asyncio.locks • asyncio.proactor_events • asyncio.queues • asyncio.selector_events • asyncio.sslproto • bleak.backends.bluezdbus.manager • collections.abc • concurrent.futures._base • configparser • contextlib • dis • email.feedparser • functools • importlib.metadata • inspect • multiprocessing.heap • multiprocessing.pool • multiprocessing.queues • pkgutil • platform • pprint • queue • selectors • shlex • shutil • ssl • statistics • string • threading • tokenize • traceback • typing • typing_extensions • urllib.parse

collections.abc SourceModule

imports: _collections_abc • collections

imported by: Ambiance_GUI.py • asyncio.base_events • asyncio.coroutines • bleak • bleak.args.corebluetooth • bleak.backends.bluezdbus.advertisement_monitor • bleak.backends.bluezdbus.client • bleak.backends.bluezdbus.manager • bleak.backends.bluezdbus.scanner • bleak.backends.characteristic • bleak.backends.client • bleak.backends.corebluetooth.CentralManagerDelegate • bleak.backends.corebluetooth.PeripheralDelegate • bleak.backends.corebluetooth.client • bleak.backends.scanner • bleak.backends.service • bleak.backends.winrt.client • configparser • http.client • inspect • logging • selectors • tracemalloc • typing • typing_extensions • winrt.runtime._internals

concurrent Package

imported by: concurrent.futures

concurrent.futures Package

imports: concurrent • concurrent.futures._base • concurrent.futures.process • concurrent.futures.thread

imported by: asyncio.base_events • asyncio.futures • asyncio.tasks • concurrent.futures._base • concurrent.futures.process • concurrent.futures.thread

concurrent.futures._base SourceModule

imports: collections • concurrent.futures • logging • threading • time • types

imported by: concurrent.futures • concurrent.futures.process • concurrent.futures.thread

concurrent.futures.process SourceModule

imports: concurrent.futures • concurrent.futures._base • functools • itertools • multiprocessing • multiprocessing.connection • multiprocessing.queues • os • queue • sys • threading • traceback • weakref

imported by: concurrent.futures

concurrent.futures.thread SourceModule

imports: concurrent.futures • concurrent.futures._base • itertools • os • queue • threading • types • weakref

imported by: concurrent.futures

configparser SourceModule

imports: collections • collections.abc • functools • io • itertools • os • re • sys • warnings

imported by: importlib.metadata

contextlib SourceModule

imports: _collections_abc • abc • collections • functools • sys • types

imported by: _threading_local • ast • asyncio.staggered • bleak.backends.bluezdbus.client • bleak.backends.bluezdbus.manager • bleak.backends.bluezdbus.version • getpass • glob • importlib.metadata • importlib.util • subprocess • typing • typing_extensions • urllib.request • zipfile

contextvars SourceModule

imports: _contextvars

imported by: _pydecimal • asyncio.events • asyncio.futures • asyncio.tasks • asyncio.threads • bleak.backends.winrt.client

copy SourceModule

imports: 'org.python' • copyreg • types • weakref

imported by: _sre • argparse • collections • email.generator • gettext • http.cookiejar • tarfile • weakref

copyreg SourceModule

imported by: Ambiance_GUI.py • _pickle • copy • multiprocessing.reduction • pickle • re

csv SourceModule

imports: _csv • io • re

imported by: importlib.metadata

ctypes Package

imports: _ctypes • ctypes._endian • nt • os • struct • sys • types

imported by: bleak.backends.winrt.client • bleak.backends.winrt.util • ctypes._endian • ctypes.wintypes • multiprocessing.sharedctypes • serial.serialwin32 • serial.tools.list_ports_osx • serial.tools.list_ports_windows • serial.win32

ctypes._endian SourceModule

imports: ctypes • sys

imported by: ctypes

ctypes.wintypes SourceModule

imports: ctypes

imported by: bleak.backends.winrt.util • serial.tools.list_ports_windows • serial.win32

datetime SourceModule

imports: _datetime • _strptime • math • sys • time • warnings

imported by: Ambiance_GUI.py • _strptime • calendar • email.utils • http.cookiejar • winrt._winrt • winrt._winrt_windows_devices_bluetooth • winrt._winrt_windows_devices_bluetooth_advertisement • winrt._winrt_windows_devices_bluetooth_genericattributeprofile • winrt._winrt_windows_devices_enumeration • winrt._winrt_windows_foundation • winrt._winrt_windows_foundation_collections • winrt._winrt_windows_storage_streams • xmlrpc.client

dbus_fast MissingModule

imported by: bleak.backends.bluezdbus.advertisement_monitor • bleak.backends.bluezdbus.client • bleak.backends.bluezdbus.manager • bleak.backends.bluezdbus.scanner

decimal SourceModule

imports: _decimal • _pydecimal

imported by: fractions • statistics • xmlrpc.client

dis SourceModule

imports: argparse • collections • io • opcode • sys • types

imported by: inspect

email Package

imports: email._header_value_parser • email.charset • email.errors • email.header • email.parser

imported by: email._encoded_words • email._header_value_parser • email._parseaddr • email._policybase • email.base64mime • email.charset • email.contentmanager • email.encoders • email.errors • email.feedparser • email.generator • email.header • email.headerregistry • email.iterators • email.message • email.parser • email.policy • email.quoprimime • email.utils • importlib.metadata • urllib.request

email._encoded_words SourceModule

imports: base64 • binascii • email • email.errors • functools • re • string

imported by: email._header_value_parser • email.message

email._header_value_parser SourceModule

imports: email • email._encoded_words • email.errors • email.utils • operator • re • string • sys • urllib

imported by: email • email.headerregistry

email._parseaddr SourceModule

imports: calendar • email • time

imported by: email.utils

email._policybase SourceModule

imports: abc • email • email.charset • email.header • email.utils

imported by: email.feedparser • email.message • email.parser • email.policy

email.base64mime SourceModule

imports: base64 • binascii • email

imported by: email.charset • email.header

email.charset SourceModule

imports: email • email.base64mime • email.encoders • email.errors • email.quoprimime • functools

imported by: email • email._policybase • email.contentmanager • email.header • email.message • email.utils

email.contentmanager SourceModule

imports: binascii • email • email.charset • email.errors • email.message • email.quoprimime

imported by: email.policy

email.encoders SourceModule

imports: base64 • email • quopri

imported by: email.charset

email.errors SourceModule

imports: email

imported by: email • email._encoded_words • email._header_value_parser • email.charset • email.contentmanager • email.feedparser • email.header • email.headerregistry • email.message

email.feedparser SourceModule

imports: collections • email • email._policybase • email.errors • email.message • io • re

imported by: email.parser

email.generator SourceModule

imports: copy • email • email.utils • io • random • re • sys • time

imported by: email.message

email.header SourceModule

imports: binascii • email • email.base64mime • email.charset • email.errors • email.quoprimime • re

imported by: email • email._policybase

email.headerregistry SourceModule

imports: email • email._header_value_parser • email.errors • email.utils • types

imported by: email.policy

email.iterators SourceModule

imports: email • io • sys

imported by: email.message

email.message SourceModule

imports: email • email._encoded_words • email._policybase • email.charset • email.errors • email.generator • email.iterators • email.policy • email.utils • io • quopri • re • uu

imported by: email.contentmanager • email.feedparser • email.policy • http.client

email.parser SourceModule

imports: email • email._policybase • email.feedparser • io

imported by: email • http.client

email.policy SourceModule

imports: email • email._policybase • email.contentmanager • email.headerregistry • email.message • email.utils • re • sys

imported by: email.message

email.quoprimime SourceModule

imports: email • re • string

imported by: email.charset • email.contentmanager • email.header

email.utils SourceModule

imports: datetime • email • email._parseaddr • email.charset • os • random • re • socket • time • urllib.parse

imported by: email._header_value_parser • email._policybase • email.generator • email.headerregistry • email.message • email.policy • urllib.request

encodings Package

imports: _winapi • codecs • encodings • encodings.aliases • encodings.ascii • encodings.base64_codec • encodings.big5 • encodings.big5hkscs • encodings.bz2_codec • encodings.charmap • encodings.cp037 • encodings.cp1006 • encodings.cp1026 • encodings.cp1125 • encodings.cp1140 • encodings.cp1250 • encodings.cp1251 • encodings.cp1252 • encodings.cp1253 • encodings.cp1254 • encodings.cp1255 • encodings.cp1256 • encodings.cp1257 • encodings.cp1258 • encodings.cp273 • encodings.cp424 • encodings.cp437 • encodings.cp500 • encodings.cp720 • encodings.cp737 • encodings.cp775 • encodings.cp850 • encodings.cp852 • encodings.cp855 • encodings.cp856 • encodings.cp857 • encodings.cp858 • encodings.cp860 • encodings.cp861 • encodings.cp862 • encodings.cp863 • encodings.cp864 • encodings.cp865 • encodings.cp866 • encodings.cp869 • encodings.cp874 • encodings.cp875 • encodings.cp932 • encodings.cp949 • encodings.cp950 • encodings.euc_jis_2004 • encodings.euc_jisx0213 • encodings.euc_jp • encodings.euc_kr • encodings.gb18030 • encodings.gb2312 • encodings.gbk • encodings.hex_codec • encodings.hp_roman8 • encodings.hz • encodings.idna • encodings.iso2022_jp • encodings.iso2022_jp_1 • encodings.iso2022_jp_2 • encodings.iso2022_jp_2004 • encodings.iso2022_jp_3 • encodings.iso2022_jp_ext • encodings.iso2022_kr • encodings.iso8859_1 • encodings.iso8859_10 • encodings.iso8859_11 • encodings.iso8859_13 • encodings.iso8859_14 • encodings.iso8859_15 • encodings.iso8859_16 • encodings.iso8859_2 • encodings.iso8859_3 • encodings.iso8859_4 • encodings.iso8859_5 • encodings.iso8859_6 • encodings.iso8859_7 • encodings.iso8859_8 • encodings.iso8859_9 • encodings.johab • encodings.koi8_r • encodings.koi8_t • encodings.koi8_u • encodings.kz1048 • encodings.latin_1 • encodings.mac_arabic • encodings.mac_croatian • encodings.mac_cyrillic • encodings.mac_farsi • encodings.mac_greek • encodings.mac_iceland • encodings.mac_latin2 • encodings.mac_roman • encodings.mac_romanian • encodings.mac_turkish • encodings.mbcs • encodings.oem • encodings.palmos • encodings.ptcp154 • encodings.punycode • encodings.quopri_codec • encodings.raw_unicode_escape • encodings.rot_13 • encodings.shift_jis • encodings.shift_jis_2004 • encodings.shift_jisx0213 • encodings.tis_620 • encodings.undefined • encodings.unicode_escape • encodings.utf_16 • encodings.utf_16_be • encodings.utf_16_le • encodings.utf_32 • encodings.utf_32_be • encodings.utf_32_le • encodings.utf_7 • encodings.utf_8 • encodings.utf_8_sig • encodings.uu_codec • encodings.zlib_codec • sys

imported by: Ambiance_GUI.py • codecs • encodings • encodings.aliases • encodings.ascii • encodings.base64_codec • encodings.big5 • encodings.big5hkscs • encodings.bz2_codec • encodings.charmap • encodings.cp037 • encodings.cp1006 • encodings.cp1026 • encodings.cp1125 • encodings.cp1140 • encodings.cp1250 • encodings.cp1251 • encodings.cp1252 • encodings.cp1253 • encodings.cp1254 • encodings.cp1255 • encodings.cp1256 • encodings.cp1257 • encodings.cp1258 • encodings.cp273 • encodings.cp424 • encodings.cp437 • encodings.cp500 • encodings.cp720 • encodings.cp737 • encodings.cp775 • encodings.cp850 • encodings.cp852 • encodings.cp855 • encodings.cp856 • encodings.cp857 • encodings.cp858 • encodings.cp860 • encodings.cp861 • encodings.cp862 • encodings.cp863 • encodings.cp864 • encodings.cp865 • encodings.cp866 • encodings.cp869 • encodings.cp874 • encodings.cp875 • encodings.cp932 • encodings.cp949 • encodings.cp950 • encodings.euc_jis_2004 • encodings.euc_jisx0213 • encodings.euc_jp • encodings.euc_kr • encodings.gb18030 • encodings.gb2312 • encodings.gbk • encodings.hex_codec • encodings.hp_roman8 • encodings.hz • encodings.idna • encodings.iso2022_jp • encodings.iso2022_jp_1 • encodings.iso2022_jp_2 • encodings.iso2022_jp_2004 • encodings.iso2022_jp_3 • encodings.iso2022_jp_ext • encodings.iso2022_kr • encodings.iso8859_1 • encodings.iso8859_10 • encodings.iso8859_11 • encodings.iso8859_13 • encodings.iso8859_14 • encodings.iso8859_15 • encodings.iso8859_16 • encodings.iso8859_2 • encodings.iso8859_3 • encodings.iso8859_4 • encodings.iso8859_5 • encodings.iso8859_6 • encodings.iso8859_7 • encodings.iso8859_8 • encodings.iso8859_9 • encodings.johab • encodings.koi8_r • encodings.koi8_t • encodings.koi8_u • encodings.kz1048 • encodings.latin_1 • encodings.mac_arabic • encodings.mac_croatian • encodings.mac_cyrillic • encodings.mac_farsi • encodings.mac_greek • encodings.mac_iceland • encodings.mac_latin2 • encodings.mac_roman • encodings.mac_romanian • encodings.mac_turkish • encodings.mbcs • encodings.oem • encodings.palmos • encodings.ptcp154 • encodings.punycode • encodings.quopri_codec • encodings.raw_unicode_escape • encodings.rot_13 • encodings.shift_jis • encodings.shift_jis_2004 • encodings.shift_jisx0213 • encodings.tis_620 • encodings.undefined • encodings.unicode_escape • encodings.utf_16 • encodings.utf_16_be • encodings.utf_16_le • encodings.utf_32 • encodings.utf_32_be • encodings.utf_32_le • encodings.utf_7 • encodings.utf_8 • encodings.utf_8_sig • encodings.uu_codec • encodings.zlib_codec • locale

encodings.aliases SourceModule

imports: encodings

imported by: Ambiance_GUI.py • encodings • locale

encodings.ascii SourceModule

imports: codecs • encodings

imported by: Ambiance_GUI.py • encodings

encodings.base64_codec SourceModule

imports: base64 • codecs • encodings

imported by: Ambiance_GUI.py • encodings

encodings.big5 SourceModule

imports: _codecs_tw • _multibytecodec • codecs • encodings

imported by: Ambiance_GUI.py • encodings

encodings.big5hkscs SourceModule

imports: _codecs_hk • _multibytecodec • codecs • encodings

imported by: Ambiance_GUI.py • encodings

encodings.bz2_codec SourceModule

imports: bz2 • codecs • encodings

imported by: Ambiance_GUI.py • encodings

encodings.charmap SourceModule

imports: codecs • encodings

imported by: Ambiance_GUI.py • encodings

encodings.cp037 SourceModule

imports: codecs • encodings

imported by: Ambiance_GUI.py • encodings

encodings.cp1006 SourceModule

imports: codecs • encodings

imported by: Ambiance_GUI.py • encodings

encodings.cp1026 SourceModule

imports: codecs • encodings

imported by: Ambiance_GUI.py • encodings

encodings.cp1125 SourceModule

imports: codecs • encodings

imported by: Ambiance_GUI.py • encodings

encodings.cp1140 SourceModule

imports: codecs • encodings

imported by: Ambiance_GUI.py • encodings

encodings.cp1250 SourceModule

imports: codecs • encodings

imported by: Ambiance_GUI.py • encodings

encodings.cp1251 SourceModule

imports: codecs • encodings

imported by: Ambiance_GUI.py • encodings

encodings.cp1252 SourceModule

imports: codecs • encodings

imported by: Ambiance_GUI.py • encodings

encodings.cp1253 SourceModule

imports: codecs • encodings

imported by: Ambiance_GUI.py • encodings

encodings.cp1254 SourceModule

imports: codecs • encodings

imported by: Ambiance_GUI.py • encodings

encodings.cp1255 SourceModule

imports: codecs • encodings

imported by: Ambiance_GUI.py • encodings

encodings.cp1256 SourceModule

imports: codecs • encodings

imported by: Ambiance_GUI.py • encodings

encodings.cp1257 SourceModule

imports: codecs • encodings

imported by: Ambiance_GUI.py • encodings

encodings.cp1258 SourceModule

imports: codecs • encodings

imported by: Ambiance_GUI.py • encodings

encodings.cp273 SourceModule

imports: codecs • encodings

imported by: Ambiance_GUI.py • encodings

encodings.cp424 SourceModule

imports: codecs • encodings

imported by: Ambiance_GUI.py • encodings

encodings.cp437 SourceModule

imports: codecs • encodings

imported by: Ambiance_GUI.py • encodings

encodings.cp500 SourceModule

imports: codecs • encodings

imported by: Ambiance_GUI.py • encodings

encodings.cp720 SourceModule

imports: codecs • encodings

imported by: Ambiance_GUI.py • encodings

encodings.cp737 SourceModule

imports: codecs • encodings

imported by: Ambiance_GUI.py • encodings

encodings.cp775 SourceModule

imports: codecs • encodings

imported by: Ambiance_GUI.py • encodings

encodings.cp850 SourceModule

imports: codecs • encodings

imported by: Ambiance_GUI.py • encodings

encodings.cp852 SourceModule

imports: codecs • encodings

imported by: Ambiance_GUI.py • encodings

encodings.cp855 SourceModule

imports: codecs • encodings

imported by: Ambiance_GUI.py • encodings

encodings.cp856 SourceModule

imports: codecs • encodings

imported by: Ambiance_GUI.py • encodings

encodings.cp857 SourceModule

imports: codecs • encodings

imported by: Ambiance_GUI.py • encodings

encodings.cp858 SourceModule

imports: codecs • encodings

imported by: Ambiance_GUI.py • encodings

encodings.cp860 SourceModule

imports: codecs • encodings

imported by: Ambiance_GUI.py • encodings

encodings.cp861 SourceModule

imports: codecs • encodings

imported by: Ambiance_GUI.py • encodings

encodings.cp862 SourceModule

imports: codecs • encodings

imported by: Ambiance_GUI.py • encodings

encodings.cp863 SourceModule

imports: codecs • encodings

imported by: Ambiance_GUI.py • encodings

encodings.cp864 SourceModule

imports: codecs • encodings

imported by: Ambiance_GUI.py • encodings

encodings.cp865 SourceModule

imports: codecs • encodings

imported by: Ambiance_GUI.py • encodings

encodings.cp866 SourceModule

imports: codecs • encodings

imported by: Ambiance_GUI.py • encodings

encodings.cp869 SourceModule

imports: codecs • encodings

imported by: Ambiance_GUI.py • encodings

encodings.cp874 SourceModule

imports: codecs • encodings

imported by: Ambiance_GUI.py • encodings

encodings.cp875 SourceModule

imports: codecs • encodings

imported by: Ambiance_GUI.py • encodings

encodings.cp932 SourceModule

imports: _codecs_jp • _multibytecodec • codecs • encodings

imported by: Ambiance_GUI.py • encodings

encodings.cp949 SourceModule

imports: _codecs_kr • _multibytecodec • codecs • encodings

imported by: Ambiance_GUI.py • encodings

encodings.cp950 SourceModule

imports: _codecs_tw • _multibytecodec • codecs • encodings

imported by: Ambiance_GUI.py • encodings

encodings.euc_jis_2004 SourceModule

imports: _codecs_jp • _multibytecodec • codecs • encodings

imported by: Ambiance_GUI.py • encodings

encodings.euc_jisx0213 SourceModule

imports: _codecs_jp • _multibytecodec • codecs • encodings

imported by: Ambiance_GUI.py • encodings

encodings.euc_jp SourceModule

imports: _codecs_jp • _multibytecodec • codecs • encodings

imported by: Ambiance_GUI.py • encodings

encodings.euc_kr SourceModule

imports: _codecs_kr • _multibytecodec • codecs • encodings

imported by: Ambiance_GUI.py • encodings

encodings.gb18030 SourceModule

imports: _codecs_cn • _multibytecodec • codecs • encodings

imported by: Ambiance_GUI.py • encodings

encodings.gb2312 SourceModule

imports: _codecs_cn • _multibytecodec • codecs • encodings

imported by: Ambiance_GUI.py • encodings

encodings.gbk SourceModule

imports: _codecs_cn • _multibytecodec • codecs • encodings

imported by: Ambiance_GUI.py • encodings

encodings.hex_codec SourceModule

imports: binascii • codecs • encodings

imported by: Ambiance_GUI.py • encodings

encodings.hp_roman8 SourceModule

imports: codecs • encodings

imported by: Ambiance_GUI.py • encodings

encodings.hz SourceModule

imports: _codecs_cn • _multibytecodec • codecs • encodings

imported by: Ambiance_GUI.py • encodings

encodings.idna SourceModule

imports: codecs • encodings • re • stringprep • unicodedata

imported by: Ambiance_GUI.py • encodings

encodings.iso2022_jp SourceModule

imports: _codecs_iso2022 • _multibytecodec • codecs • encodings

imported by: Ambiance_GUI.py • encodings

encodings.iso2022_jp_1 SourceModule

imports: _codecs_iso2022 • _multibytecodec • codecs • encodings

imported by: Ambiance_GUI.py • encodings

encodings.iso2022_jp_2 SourceModule

imports: _codecs_iso2022 • _multibytecodec • codecs • encodings

imported by: Ambiance_GUI.py • encodings

encodings.iso2022_jp_2004 SourceModule

imports: _codecs_iso2022 • _multibytecodec • codecs • encodings

imported by: Ambiance_GUI.py • encodings

encodings.iso2022_jp_3 SourceModule

imports: _codecs_iso2022 • _multibytecodec • codecs • encodings

imported by: Ambiance_GUI.py • encodings

encodings.iso2022_jp_ext SourceModule

imports: _codecs_iso2022 • _multibytecodec • codecs • encodings

imported by: Ambiance_GUI.py • encodings

encodings.iso2022_kr SourceModule

imports: _codecs_iso2022 • _multibytecodec • codecs • encodings

imported by: Ambiance_GUI.py • encodings

encodings.iso8859_1 SourceModule

imports: codecs • encodings

imported by: Ambiance_GUI.py • encodings

encodings.iso8859_10 SourceModule

imports: codecs • encodings

imported by: Ambiance_GUI.py • encodings

encodings.iso8859_11 SourceModule

imports: codecs • encodings

imported by: Ambiance_GUI.py • encodings

encodings.iso8859_13 SourceModule

imports: codecs • encodings

imported by: Ambiance_GUI.py • encodings

encodings.iso8859_14 SourceModule

imports: codecs • encodings

imported by: Ambiance_GUI.py • encodings

encodings.iso8859_15 SourceModule

imports: codecs • encodings

imported by: Ambiance_GUI.py • encodings

encodings.iso8859_16 SourceModule

imports: codecs • encodings

imported by: Ambiance_GUI.py • encodings

encodings.iso8859_2 SourceModule

imports: codecs • encodings

imported by: Ambiance_GUI.py • encodings

encodings.iso8859_3 SourceModule

imports: codecs • encodings

imported by: Ambiance_GUI.py • encodings

encodings.iso8859_4 SourceModule

imports: codecs • encodings

imported by: Ambiance_GUI.py • encodings

encodings.iso8859_5 SourceModule

imports: codecs • encodings

imported by: Ambiance_GUI.py • encodings

encodings.iso8859_6 SourceModule

imports: codecs • encodings

imported by: Ambiance_GUI.py • encodings

encodings.iso8859_7 SourceModule

imports: codecs • encodings

imported by: Ambiance_GUI.py • encodings

encodings.iso8859_8 SourceModule

imports: codecs • encodings

imported by: Ambiance_GUI.py • encodings

encodings.iso8859_9 SourceModule

imports: codecs • encodings

imported by: Ambiance_GUI.py • encodings

encodings.johab SourceModule

imports: _codecs_kr • _multibytecodec • codecs • encodings

imported by: Ambiance_GUI.py • encodings

encodings.koi8_r SourceModule

imports: codecs • encodings

imported by: Ambiance_GUI.py • encodings

encodings.koi8_t SourceModule

imports: codecs • encodings

imported by: Ambiance_GUI.py • encodings

encodings.koi8_u SourceModule

imports: codecs • encodings

imported by: Ambiance_GUI.py • encodings

encodings.kz1048 SourceModule

imports: codecs • encodings

imported by: Ambiance_GUI.py • encodings

encodings.latin_1 SourceModule

imports: codecs • encodings

imported by: Ambiance_GUI.py • encodings

encodings.mac_arabic SourceModule

imports: codecs • encodings

imported by: Ambiance_GUI.py • encodings

encodings.mac_croatian SourceModule

imports: codecs • encodings

imported by: Ambiance_GUI.py • encodings

encodings.mac_cyrillic SourceModule

imports: codecs • encodings

imported by: Ambiance_GUI.py • encodings

encodings.mac_farsi SourceModule

imports: codecs • encodings

imported by: Ambiance_GUI.py • encodings

encodings.mac_greek SourceModule

imports: codecs • encodings

imported by: Ambiance_GUI.py • encodings

encodings.mac_iceland SourceModule

imports: codecs • encodings

imported by: Ambiance_GUI.py • encodings

encodings.mac_latin2 SourceModule

imports: codecs • encodings

imported by: Ambiance_GUI.py • encodings

encodings.mac_roman SourceModule

imports: codecs • encodings

imported by: Ambiance_GUI.py • encodings

encodings.mac_romanian SourceModule

imports: codecs • encodings

imported by: Ambiance_GUI.py • encodings

encodings.mac_turkish SourceModule

imports: codecs • encodings

imported by: Ambiance_GUI.py • encodings

encodings.mbcs SourceModule

imports: codecs • encodings

imported by: Ambiance_GUI.py • encodings

encodings.oem SourceModule

imports: codecs • encodings

imported by: Ambiance_GUI.py • encodings

encodings.palmos SourceModule

imports: codecs • encodings

imported by: Ambiance_GUI.py • encodings

encodings.ptcp154 SourceModule

imports: codecs • encodings

imported by: Ambiance_GUI.py • encodings

encodings.punycode SourceModule

imports: codecs • encodings

imported by: Ambiance_GUI.py • encodings

encodings.quopri_codec SourceModule

imports: codecs • encodings • io • quopri

imported by: Ambiance_GUI.py • encodings

encodings.raw_unicode_escape SourceModule

imports: codecs • encodings

imported by: Ambiance_GUI.py • encodings

encodings.rot_13 SourceModule

imports: codecs • encodings • sys

imported by: Ambiance_GUI.py • encodings

encodings.shift_jis SourceModule

imports: _codecs_jp • _multibytecodec • codecs • encodings

imported by: Ambiance_GUI.py • encodings

encodings.shift_jis_2004 SourceModule

imports: _codecs_jp • _multibytecodec • codecs • encodings

imported by: Ambiance_GUI.py • encodings

encodings.shift_jisx0213 SourceModule

imports: _codecs_jp • _multibytecodec • codecs • encodings

imported by: Ambiance_GUI.py • encodings

encodings.tis_620 SourceModule

imports: codecs • encodings

imported by: Ambiance_GUI.py • encodings

encodings.undefined SourceModule

imports: codecs • encodings

imported by: Ambiance_GUI.py • encodings

encodings.unicode_escape SourceModule

imports: codecs • encodings

imported by: Ambiance_GUI.py • encodings

encodings.utf_16 SourceModule

imports: codecs • encodings • sys

imported by: Ambiance_GUI.py • encodings

encodings.utf_16_be SourceModule

imports: codecs • encodings

imported by: Ambiance_GUI.py • encodings

encodings.utf_16_le SourceModule

imports: codecs • encodings

imported by: Ambiance_GUI.py • encodings

encodings.utf_32 SourceModule

imports: codecs • encodings • sys

imported by: Ambiance_GUI.py • encodings

encodings.utf_32_be SourceModule

imports: codecs • encodings

imported by: Ambiance_GUI.py • encodings

encodings.utf_32_le SourceModule

imports: codecs • encodings

imported by: Ambiance_GUI.py • encodings

encodings.utf_7 SourceModule

imports: codecs • encodings

imported by: Ambiance_GUI.py • encodings

encodings.utf_8 SourceModule

imports: codecs • encodings

imported by: Ambiance_GUI.py • encodings

encodings.utf_8_sig SourceModule

imports: codecs • encodings

imported by: Ambiance_GUI.py • encodings

encodings.uu_codec SourceModule

imports: binascii • codecs • encodings • io

imported by: Ambiance_GUI.py • encodings

encodings.zlib_codec SourceModule

imports: codecs • encodings • zlib

imported by: Ambiance_GUI.py • encodings

enum SourceModule

imports: sys • types • warnings

imported by: Ambiance_GUI.py • ast • async_timeout • asyncio.constants • bleak.assigned_numbers • bleak.backends.characteristic • bleak.backends.p4android.defs • bleak.backends.winrt.util • http • inspect • py_compile • re • signal • socket • ssl • tkinter • typing_extensions • uuid • winrt.runtime • winrt.windows.devices.bluetooth • winrt.windows.devices.bluetooth.advertisement • winrt.windows.devices.bluetooth.genericattributeprofile • winrt.windows.devices.enumeration • winrt.windows.foundation • winrt.windows.foundation.collections • winrt.windows.storage.streams

errno (builtin module)

imported by: asyncio.selector_events • asyncio.unix_events • asyncio.windows_events • gettext • gzip • http.client • multiprocessing.forkserver • multiprocessing.queues • multiprocessing.shared_memory • pathlib • serial.serialposix • shutil • socket • ssl • subprocess • tempfile • xmlrpc.client

fcntl MissingModule

imported by: serial.serialposix

fnmatch SourceModule

imports: functools • itertools • os • posixpath • re

imported by: glob • pathlib • shutil • tkinter.filedialog • tracemalloc • urllib.request

fractions SourceModule

imports: decimal • math • numbers • operator • re • sys

imported by: statistics

ftplib SourceModule

imports: netrc • re • socket • ssl • sys • warnings

imported by: urllib.request

functools SourceModule

imports: _functools • _thread • abc • collections • reprlib • types • typing • weakref

imported by: Ambiance_GUI.py • asyncio.base_events • asyncio.coroutines • asyncio.format_helpers • asyncio.selector_events • asyncio.tasks • asyncio.threads • bleak • bleak.backends.bluezdbus.manager • concurrent.futures.process • configparser • contextlib • email._encoded_words • email.charset • fnmatch • importlib.metadata • importlib.util • inspect • linecache • locale • multiprocessing.reduction • multiprocessing.shared_memory • operator • pathlib • pickle • pkgutil • platform • re • tempfile • threading • tracemalloc • types • typing • typing_extensions

gc (builtin module)

imports: time

imported by: _posixsubprocess • weakref

genericpath SourceModule

imports: os • stat

imported by: Ambiance_GUI.py • ntpath • posixpath

getopt SourceModule

imports: gettext • os • sys

imported by: base64 • mimetypes • quopri

getpass SourceModule

imports: contextlib • io • msvcrt • os • pwd • sys • termios • warnings

imported by: urllib.request

gettext SourceModule

imports: builtins • copy • errno • locale • os • re • struct • sys • warnings

imported by: argparse • getopt • optparse

glob SourceModule

imports: contextlib • fnmatch • os • re • sys

imported by: serial.tools.list_ports_common • serial.tools.list_ports_linux • serial.tools.list_ports_posix

grp MissingModule

imported by: pathlib • shutil • subprocess • tarfile

gzip SourceModule

imports: _compression • argparse • builtins • errno • io • os • struct • sys • time • warnings • zlib

imported by: tarfile • xmlrpc.client

hashlib SourceModule

imports: _blake2 • _hashlib • _md5 • _sha1 • _sha256 • _sha3 • _sha512 • logging

imported by: hmac • random • urllib.request • uuid

heapq SourceModule

imports: _heapq

imported by: Ambiance_GUI.py • asyncio.base_events • asyncio.queues • collections • queue

hmac SourceModule

imports: _hashlib • _operator • hashlib • warnings

imported by: multiprocessing.connection • secrets

http Package

imports: enum

imported by: http.client • http.cookiejar

http.client SourceModule

imports: collections.abc • email.message • email.parser • errno • http • io • re • socket • ssl • urllib.parse • warnings

imported by: http.cookiejar • urllib.request • xmlrpc.client

http.cookiejar SourceModule

imports: calendar • copy • datetime • http • http.client • io • logging • os • re • threading • time • traceback • urllib.parse • urllib.request • warnings

imported by: urllib.request

importlib Package

imports: _frozen_importlib • _frozen_importlib_external • _imp • importlib • importlib._bootstrap • importlib._bootstrap_external • importlib.machinery • sys • types • warnings

imported by: importlib • importlib._bootstrap • importlib._bootstrap_external • importlib.abc • importlib.machinery • importlib.metadata • importlib.util • inspect • pkgutil • serial

importlib._bootstrap SourceModule

imports: _frozen_importlib_external • importlib

imported by: importlib • importlib.abc • importlib.machinery • importlib.util

importlib._bootstrap_external SourceModule

imports: _imp • _io • _warnings • importlib • importlib.metadata • marshal • nt • posix • sys • tokenize • winreg

imported by: importlib • importlib.abc • importlib.machinery • importlib.util • py_compile

importlib.abc SourceModule

imports: _frozen_importlib • _frozen_importlib_external • abc • importlib • importlib._bootstrap • importlib._bootstrap_external • importlib.machinery • typing • warnings

imported by: importlib.metadata • importlib.util • zipimport

importlib.machinery SourceModule

imports: _imp • importlib • importlib._bootstrap • importlib._bootstrap_external

imported by: importlib • importlib.abc • inspect • pkgutil • py_compile • runpy

importlib.metadata SourceModule

imports: abc • collections • configparser • contextlib • csv • email • functools • importlib • importlib.abc • io • itertools • operator • os • pathlib • pep517 • posixpath • re • sys • zipfile

imported by: importlib._bootstrap_external

importlib.util SourceModule

imports: _imp • contextlib • functools • importlib • importlib._bootstrap • importlib._bootstrap_external • importlib.abc • sys • types • warnings

imported by: pkgutil • py_compile • runpy • zipfile

inspect SourceModule

imports: abc • argparse • ast • builtins • collections • collections.abc • dis • enum • functools • importlib • importlib.machinery • itertools • linecache • operator • os • re • sys • token • tokenize • types • warnings

imported by: ast • asyncio.coroutines • asyncio.format_helpers • asyncio.tasks • bleak • bleak.backends.scanner • pkgutil • pyi_rth_inspect.py • typing_extensions

io SourceModule

imports: _io • abc

imported by: Ambiance_GUI.py • _compression • asyncio.proactor_events • asyncio.unix_events • bz2 • configparser • csv • dis • email.feedparser • email.generator • email.iterators • email.message • email.parser • encodings.quopri_codec • encodings.uu_codec • getpass • gzip • http.client • http.cookiejar • importlib.metadata • logging • lzma • multiprocessing.connection • multiprocessing.popen_forkserver • multiprocessing.popen_spawn_posix • multiprocessing.reduction • os • pathlib • pickle • pprint • quopri • runpy • serial.serialutil • shlex • socket • subprocess • tarfile • tempfile • tokenize • typing_extensions • urllib.request • uuid • xml.sax • xml.sax.saxutils • xmlrpc.client • zipfile • zipimport

itertools (builtin module)

imported by: _pydecimal • asyncio.base_events • asyncio.tasks • asyncio.unix_events • asyncio.windows_utils • bleak.backends.corebluetooth.PeripheralDelegate • calendar • collections • concurrent.futures.process • concurrent.futures.thread • configparser • fnmatch • importlib.metadata • inspect • multiprocessing.connection • multiprocessing.pool • multiprocessing.process • multiprocessing.util • pickle • platform • random • reprlib • statistics • threading • tokenize • traceback • weakref • zipfile

java MissingModule

imported by: platform

jnius MissingModule

imported by: bleak.backends.p4android.client • bleak.backends.p4android.defs • bleak.backends.p4android.scanner • bleak.backends.p4android.utils

keyword SourceModule

imported by: Ambiance_GUI.py • collections • typing_extensions

libdispatch MissingModule

imported by: bleak.backends.corebluetooth.CentralManagerDelegate

linecache SourceModule

imports: functools • os • sys • tokenize

imported by: Ambiance_GUI.py • asyncio.base_tasks • inspect • traceback • tracemalloc • warnings

locale SourceModule

imports: _bootlocale • _collections_abc • _locale • builtins • encodings • encodings.aliases • functools • os • re • sys • warnings

imported by: Ambiance_GUI.py • _bootlocale • _pydecimal • _strptime • calendar • gettext • tkinter.filedialog

logging Package

imports: atexit • collections.abc • io • os • pickle • re • string • sys • threading • time • traceback • warnings • weakref

imported by: asyncio.futures • asyncio.log • bleak • bleak.backends.bluezdbus.advertisement_monitor • bleak.backends.bluezdbus.client • bleak.backends.bluezdbus.manager • bleak.backends.bluezdbus.scanner • bleak.backends.bluezdbus.version • bleak.backends.corebluetooth.CentralManagerDelegate • bleak.backends.corebluetooth.PeripheralDelegate • bleak.backends.corebluetooth.client • bleak.backends.corebluetooth.scanner • bleak.backends.p4android.client • bleak.backends.p4android.scanner • bleak.backends.p4android.utils • bleak.backends.service • bleak.backends.winrt.client • bleak.backends.winrt.scanner • concurrent.futures._base • hashlib • http.cookiejar • multiprocessing.util

lzma SourceModule

imports: _compression • _lzma • builtins • io • os

imported by: shutil • tarfile • zipfile

marshal (builtin module)

imported by: importlib._bootstrap_external • pkgutil • zipimport

math (builtin module)

imported by: _pydecimal • asyncio.windows_events • datetime • fractions • random • selectors • statistics

mimetypes SourceModule

imports: getopt • os • posixpath • sys • urllib.parse • winreg

imported by: urllib.request

mmap (builtin module)

imported by: multiprocessing.heap • multiprocessing.shared_memory

msvcrt (builtin module)

imported by: asyncio.windows_events • asyncio.windows_utils • getpass • multiprocessing.popen_spawn_win32 • multiprocessing.spawn • subprocess

multiprocessing Package

imports: multiprocessing • multiprocessing.AuthenticationError • multiprocessing.BufferTooShort • multiprocessing.TimeoutError • multiprocessing.connection • multiprocessing.context • multiprocessing.forkserver • multiprocessing.get_context • multiprocessing.get_start_method • multiprocessing.pool • multiprocessing.process • multiprocessing.reduction • multiprocessing.resource_sharer • multiprocessing.resource_tracker • multiprocessing.set_start_method • multiprocessing.shared_memory • multiprocessing.spawn • multiprocessing.util • sys

imported by: concurrent.futures.process • multiprocessing • multiprocessing.connection • multiprocessing.context • multiprocessing.dummy • multiprocessing.forkserver • multiprocessing.heap • multiprocessing.managers • multiprocessing.pool • multiprocessing.popen_fork • multiprocessing.popen_forkserver • multiprocessing.popen_spawn_posix • multiprocessing.popen_spawn_win32 • multiprocessing.process • multiprocessing.queues • multiprocessing.reduction • multiprocessing.resource_sharer • multiprocessing.resource_tracker • multiprocessing.shared_memory • multiprocessing.sharedctypes • multiprocessing.spawn • multiprocessing.synchronize • multiprocessing.util • pyi_rth_multiprocessing.py

multiprocessing.AuthenticationError MissingModule

imported by: multiprocessing • multiprocessing.connection

multiprocessing.BufferTooShort MissingModule

imported by: multiprocessing • multiprocessing.connection

multiprocessing.TimeoutError MissingModule

imported by: multiprocessing • multiprocessing.pool

multiprocessing.connection SourceModule

imports: _multiprocessing • _winapi • hmac • io • itertools • multiprocessing • multiprocessing.AuthenticationError • multiprocessing.BufferTooShort • multiprocessing.context • multiprocessing.resource_sharer • multiprocessing.util • os • selectors • socket • struct • sys • tempfile • time • xmlrpc.client

imported by: concurrent.futures.process • multiprocessing • multiprocessing.context • multiprocessing.forkserver • multiprocessing.managers • multiprocessing.pool • multiprocessing.popen_fork • multiprocessing.popen_forkserver • multiprocessing.process • multiprocessing.queues • multiprocessing.resource_sharer

multiprocessing.context SourceModule

imports: multiprocessing • multiprocessing.connection • multiprocessing.forkserver • multiprocessing.managers • multiprocessing.pool • multiprocessing.popen_fork • multiprocessing.popen_forkserver • multiprocessing.popen_spawn_posix • multiprocessing.popen_spawn_win32 • multiprocessing.process • multiprocessing.queues • multiprocessing.reduction • multiprocessing.sharedctypes • multiprocessing.spawn • multiprocessing.synchronize • multiprocessing.util • os • sys • threading

imported by: multiprocessing • multiprocessing.connection • multiprocessing.forkserver • multiprocessing.heap • multiprocessing.managers • multiprocessing.popen_forkserver • multiprocessing.popen_spawn_posix • multiprocessing.popen_spawn_win32 • multiprocessing.process • multiprocessing.queues • multiprocessing.reduction • multiprocessing.resource_sharer • multiprocessing.sharedctypes • multiprocessing.spawn • multiprocessing.synchronize

multiprocessing.dummy Package

imports: array • multiprocessing • multiprocessing.dummy.connection • multiprocessing.pool • queue • sys • threading • weakref

imported by: multiprocessing.dummy.connection • multiprocessing.pool

multiprocessing.dummy.connection SourceModule

imports: multiprocessing.dummy • queue

imported by: multiprocessing.dummy

multiprocessing.forkserver SourceModule

imports: errno • multiprocessing • multiprocessing.connection • multiprocessing.context • multiprocessing.process • multiprocessing.resource_tracker • multiprocessing.spawn • multiprocessing.util • os • selectors • signal • socket • struct • sys • threading • warnings

imported by: multiprocessing • multiprocessing.context • multiprocessing.popen_forkserver • multiprocessing.util

multiprocessing.get_context MissingModule

imported by: multiprocessing • multiprocessing.managers • multiprocessing.pool • multiprocessing.sharedctypes

multiprocessing.get_start_method MissingModule

imported by: multiprocessing • multiprocessing.spawn

multiprocessing.heap SourceModule

imports: _winapi • bisect • collections • mmap • multiprocessing • multiprocessing.context • multiprocessing.util • os • sys • tempfile • threading

imported by: multiprocessing.sharedctypes • multiprocessing.synchronize

multiprocessing.managers SourceModule

imports: array • multiprocessing • multiprocessing.connection • multiprocessing.context • multiprocessing.get_context • multiprocessing.pool • multiprocessing.process • multiprocessing.resource_tracker • multiprocessing.shared_memory • multiprocessing.util • os • queue • signal • sys • threading • time • traceback • types

imported by: multiprocessing.context

multiprocessing.pool SourceModule

imports: collections • itertools • multiprocessing • multiprocessing.TimeoutError • multiprocessing.connection • multiprocessing.dummy • multiprocessing.get_context • multiprocessing.util • os • queue • threading • time • traceback • types • warnings

imported by: multiprocessing • multiprocessing.context • multiprocessing.dummy • multiprocessing.managers

multiprocessing.popen_fork SourceModule

imports: multiprocessing • multiprocessing.connection • multiprocessing.util • os • signal

imported by: multiprocessing.context • multiprocessing.popen_forkserver • multiprocessing.popen_spawn_posix

multiprocessing.popen_forkserver SourceModule

imports: io • multiprocessing • multiprocessing.connection • multiprocessing.context • multiprocessing.forkserver • multiprocessing.popen_fork • multiprocessing.spawn • multiprocessing.util • os

imported by: multiprocessing.context

multiprocessing.popen_spawn_posix SourceModule

imports: io • multiprocessing • multiprocessing.context • multiprocessing.popen_fork • multiprocessing.resource_tracker • multiprocessing.spawn • multiprocessing.util • os

imported by: multiprocessing.context

multiprocessing.popen_spawn_win32 SourceModule

imports: _winapi • msvcrt • multiprocessing • multiprocessing.context • multiprocessing.spawn • multiprocessing.util • os • signal • sys

imported by: multiprocessing.context

multiprocessing.process SourceModule

imports: _weakrefset • itertools • multiprocessing • multiprocessing.connection • multiprocessing.context • multiprocessing.util • os • signal • sys • threading • traceback

imported by: multiprocessing • multiprocessing.context • multiprocessing.forkserver • multiprocessing.managers • multiprocessing.resource_sharer • multiprocessing.spawn • multiprocessing.synchronize • multiprocessing.util

multiprocessing.queues SourceModule

imports: _multiprocessing • collections • errno • multiprocessing • multiprocessing.connection • multiprocessing.context • multiprocessing.synchronize • multiprocessing.util • os • queue • sys • threading • time • traceback • types • weakref

imported by: concurrent.futures.process • multiprocessing.context

multiprocessing.reduction SourceModule

imports: _winapi • abc • array • copyreg • functools • io • multiprocessing • multiprocessing.context • multiprocessing.resource_sharer • os • pickle • socket • sys

imported by: multiprocessing • multiprocessing.context

multiprocessing.resource_sharer SourceModule

imports: multiprocessing • multiprocessing.connection • multiprocessing.context • multiprocessing.process • multiprocessing.util • os • signal • socket • sys • threading

imported by: multiprocessing • multiprocessing.connection • multiprocessing.reduction

multiprocessing.resource_tracker SourceModule

imports: _multiprocessing • _posixshmem • multiprocessing • multiprocessing.spawn • multiprocessing.util • os • signal • sys • threading • warnings

imported by: multiprocessing • multiprocessing.forkserver • multiprocessing.managers • multiprocessing.popen_spawn_posix • multiprocessing.shared_memory • multiprocessing.spawn • multiprocessing.synchronize • multiprocessing.util

multiprocessing.set_start_method MissingModule

imported by: multiprocessing • multiprocessing.spawn

multiprocessing.shared_memory SourceModule

imports: _posixshmem • _winapi • errno • functools • mmap • multiprocessing • multiprocessing.resource_tracker • os • secrets • struct • types

imported by: multiprocessing • multiprocessing.managers

multiprocessing.sharedctypes SourceModule

imports: ctypes • multiprocessing • multiprocessing.context • multiprocessing.get_context • multiprocessing.heap • weakref

imported by: multiprocessing.context

multiprocessing.spawn SourceModule

imports: _winapi • msvcrt • multiprocessing • multiprocessing.context • multiprocessing.get_start_method • multiprocessing.process • multiprocessing.resource_tracker • multiprocessing.set_start_method • multiprocessing.util • os • runpy • sys • types

imported by: multiprocessing • multiprocessing.context • multiprocessing.forkserver • multiprocessing.popen_forkserver • multiprocessing.popen_spawn_posix • multiprocessing.popen_spawn_win32 • multiprocessing.resource_tracker • pyi_rth_multiprocessing.py

multiprocessing.synchronize SourceModule

imports: _multiprocessing • multiprocessing • multiprocessing.context • multiprocessing.heap • multiprocessing.process • multiprocessing.resource_tracker • multiprocessing.util • struct • sys • tempfile • threading • time

imported by: multiprocessing.context • multiprocessing.queues

multiprocessing.util SourceModule

imports: _posixsubprocess • atexit • itertools • logging • multiprocessing • multiprocessing.forkserver • multiprocessing.process • multiprocessing.resource_tracker • os • shutil • subprocess • sys • tempfile • threading • traceback • weakref

imported by: multiprocessing • multiprocessing.connection • multiprocessing.context • multiprocessing.forkserver • multiprocessing.heap • multiprocessing.managers • multiprocessing.pool • multiprocessing.popen_fork • multiprocessing.popen_forkserver • multiprocessing.popen_spawn_posix • multiprocessing.popen_spawn_win32 • multiprocessing.process • multiprocessing.queues • multiprocessing.resource_sharer • multiprocessing.resource_tracker • multiprocessing.spawn • multiprocessing.synchronize

netrc SourceModule

imports: os • pwd • shlex • stat

imported by: ftplib

nt (builtin module)

imported by: ctypes • importlib._bootstrap_external • ntpath • os • pathlib • shutil

ntpath SourceModule

imports: genericpath • nt • os • stat • string • sys

imported by: Ambiance_GUI.py • os • os.path • pathlib

nturl2path SourceModule

imports: string • urllib.parse

imported by: urllib.request

numbers SourceModule

imports: abc

imported by: _pydecimal • fractions • statistics

objc MissingModule

imported by: bleak.backends.corebluetooth • bleak.backends.corebluetooth.CentralManagerDelegate • bleak.backends.corebluetooth.PeripheralDelegate • bleak.backends.corebluetooth.scanner

opcode SourceModule

imports: _opcode

imported by: dis

operator SourceModule

imports: _operator • builtins • functools

imported by: Ambiance_GUI.py • collections • email._header_value_parser • fractions • importlib.metadata • inspect • pathlib • statistics • typing • typing_extensions

optparse SourceModule

imports: gettext • os • sys • textwrap

imported by: uu

org MissingModule

imported by: pickle

os SourceModule

imports: _collections_abc • abc • io • nt • ntpath • os.path • posix • posixpath • stat • subprocess • sys • warnings

imported by: Ambiance_GUI.py • argparse • asyncio.base_events • asyncio.coroutines • asyncio.events • asyncio.proactor_events • asyncio.unix_events • asyncio.windows_utils • bleak • bleak.backends.bluezdbus.client • bleak.backends.bluezdbus.manager • bleak.backends.bluezdbus.utils • bleak.backends.client • bleak.backends.scanner • bz2 • concurrent.futures.process • concurrent.futures.thread • configparser • ctypes • email.utils • fnmatch • genericpath • getopt • getpass • gettext • glob • gzip • http.cookiejar • importlib.metadata • inspect • linecache • locale • logging • lzma • mimetypes • multiprocessing.connection • multiprocessing.context • multiprocessing.forkserver • multiprocessing.heap • multiprocessing.managers • multiprocessing.pool • multiprocessing.popen_fork • multiprocessing.popen_forkserver • multiprocessing.popen_spawn_posix • multiprocessing.popen_spawn_win32 • multiprocessing.process • multiprocessing.queues • multiprocessing.reduction • multiprocessing.resource_sharer • multiprocessing.resource_tracker • multiprocessing.shared_memory • multiprocessing.spawn • multiprocessing.util • netrc • ntpath • optparse • os.path • pathlib • pkgutil • platform • posixpath • py_compile • pyi_rth__tkinter.py • pyi_rth_inspect.py • random • runpy • serial • serial.serialposix • serial.tools.list_ports • serial.tools.list_ports_common • serial.tools.list_ports_linux • serial.tools.list_ports_posix • shlex • shutil • socket • ssl • subprocess • tarfile • tempfile • threading • tkinter • tkinter.filedialog • tkinter.ttk • urllib.request • uu • uuid • winrt.runtime._internals • xml.sax • xml.sax.saxutils • zipfile • zipimport

os.path AliasNode

imports: ntpath • os

imported by: os • pkgutil • py_compile • serial.tools.list_ports_common • tracemalloc

pathlib SourceModule

imports: _collections_abc • errno • fnmatch • functools • grp • io • nt • ntpath • operator • os • posixpath • pwd • re • stat • sys • urllib.parse

imported by: importlib.metadata • winrt.runtime._internals • zipimport

pep517 MissingModule

imported by: importlib.metadata

pickle SourceModule

imports: _compat_pickle • _pickle • codecs • copyreg • functools • io • itertools • org • pprint • re • struct • sys • types

imported by: logging • multiprocessing.reduction • tracemalloc

pkgutil SourceModule

imports: collections • functools • importlib • importlib.machinery • importlib.util • inspect • marshal • os • os.path • re • sys • types • warnings • zipimport

imported by: pyi_rth_pkgutil.py • runpy

platform SourceModule

imports: 'java.lang' • _winreg • collections • functools • itertools • java • os • re • socket • struct • subprocess • sys • vms_lib • winreg

imported by: bleak.backends.client • bleak.backends.scanner • uuid

posix MissingModule

imports: resource

imported by: importlib._bootstrap_external • os • shutil

posixpath SourceModule

imports: genericpath • os • pwd • re • stat • sys

imported by: Ambiance_GUI.py • fnmatch • importlib.metadata • mimetypes • os • pathlib • urllib.request • zipfile

pprint SourceModule

imports: collections • io • re • sys • time • types

imported by: pickle

pwd MissingModule

imported by: getpass • netrc • pathlib • posixpath • shutil • subprocess • tarfile

py_compile SourceModule

imports: enum • importlib._bootstrap_external • importlib.machinery • importlib.util • os • os.path • sys • traceback

imported by: zipfile

pyexpat C:\Program Files\WindowsApps\PythonSoftwareFoundation.Python.3.9_3.9.3568.0_x64__qbz5n2kfra8p0\DLLs\pyexpat.pyd

imported by: xml.parsers.expat

pyimod02_importers MissingModule

imported by: pyi_rth_pkgutil.py

queue SourceModule

imports: _queue • collections • heapq • threading • time • types

imported by: concurrent.futures.process • concurrent.futures.thread • multiprocessing.dummy • multiprocessing.dummy.connection • multiprocessing.managers • multiprocessing.pool • multiprocessing.queues

quopri SourceModule

imports: binascii • getopt • io • sys

imported by: email.encoders • email.message • encodings.quopri_codec

random SourceModule

imports: _collections_abc • _random • _sha512 • bisect • hashlib • itertools • math • os • statistics • time • warnings

imported by: email.generator • email.utils • secrets • statistics • tempfile • uuid

re SourceModule

imports: _locale • copyreg • enum • functools • sre_compile • sre_constants • sre_parse

imported by: Ambiance_GUI.py • _pydecimal • _sre • _strptime • argparse • base64 • bleak.backends.bluezdbus.signals • bleak.backends.bluezdbus.version • configparser • csv • email._encoded_words • email._header_value_parser • email.feedparser • email.generator • email.header • email.message • email.policy • email.quoprimime • email.utils • encodings.idna • fnmatch • fractions • ftplib • gettext • glob • http.client • http.cookiejar • importlib.metadata • inspect • locale • logging • pathlib • pickle • pkgutil • platform • posixpath • pprint • serial.tools.list_ports • serial.tools.list_ports_common • serial.tools.list_ports_windows • shlex • string • tarfile • textwrap • tkinter • tokenize • typing • urllib.parse • urllib.request • warnings

reprlib SourceModule

imports: _thread • builtins • itertools

imported by: Ambiance_GUI.py • asyncio.base_futures • asyncio.format_helpers • collections • functools

resource MissingModule

imported by: posix

runpy SourceModule

imports: importlib.machinery • importlib.util • io • os • pkgutil • sys • types • warnings

imported by: multiprocessing.spawn

secrets SourceModule

imports: base64 • binascii • hmac • random

imported by: multiprocessing.shared_memory

select C:\Program Files\WindowsApps\PythonSoftwareFoundation.Python.3.9_3.9.3568.0_x64__qbz5n2kfra8p0\DLLs\select.pyd

imported by: selectors • serial.serialposix • subprocess

selectors SourceModule

imports: abc • collections • collections.abc • math • select • sys

imported by: asyncio.selector_events • asyncio.unix_events • multiprocessing.connection • multiprocessing.forkserver • socket • subprocess

serial Package

imports: __future__ • importlib • os • serial.serialcli • serial.serialjava • serial.serialposix • serial.serialutil • serial.serialwin32 • serial.win32 • sys

imported by: Ambiance_GUI.py • serial.serialcli • serial.serialjava • serial.serialposix • serial.serialutil • serial.serialwin32 • serial.tools • serial.tools.list_ports_posix • serial.tools.list_ports_windows • serial.win32

serial.serialcli SourceModule

imports: 'System.IO' • System • __future__ • serial • serial.serialutil

imported by: serial

serial.serialjava SourceModule

imports: __future__ • serial • serial.serialutil

imported by: serial

serial.serialposix SourceModule

imports: __future__ • array • errno • fcntl • os • select • serial • serial.serialutil • struct • sys • termios • warnings

imported by: serial

serial.serialutil SourceModule

imports: __future__ • array • io • serial • sys • time

imported by: serial • serial.serialcli • serial.serialjava • serial.serialposix • serial.serialwin32

serial.serialwin32 SourceModule

imports: __future__ • ctypes • serial • serial.serialutil • serial.win32 • time

imported by: serial

serial.tools Package

imports: serial • serial.tools.list_ports_common

imported by: serial.tools.list_ports • serial.tools.list_ports_common • serial.tools.list_ports_linux • serial.tools.list_ports_osx • serial.tools.list_ports_posix • serial.tools.list_ports_windows

serial.tools.list_ports SourceModule

imports: __future__ • argparse • os • re • serial.tools • serial.tools.list_ports_posix • serial.tools.list_ports_windows • sys

imported by: Ambiance_GUI.py

serial.tools.list_ports_common SourceModule

imports: __future__ • glob • os • os.path • re • serial.tools

imported by: serial.tools • serial.tools.list_ports_linux • serial.tools.list_ports_osx • serial.tools.list_ports_posix • serial.tools.list_ports_windows

serial.tools.list_ports_linux SourceModule

imports: __future__ • glob • os • serial.tools • serial.tools.list_ports_common

imported by: serial.tools.list_ports_posix

serial.tools.list_ports_osx SourceModule

imports: __future__ • ctypes • serial.tools • serial.tools.list_ports_common

imported by: serial.tools.list_ports_posix

serial.tools.list_ports_posix SourceModule

imports: __future__ • glob • os • serial • serial.tools • serial.tools.list_ports_common • serial.tools.list_ports_linux • serial.tools.list_ports_osx • sys

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

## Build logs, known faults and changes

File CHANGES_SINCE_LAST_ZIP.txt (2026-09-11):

Ambiance - changes since ambiance_changes_latest.zip
(that zip covered: Scheduler.h, Scheduler.c, main.c, Ambiance_GUI.py,
 up through the boot-marker / reset-cause work)

UNCHANGED since that zip:
- main.c
- Scheduler.h

Scheduler.c
- Added a guard so CompareTime() returns early when day/month read as 0
  (the RTC's power-on default), which stops bogus "Month 00 Day 00" log
  entries from ever being written.
- Removed an unnecessary `curschedule != -1` gate on the broadcast check,
  which was the actual cause of genuine active playback sometimes being
  logged as "unresponsive" instead of "Broadcast."
- (A temporary RTC debug print was added mid-session to diagnose a
  logging-stall report, then fully removed again after it turned out to
  corrupt in-flight log downloads by writing into the same BLE stream.
  Net effect on this file is just the two fixes above.)

FLASH.c / FLASH.h
- New: FLASH_ClearLogs() - erases the log flash region and resets
  LogsSize, backing the new Clear Device Log button.
- (It briefly ended up defined twice from an editing slip, which broke
  the build; the duplicate was found and removed.)

COMM.c
- New protocol command CLEARLOGS (0x08) - invokes FLASH_ClearLogs() and
  replies with a success byte, mirroring the existing Clear Device
  Schedule flow.
- New protocol command TIMEREQUEST (0x10) - read-only diagnostic that
  replies with the device's current month/day/hour/minute, added to
  confirm the RTC's live state without racing an in-progress transfer.

usart.c / usart_app.c
- BLE transfer size widened from 1 byte to 20 bytes per exchange for
  speed, with the variable-length GATT flag and chunked read/write
  handling updated to match.

app_ble.c (new file touched this round)
- Per-unit BLE device name tag widened from 4 hex digits (16 bits) to 6
  hex digits (24 bits), after two physical units were confirmed to have
  collided on the same 4-digit tag. The first 4 digits are deliberately
  preserved so old and new names overlap predictably.

Ambiance_GUI.py
- Added Clear Device Schedule and Clear Device Log buttons.
- Added a Check Time button plus a "skip auto time sync" diagnostic
  checkbox, to query/confirm the device's RTC state directly.
- Added a BLE operation lock, fixing real concurrency-caused disconnects
  from overlapping BLE operations.
- Fixed several Python closure/late-binding bugs that were producing
  misleading (but not data-affecting) debug console output.
- Fixed a log-download truncation bug that the BLE transfer-size increase
  had introduced.
- Log filenames now include the date and device name.
- Layout reworked: Scan for Devices / Connect / Disconnect consolidated
  onto one row; Force Time Sync (and the skip-auto-sync checkbox) moved
  next to the connection controls; the Clear Output button removed;
  log/status buttons rearranged two-per-row (Download Device Log / Clear
  Device Log, then Check Device Status / Check Device Time); and the
  volume and duty-cycle sliders widened so exact values like 20, 30, 70
  are reliably clickable.

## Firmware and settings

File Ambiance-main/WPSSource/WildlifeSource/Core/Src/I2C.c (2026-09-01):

/*
 * Name I2C.c
 * Brief: provides a library to initialize and access the MCU's I2C hardware
 * Author: Caitlin Bonesio
 * Created: 3/4/25
 * Modified: 4/23/25
 */

//----------------------------------------Private Includes---------------------------------------
#include "I2C.h"
#include "BOARD.h"
#include "stdbool.h"
#include "I2C-UART_Manager.h"
#include "TIMERS.h"
#include "OledDriver.h"
//----------------------------------------Private Defines----------------------------------------

#define CIRCBUFFERSIZE 1536//Slightly less than 1.5 OLED prints

#define I2CBUFFERTIMEOUT 1000 // number of millisecond I2C transmit will wait for a spot in the buffer to appear


//#define I2CTESTHARNESS
//----------------------------------------Private Typedefs---------------------------------------
typedef struct MemAdd{//memory address packet, used for both reading and writing memory operations
	uint8_t targetadr;
	uint8_t registeradr;
	uint8_t data;
	uint8_t posterindex;
}MemAdd_t;

typedef struct MemAddBuffer{
	MemAdd_t data[CIRCBUFFERSIZE];
	uint16_t head;
	uint16_t tail;
}MemAddBuffer_t;

//----------------------------------------Private Variables--------------------------------------

I2C_HandleTypeDef hi2c1 = {I2C1};
void (*PosterList[NUMPOSTERS])(Event_t event) = POSTERS;
static MemAddBuffer_t MemBuff;//Receive and transmit request

static uint8_t initialized = 0;


//----------------------------------------Private functions--------------------------------------
#ifdef I2CTESTHARNESS
void fakeposter(Event_t event);
#endif
HAL_StatusTypeDef I2C_Post(MemAdd_t* post){
	if(post->posterindex == 0){
		return HAL_I2C_Mem_Write_IT(&hi2c1,
									post->targetadr<<1,
									post->registeradr,
									I2C_MEMADD_SIZE_8BIT,
									&(post->data),
									1);
	} else {
		return HAL_I2C_Mem_Read_IT(&hi2c1,
								   post->targetadr<<1,
								   post->registeradr,
								   I2C_MEMADD_SIZE_8BIT,
								   &(post->data),
								   1);

	}
}

HAL_StatusTypeDef I2C_Enqueue(MemAdd_t Post){
	if(!initialized){return HAL_ERROR;}
		HAL_StatusTypeDef status = HAL_OK;

		uint32_t start = TIMERS_GetMilliSeconds();
		/* rollover-safe: TIMERS_GetMilliSeconds() wraps every ~49.7 days;
		 * "start + I2CBUFFERTIMEOUT > now" breaks right at that wrap and can
		 * bail out of the wait immediately. (uint32_t)(now - start) wraps
		 * correctly the same way the rest of this codebase already does it
		 * (see Scheduler.c/MP3.c). */
		while((MemBuff.tail == ((MemBuff.head+1)%CIRCBUFFERSIZE)) && ((uint32_t)(TIMERS_GetMilliSeconds() - start) < I2CBUFFERTIMEOUT));
		if(MemBuff.tail == (MemBuff.head+1)%CIRCBUFFERSIZE){
			BSP_LED_On(LED_RED);//indicate a fatal buffer overflow
			return HAL_ERROR;
		}
		BSP_LED_Off(LED_RED);
		//place the transmit request into the buffer
		//The I2C-UARTmanager will disable the module but leave the state as ready, the data will still be loaded into the register
		//The module will not transmit until arbitration is complete


		MemBuff.data[MemBuff.head] = Post;
		MemBuff.head++;
		MemBuff.head %= CIRCBUFFERSIZE;
		if((MemBuff.tail+1)%CIRCBUFFERSIZE == MemBuff.head && hi2c1.State == HAL_I2C_STATE_READY){
			I2CUARTtoI2C(1);
			status = I2C_Post(MemBuff.data+MemBuff.tail);

		}
		return status;
}

/*
 * @Function: HAL_I2C_MemTxCpltCallback
 * @Brief: Overwrites a weak HAL function. Called at the end of an i2c memory transmit operation
 * @param: hi2c: I2C module that is in use
 * @return: none
 */
void HAL_I2C_MemTxCpltCallback(I2C_HandleTypeDef *hi2c){
	//operation complete, the data at tail is now out-dated;
	MemBuff.tail++;
	MemBuff.tail %= CIRCBUFFERSIZE;
	//if there is more in the buffer
	if(MemBuff.tail != MemBuff.head){
		I2CUARTtoI2C(1);
		I2C_Post(MemBuff.data+MemBuff.tail);

	}
}


/*
 * @Function: HAL_I2C_MemRxCpltCallback
 * @Brief: Overwrites a weak HAL function. Called at the end of an i2c memory receive operation
 * @param: hi2c: I2C module that is in use
 * @return: none
 */
void HAL_I2C_MemRxCpltCallback(I2C_HandleTypeDef *hi2c){

	//use the received data construct and event to post
	Event_t ret = {EVENT_I2C, MemBuff.data[MemBuff.tail].registeradr << 8 | MemBuff.data[MemBuff.tail].data};
	//post the event to the function given by the poster index

#ifdef I2CTESTHARNESS
	fakeposter(ret);
#else
	PosterList[MemBuff.data[MemBuff.tail].posterindex-1](ret);
#endif
	//operation complete, the data at tail is now out-dated;
	MemBuff.tail++;
	MemBuff.tail %= CIRCBUFFERSIZE;
	//if there is more in the buffer
	if(MemBuff.tail != MemBuff.head){
		I2CUARTtoI2C(1);
		I2C_Post(MemBuff.data+MemBuff.tail);

	}
}

void HAL_I2C_ErrorCallback(I2C_HandleTypeDef *hi2c){
	if(hi2c->ErrorCode&HAL_I2C_ERROR_AF){//NACK Error
		if(MemBuff.tail != MemBuff.head){
			uint32_t start = TIMERS_GetMilliSeconds();
			while(start+10 > TIMERS_GetMilliSeconds());
			I2CUARTtoI2C(1);
			I2C_Post(MemBuff.data+MemBuff.tail);//Repost the same data packet that got NACKed, without moving the tail forward

		}
	}
}
/*
 * @Function:I2C1_IRQHandler
 * @Brief: Overwrites a weak HAL function. handles I2C1 interrupts
 * @param: none
 * @return: none
 */
void I2C1_IRQHandler(void)
{
	if (hi2c1.Instance->ISR & (I2C_FLAG_BERR | I2C_FLAG_ARLO | I2C_FLAG_OVR))
	{
		HAL_I2C_ER_IRQHandler(&hi2c1);//error handler
	}
	else
	{
		HAL_I2C_EV_IRQHandler(&hi2c1);//event handler
	}
}

//----------------------------------------Public Functions---------------------------------------

/*
 * @function: I2C_Init()
 * @brief: initialize the I2C peripheral to receive and transmit
 * @param: none
 * @return: Init Status, whether the operation failed or succeeded
 */
int I2C_Init(void){
	if(initialized){return INIT_OK;}
	TIMERS_Init();
	hi2c1.Instance = I2C1;
	hi2c1.Init.Timing = 0x00305B5B;
	hi2c1.Init.OwnAddress1 = 0;
	hi2c1.Init.AddressingMode = I2C_ADDRESSINGMODE_7BIT;
	hi2c1.Init.DualAddressMode = I2C_DUALADDRESS_DISABLE;
	hi2c1.Init.OwnAddress2 = 0;
	hi2c1.Init.OwnAddress2Masks = I2C_OA2_NOMASK;
	hi2c1.Init.GeneralCallMode = I2C_GENERALCALL_DISABLE;
	hi2c1.Init.NoStretchMode = I2C_NOSTRETCH_DISABLE;
	hi2c1.State = HAL_I2C_STATE_RESET;
	HAL_StatusTypeDef ret = HAL_I2C_Init(&hi2c1);
	if (ret != HAL_OK)
	{
		return INIT_ERROR;
	}
	// Configure Analog filter
	ret = HAL_I2CEx_ConfigAnalogFilter(&hi2c1, I2C_ANALOGFILTER_ENABLE);
	if (ret != HAL_OK)
	{
		return INIT_ERROR;
	}

	// Configure Digital filter
	ret = HAL_I2CEx_ConfigDigitalFilter(&hi2c1, 0);
	if (ret != HAL_OK)
	{
		return INIT_ERROR;
	}
	//set up circular buffers
	MemBuff.tail = 0;
	MemBuff.head = 0;
	initialized = 1;
	I2CUARTtoI2C(1);
	//enables interrupts
	HAL_NVIC_SetPriority(I2C1_IRQn, 2, 0);
	HAL_NVIC_EnableIRQ(I2C1_IRQn);
	return INIT_OK;
}

/*
 * @Function: I2C_Transmit
 * @Brief: Gives access to transmit a byte
 * @param: uint8_t targetadr: Address of the device to communicate
 * 		   uint8_t registeradr: Address of the register to write to
 * 		   uint8_t data: to to be transmitted
 * @return: a flag if the data has been transmitted
 */
HAL_StatusTypeDef I2C_Transmit(uint8_t targetadr, uint8_t registeradr, uint8_t data){
	if(!initialized){return HAL_ERROR;}
	HAL_StatusTypeDef status = HAL_OK;
	static MemAdd_t Post;
	Post.targetadr = targetadr;
	Post.registeradr = registeradr;
	Post.posterindex = 0;//null pointer, no function is posted to after the transmit is complete
	Post.data = data;
	status = I2C_Enqueue(Post);
	return status;
}

void I2C_Flushbuffer(){
	if(hi2c1.State == HAL_I2C_STATE_READY && MemBuff.tail != MemBuff.head){
		//error recovery
		I2C_Post(MemBuff.data+MemBuff.tail);
	}
}
/*
 * @Function: I2C_Recieve
 * @Brief: transmits requesting data. when the data is received it posts an event with the data to the PostTo function
 * @param: uint8_t targetadr: Address of the device to communicate
 * 		   uint8_t registeradr: Address of the register to read from
 * 		   void (*PostTo)(Event_t): which service to post to when the data is received
 * @return: -1 if error, 1 if success
 */
HAL_StatusTypeDef I2C_Recieve(uint8_t targetadr, uint8_t registeradr, uint8_t posterindex){
	if(!initialized){return HAL_ERROR;}
	HAL_StatusTypeDef status = HAL_OK;
	static MemAdd_t Post;
	Post.targetadr = targetadr;
	Post.registeradr = registeradr;
	if(posterindex == 0 || posterindex > NUMPOSTERS){
		return HAL_ERROR;
	}
	Post.posterindex = posterindex;
	Post.data = 0;//will store future recieved data
	status = I2C_Enqueue(Post);
	return status;

}

/** I2C_WriteReg(I2CAddress, deviceRegisterAddress, data)
 *
 * Writes one device register on chosen I2C device.
 *
 * @param   I2CAddress              (unsigned char) 7-bit address of I2C device
 *                                                  wished to interact with.
 * @param   deviceRegisterAddress   (unsigned char) 8-bit address of register on
 *                                                  device.
 * @param   data                    (uint8_t)       Data wished to be written to
 *                                                  register.
 * @return                          (unsigned char) [SUCCESS, ERROR]
 */
unsigned char I2C_WriteReg(
    unsigned char I2CAddress,
    unsigned char deviceRegisterAddress,
    uint8_t data
)
{
    HAL_StatusTypeDef ret;
//    I2CAddress = I2CAddress << 1; // Use 8-bit address.
//
//    ret = HAL_I2C_Mem_Write(
//        &hi2c1,
//        I2CAddress,
//        deviceRegisterAddress,
//        I2C_MEMADD_SIZE_8BIT,
//        &data,
//        1,
//        HAL_MAX_DELAY
//    );
    ret = I2C_Transmit(I2CAddress, deviceRegisterAddress, data);
    if (ret != HAL_OK)
    {
        return ERROR;
    }

    return SUCCESS;
}


//----------------------------------------Private Test Harness-----------------------------------
//#define is at the top of the page
#ifdef I2CTESTHARNESS
#include "BOARD.h"
#include "Oled.h"
#include "DiscountIO.h"
#include "UART.h"
#include "TIMERS.h"

HAL_StatusTypeDef status;
uint8_t month;
uint8_t day;
uint8_t hour;
uint8_t minute;
uint8_t stat;
uint8_t start;

void fakeposter(Event_t event){
	if(event.status == EVENT_I2C){
		switch (event.data>>8){
		case RTCMNTHADDR:
			month = ((event.data & 0x10)>>4)*10 + (event.data & 0x0F);
			break;
		case RTCDAYADDR:
			day = ((event.data & 0x30)>>4)*10 + (event.data & 0x0F);
			break;
		case RTCHOURADDR:
			if(event.data & 0x40){//AM/PM
				hour = 12*((event.data &0x20)>>5)+ 10*((event.data &0x10)>>4) + ((event.data &0x0F));
			}else {//24Hr
				hour = 10*((event.data &0x30)>>4) + ((event.data &0x0F));
			}
			break;
		case RTCMINADDR:
			//MINTEN2 MINTEN1 MINTEN0 MINONE3 MINONE2 MINONE1 MINONE0
			minute = 10*((event.data & 0x70)>>4) +((event.data &0x0F));

			break;
		case RTCSTATADDR:
			stat = event.data;
			break;
		case RTCSECADDR:
			start = event.data>>7;
			break;
		}
	}
	return;
}

int main(){

	BOARD_Init();
	TIMERS_Init();
	BSP_LED_Init(LED_BLUE);
	BSP_LED_Init(LED_RED);
	I2C_Init();
	I2C_Transmit(RTCADDRESS, RTCSECADDR, 0x80);
	I2C_Transmit(RTCADDRESS, RTCSTATADDR, 0x08);
//	I2C_Transmit(RTCADDRESS, RTCSECADDR, 0x00);
//	I2C_Transmit(RTCADDRESS, RTCSTATADDR, 0x00);

	I2C_Transmit(RTCADDRESS, RTCMINADDR, 0x16);
	I2C_Transmit(RTCADDRESS, RTCHOURADDR, 0x10);
	I2C_Transmit(RTCADDRESS, RTCDAYADDR, 0x28);
	I2C_Transmit(RTCADDRESS, RTCMNTHADDR, 0x08);
	HAL_Delay(100);
	OledInit();
	HAL_Delay(1000);
	while (1){
		if(TIMERS_GetMilliSeconds()%500 == 0){
			I2C_Recieve(RTCADDRESS, RTCDAYADDR, 1);
			I2C_Recieve(RTCADDRESS, RTCHOURADDR, 1);
			I2C_Recieve(RTCADDRESS, RTCMINADDR, 1);
			I2C_Recieve(RTCADDRESS, RTCMNTHADDR, 1);
			I2C_Recieve(RTCADDRESS, RTCSECADDR, 1);
			I2C_Recieve(RTCADDRESS, RTCSTATADDR, 1);

			char text[88];
			sprintf(text, "current time:\n"
						  "%d/%d %d:%.2d\n"
						  "status: %X, start: %d", month, day, hour, minute, stat, start);
			OledDrawString(text);
			OledUpdate();
		}


	}

}
#endif

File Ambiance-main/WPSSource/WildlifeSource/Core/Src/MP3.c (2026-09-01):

/*
 * Name: MP3.c
 * Brief: DFPlayer/MP3 module for event/service framework.
 * Author: Caitlin Bonesio, Simon Nakarmi
 * Created: 4/19/25
 * Modified: 2/3/26
 *
 * Notes:
 * - Communicates with the MP3 module over LPUART using DFPlayer-style packets.
 * - Maintains a simple duty-cycle “play then pause” behavior based on FLASH duty cycle.
 * - Randomizes next track on “song complete” (0x3D), with basic debounce.
 * - Includes defensive recovery if “song complete” is never received.
 */

//----------------------------------------Private Includes---------------------------------------
#include "CONFIG.h"
#include "MP3.h"
#include "TIMERS.h"
#include "FLASH.h"
#include "UART.h"
#include "Scheduler.h"
#include "discountIO.h"
#include "FIFO.h"
#include <limits.h>

#include <stdio.h>
#include <string.h>
#include <stdlib.h>

//----------------------------------------Private Defines----------------------------------------
#define CYCLELENGTH (10/*minutes*/*60000/*milliseconds/minute*/) // duty cycle window (ms)
#define RESETTIMER 2000
#define FAILEDTRACKRECOVERY (2/*minutes*/*60000/*milliseconds/minute*/)
#define DEFAULT_VOLUME 30 // startup volume (0-100 mapped to DFPlayer 0-30)

//----------------------------------------Private Typedefs---------------------------------------
typedef enum DFPacketStates{
    Start,
    Version,
    Length,
    Command,
    Ack,
    Param1,
    Param2,
    Checksum1,
    Checksum2,
} DFPacketState_t;

typedef struct DFPacket{
    uint8_t command;
    uint8_t ack;
    uint8_t Param1;
    uint8_t Param2;
} DFPacket_t;

typedef enum DFinitSM{
    setup,
    scanning,
} DFinitSM_t;

//----------------------------------------Private Variables--------------------------------------
extern RNG_HandleTypeDef hrng;
FIFO MP3queue;

/*
 * pause meanings:
 *   0x00: actively playing / allowed to play
 *   0x01: duty-cycle pause (resume after computed pause time)
 *   0x02: stopped until next explicit play event
 */
static uint8_t pause;
static uint8_t DC;        // duty cycle percentage (clamped to 1..100)
static uint8_t volume;    // 0..100 (mapped to DFPlayer range)

static uint32_t starttime;    // watchdog / track start reference for recovery
static uint32_t endtime;      // time we paused (or track ended)

static uint32_t inittime;
static uint8_t initialized;
static DFinitSM_t initSM;
static uint8_t df_error_retries = 0;

static DFPacketState_t PacketSM;
static DFPacket_t Packet;

static uint8_t track;
static uint8_t folder;
static uint16_t firsttrack;
static uint8_t nexttrack;
static uint8_t lastplayed;
static uint8_t lasttrack = 0;
static uint8_t* folders;
static uint8_t numfolders;
static uint32_t last_complete_ms = 0;

static char lastsent[4];
static uint32_t track_start_ms = 0;

//----------------------------------------Private Functions--------------------------------------

/**
 * @brief Send a single DFPlayer command packet.
 *
 * Packet format:
 *   0x7E, 0xFF, 0x06, [cmd, ack, p1, p2], [checksum_hi, checksum_lo], 0xEF
 *
 * @param string 4-byte payload: {command, ack, Param1, Param2}
 */
void MP3_SendData(char string[4]){
    uint16_t accumulation = 0;

    /* Optional LED instrumentation. Remove if you want zero side effects. */
    if ((uint8_t)string[0] == 0x03) {          // play absolute
        BSP_LED_Toggle(LED_RED);
    } else if ((uint8_t)string[0] == 0x0D) {   // play
        BSP_LED_Toggle(LED_BLUE);
    }

    LPUART_WriteTx(0x7E);         // start
    accumulation += 0xFF;
    LPUART_WriteTx(0xFF);         // version
    accumulation += 0x06;
    LPUART_WriteTx(0x06);         // length

    for (int i = 0; i < 4; i++) {
        accumulation += (uint8_t)string[i];
        lastsent[i] = string[i];
        LPUART_WriteTx((uint8_t)string[i]);
    }

    accumulation = (uint16_t)(-((int16_t)accumulation)); // checksum
    LPUART_WriteTx((uint8_t)(accumulation >> 8));
    LPUART_WriteTx((uint8_t)(accumulation & 0xFF));
    LPUART_WriteTx(0xEF);         // end
}

/**
 * @brief Play a track by absolute index (1-based indexing expected by module).
 * @param index16 Absolute track index.
 */
static void MP3_PlayAbsolute(uint16_t index16){
    char send[4] = {
        0x03,
        0x00,
        (char)((index16 >> 8) & 0xFF),
        (char)(index16 & 0xFF)
    };
    MP3_SendData(send);
}

/**
 * @brief Parse incoming UART stream into DFPlayer packets.
 *
 * Behavior:
 * - Returns 1 when a full valid packet is received and Packet fields are populated.
 * - Returns 0 otherwise.
 * - Resynchronizes on start flag and checksum mismatch.
 * - Special handling for 0x40 error packets:
 *     - If Param2 == 0x04 (bad track), retry last command up to 3 times.
 *     - After retries, converts the condition into a synthetic "song complete" (0x3D)
 *       so the upper layer can advance.
 *
 * @param rx Next byte from UART.
 * @return 1 if packet completed, else 0.
 */
uint8_t parsePacket(char rx){
    if (rx == UARTFAILED) {
        return 0;
    }

    if ((uint8_t)rx == 0x7E) {
        PacketSM = Start;
    }

    switch (PacketSM) {
    case Start:
        if ((uint8_t)rx == 0xFF) {
            PacketSM = Version;
        }
        break;

    case Version:
        if ((uint8_t)rx == 0x06) {
            PacketSM = Length;
        } else {
            PacketSM = Start;
        }
        break;

    case Length:
        PacketSM = Command;
        Packet.command = (uint8_t)rx;
        break;

    case Command:
        if ((uint8_t)rx == 0x01 || (uint8_t)rx == 0x00) {
            Packet.ack = (uint8_t)rx;
            PacketSM = Ack;
        } else {
            PacketSM = Start;
        }
        break;

    case Ack:
        PacketSM = Param1;
        Packet.Param1 = (uint8_t)rx;
        break;

    case Param1:
        PacketSM = Param2;
        Packet.Param2 = (uint8_t)rx;
        break;

    case Param2: {
        uint16_t checkval = (uint16_t)(-(0x105 + Packet.command + Packet.ack + Packet.Param1 + Packet.Param2));
        if ((uint8_t)rx == (uint8_t)(checkval >> 8)) {
            PacketSM = Checksum1;
        } else {
            PacketSM = Start;
        }
        break;
    }

    case Checksum1: {
        uint16_t checkval = (uint16_t)(-(0x105 + Packet.command + Packet.ack + Packet.Param1 + Packet.Param2));
        if ((uint8_t)rx == (uint8_t)(checkval & 0xFF)) {
            PacketSM = Checksum2;
        } else {
            PacketSM = Start;
        }
        break;
    }

    case Checksum2:
        if ((uint8_t)rx == 0xEF) {
            if (Packet.command == 0x40) {
                BSP_LED_Toggle(LED_RED);
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

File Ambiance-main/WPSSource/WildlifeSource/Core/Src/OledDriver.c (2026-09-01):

/*
 * File:   OledDriver.c
 * Author: Adam Korycki
 *
 * Support library for main Oled driver (Oled.c/h). 
 * I2C level interface for SSD1306 Oled module.
 * 
 * Created on November 6, 2023
 */

#include <stdio.h>
#include <stdlib.h>
#include <stdint.h>
#include <Board.h>
#include <I2C.h>
#include <OledDriver.h>
#include <timers.h>

#define OLED_ADDRESS 0x3C // I2C address for Oled device

/**
 * Constants for the various transmission types
 */
  #define COMMAND           0x80  // Continuation bit=1, D/C=0; 1000 0000
  #define COMMAND_STREAM    0x00  // Continuation bit=0, D/C=0; 0000 0000
  #define DATA              0xC0  // Continuation bit=1, D/C=1; 1100 0000
  #define DATA_STREAM       0x40  // Continuation bit=0, D/C=1; 0100 0000

/**
 * Constants for the various command values that can be sent to the OLED driver.
 */
typedef enum {
    OLED_COMMAND_SET_DISPLAY_LOWER_COLUMN_0 = 0x00,
    OLED_COMMAND_SET_DISPLAY_UPPER_COLUMN_0 = 0x10,
    OLED_COMMAND_SET_PAGE = 0x22,
    OLED_COMMAND_SET_CHARGE_PUMP = 0x8D,
    OLED_COMMAND_SET_SEGMENT_REMAP = 0xA1,
    OLED_COMMAND_DISPLAY_NORMAL = 0xA6,
    OLED_COMMAND_DISPLAY_INVERTED = 0xA7,
    OLED_COMMAND_MULTIPLEX_RATIO = 0xA8,
    OLED_COMMAND_DISPLAY_OFF = 0xAE,
    OLED_COMMAND_DISPLAY_ON = 0xAF,
	OLED_COMMAND_SET_OSC_FREQ = 0xD5,
    OLED_COMMAND_SET_PRECHARGE_PERIOD = 0xD9,
    OLED_COMMAND_SET_COM_PINS_CONFIG = 0xDA
} OledCommand;

/**
 * Store constants for all settings used with the OLED driver.
 */
typedef enum {
    OLED_SETTING_ENABLE_CHARGE_PUMP = 0x14,
	OLED_SETTING_OSC_FREQ = 0x80,
    OLED_SETTING_MULTIPLEX_RATIO = 0x3F,
    OLED_SETTING_MAXIMUM_PRECHARGE = 0xF1,
    OLED_SETTING_SEQUENTIAL_COM_NON_INTERLEAVED = 0x20,
    OLED_SETTING_REVERSE_ROW_ORDERING = 0xC8,
    OLED_SETTING_NORMAL_ROW_ORDERING = 0xC0
} OledSetting;

#define OLED_DRIVER_PAGES 8

/**
 * This array is the off-screen frame buffer used for rendering.
 * It isn't possible to read back from the OLED display device,
 * so display data is rendered into this off-screen buffer and then
 * copied to the display.
 * @note Any time this is updated, An `OledDriverUpdateDisplay()` call must be performed.
 */
uint8_t rgbOledBmp[OLED_DRIVER_BUFFER_SIZE];

// Function prototypes for private functions.
void DelayMs(uint32_t ms);

/**
 * Initialize the STM32 to communicate with the OLED display through the SSD1306
 * display controller using an instance of I2C.
 */
void OledHostInit(void)
{
    BOARD_Init(); // init board and printf functionality
    TIMERS_Init(); // init timer module for delay functions
    I2C_Init();   // init I2C module
}

/**
 * Initialize the OLED display and send init/config sequence
 */
void OledDriverInitDisplay(void)
{
    // Turn off the display.
    I2C_WriteReg(OLED_ADDRESS, COMMAND, OLED_COMMAND_DISPLAY_OFF);
    DelayMs(10);
//
//    I2C_WriteReg(OLED_ADDRESS, COMMAND, OLED_COMMAND_SET_OSC_FREQ);
//    I2C_WriteReg(OLED_ADDRESS, COMMAND, OLED_SETTING_OSC_FREQ);
//
    I2C_WriteReg(OLED_ADDRESS, COMMAND, OLED_COMMAND_MULTIPLEX_RATIO);
    I2C_WriteReg(OLED_ADDRESS, COMMAND, 0x3F);
//
    I2C_WriteReg(OLED_ADDRESS, COMMAND, 0xD3);//Display OFFSET
    I2C_WriteReg(OLED_ADDRESS, COMMAND, 0x08);

    I2C_WriteReg(OLED_ADDRESS, COMMAND, 0x40);//Set display start line
    I2C_WriteReg(OLED_ADDRESS, COMMAND, 0xA1);//Set segment re-map
    I2C_WriteReg(OLED_ADDRESS, COMMAND, 0xC0);//Set COM output Scan direction

    I2C_WriteReg(OLED_ADDRESS, COMMAND, 0xDA);//Set COM hardware config
    I2C_WriteReg(OLED_ADDRESS, COMMAND, 0x12);

//    I2C_WriteReg(OLED_ADDRESS, COMMAND, 0x81);//Set Contrast control
//    I2C_WriteReg(OLED_ADDRESS, COMMAND, 0xCF);
//
//    I2C_WriteReg(OLED_ADDRESS, COMMAND, 0xD9);//Set Precharge period
//    I2C_WriteReg(OLED_ADDRESS, COMMAND, 0xF1);
//
//    I2C_WriteReg(OLED_ADDRESS, COMMAND, 0xDB);//Set VCOMH deselect level
//    I2C_WriteReg(OLED_ADDRESS, COMMAND, 0x40);
//
//
//
    I2C_WriteReg(OLED_ADDRESS, COMMAND, 0xA4);//Set entire display on/off
    I2C_WriteReg(OLED_ADDRESS, COMMAND, 0xA6);//Set normal/inverted display


    // Enable the charge pump and
    I2C_WriteReg(OLED_ADDRESS, COMMAND, OLED_COMMAND_SET_CHARGE_PUMP);
    I2C_WriteReg(OLED_ADDRESS, COMMAND, OLED_SETTING_ENABLE_CHARGE_PUMP);
    I2C_WriteReg(OLED_ADDRESS, COMMAND, OLED_COMMAND_SET_PRECHARGE_PERIOD);
    I2C_WriteReg(OLED_ADDRESS, COMMAND, OLED_SETTING_MAXIMUM_PRECHARGE);

//    // Invert row numbering so that (0,0) is upper-right.
//    I2C_WriteReg(OLED_ADDRESS, COMMAND, OLED_COMMAND_SET_SEGMENT_REMAP);
//    I2C_WriteReg(OLED_ADDRESS, COMMAND, OLED_SETTING_NORMAL_ROW_ORDERING);
//
//    // Set sequential COM configuration with non-interleaved memory.
//    I2C_WriteReg(OLED_ADDRESS, COMMAND, OLED_COMMAND_SET_COM_PINS_CONFIG);
//    I2C_WriteReg(OLED_ADDRESS, COMMAND, OLED_SETTING_SEQUENTIAL_COM_NON_INTERLEAVED);

    // And turn on the display.
    I2C_WriteReg(OLED_ADDRESS, COMMAND, OLED_COMMAND_DISPLAY_ON);
}

/**
 * Set the LCD to display pixel values as the opposite of how they are actually stored in NVRAM. So
 * pixels set to black (0) will display as white, and pixels set to white (1) will display as black.
 */
void OledDriverSetDisplayInverted(void)
{

    I2C_WriteReg(OLED_ADDRESS, COMMAND, OLED_COMMAND_DISPLAY_INVERTED);
}

/**
 * Set the LCD to display pixel values normally, where a 1 indicates white and a 0 indicates black.
 * This is the default operating mode of the LCD and the mode it starts up in.
 */
void OledDriverSetDisplayNormal(void)
{
    I2C_WriteReg(OLED_ADDRESS, COMMAND, OLED_COMMAND_DISPLAY_NORMAL);
}

/**
 * Disable the Oled display before power-off.
 */
void OledDriverDisableDisplay(void)
{
    // Send the display off command.
    I2C_WriteReg(OLED_ADDRESS, COMMAND, OLED_COMMAND_DISPLAY_OFF);
}
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

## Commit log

2025-09-24 Calibrated Window Position
2026-05-06 changed how filter works
2026-09-11 Update wildlife firmware, GUI, docs, and assembly files
    [Ambiance Bracket.3mf, T-X6W979040A-40sets-BOM wildlife playback(2025-06-21).xls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]
